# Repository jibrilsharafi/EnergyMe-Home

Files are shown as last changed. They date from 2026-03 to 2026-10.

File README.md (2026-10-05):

#  EnergyMe-Home

<div align="center">

Coverage

<h3>🛒 Want it ready to use? Pre-assembled and calibrated units. Just install and monitor!</h3>

Available on our <a href="https://www.energyme.net/shop">website</a> and on <a href="https://www.tindie.com/stores/energyme/">Tindie</a>

   <a href="https://certification.oshwa.org/it000025.html">OSHWA Certified Open Source Hardware IT000025</a>

</div>

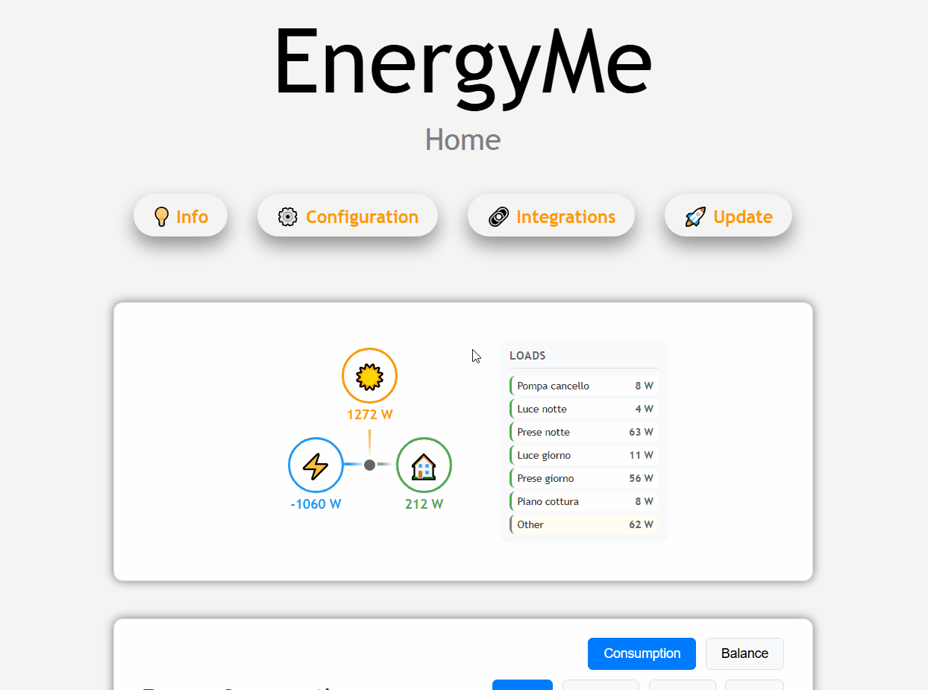
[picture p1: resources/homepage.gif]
Homepage


*EnergyMe-Home* is an open-source energy monitoring system for home use, capable of monitoring up to 16 circuits. It integrates with any platform through REST API, MQTT, Modbus TCP, and InfluxDB.

Built for makers and DIY enthusiasts who want to track their home's energy consumption. The hardware uses ESP32-S3 and ADE7953 energy measurement IC, while the firmware is written in C++ with PlatformIO and Arduino framework. You can build and customize it yourself - all hardware designs and software are open-source. Prefer it ready to go? Grab a [pre-assembled unit](https://www.energyme.net/shop).

> A demo speaks more than 1000 words: try the [demo dashboard](https://demo-energyme-home.energyme.net)!

> **Join the community!** Head over to [GitHub Discussions](https://github.com/jibrilsharafi/EnergyMe-Home/discussions) - ask questions, share your builds and dashboards, suggest features, and exchange integration tips. It's the home for everyone building, installing, or tinkering with EnergyMe-Home

## Supported Electrical Systems

EnergyMe-Home is compatible with various electrical systems worldwide:

| System Type | Voltage | Configuration | Supported |
|---|---|---|---|
| **Single Phase** | 230V | L + N | ✅ Europe, Asia, Africa, Oceania |
| **Split Phase** | 120V/240V | L1 + L2 + N | ✅ North America residential |
| **Split Phase** | 120V/240V | L1 + L2 (no N) | ✅ Old electrical systems |
| **Three Phase** | 400V/230V | 3L + N | ❕ Europe commercial/industrial (derived voltages) |
| **Three Phase** | 208V/120V | 3L + N | ❕ North America commercial (derived voltages) |

**Current Transformers Supported:**

- 333 mV output CTs (+- 500 mV absolute)
- 3.5 mm jack connectors for easy plug-and-play

**Monitoring Capacity:**

- Up to **16 circuits** simultaneously
- 1× main circuit, sampled at high frequency for accurate total energy measurement
- 15× branch circuits, multiplexed for individual monitoring

⚠️ **Important**: Installation requires working with your main electrical panel. Always consult a qualified electrician if you're not experienced with electrical installations. The user is responsible for ensuring compliance with local electrical codes and regulations, and assumes all risks associated with the installation and use of this device.

## Hardware

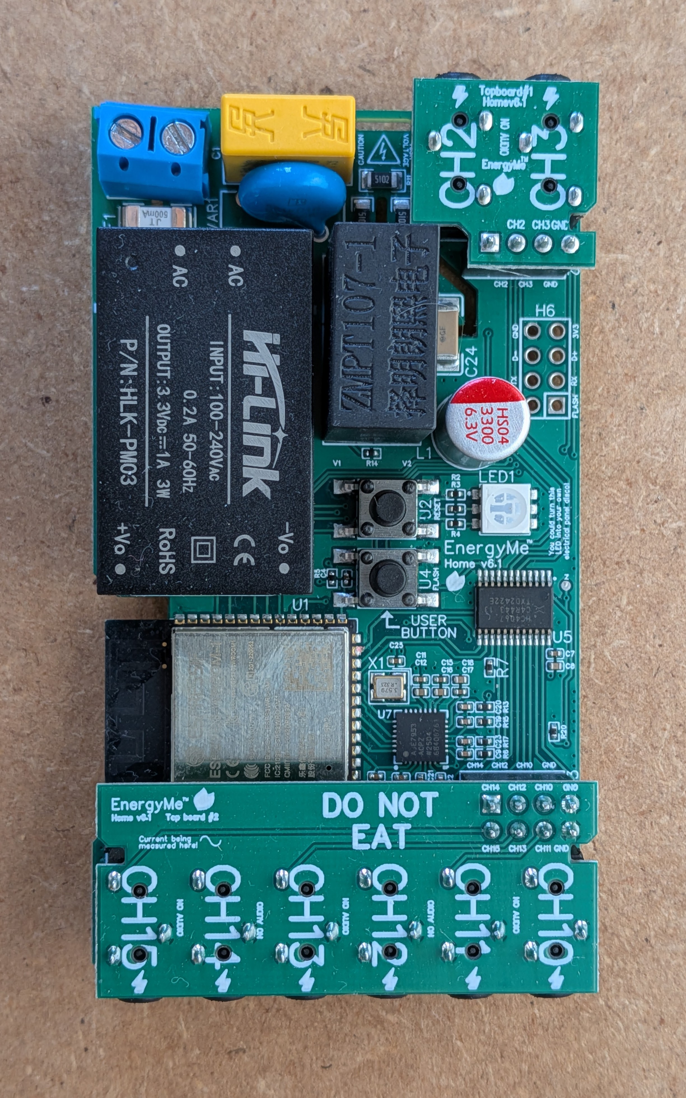
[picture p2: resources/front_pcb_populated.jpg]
PCB front

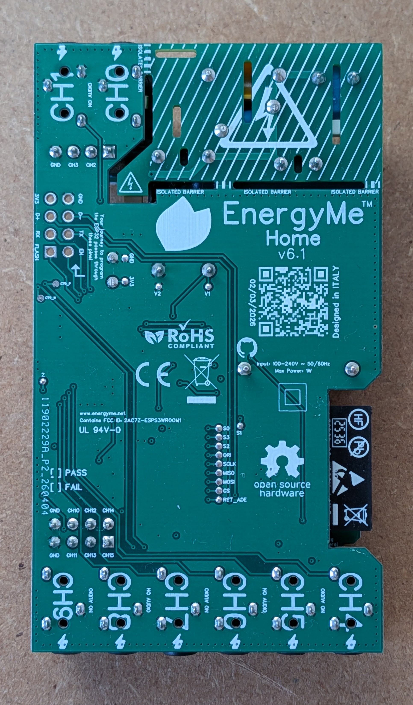
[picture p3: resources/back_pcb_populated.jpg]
PCB back


The hardware (currently at **v6.1**) consists of both the PCB design and the components used to build the energy monitoring system.

The key components include:

- **ESP32-S3**: the brain of the project
- **ADE7953**: single-phase energy measurement IC
- **ZMPT107-1**: voltage transformer providing **full galvanic isolation** between the AC mains and the low-voltage measurement circuitry, with no direct connection between mains and the board's ground
- **Multiplexers**: used to monitor multiple circuits at once
- **3.5 mm jack connectors**: used to easily connect current transformers

PCB schematics and BOMs are available in the `hardware/pcb` directory, while datasheets for key components are in the `hardware/components` directory. Additional hardware specifications and technical details can be found in the [`hardware/README.md`](hardware/README.md), with a condensed one-page summary in the [PCB & Firmware Datasheet](hardware/datasheet.md).

The project is published on *EasyEDA* for easy access to the PCB design files. You can find the project on [EasyEDA OSHWLab](https://oshwlab.com/jabrillo/multiple-channel-energy-meter).

## Software

The firmware is built with C++ using the *PlatformIO* ecosystem and *Arduino 3.x framework*, with a **task-based architecture using FreeRTOS**.

**Key Features:**

- **Energy Monitoring**: ADE7953 driver with energy accumulation and CSV logging
- **Channel Roles**: Load, grid, PV, battery, hybrid inverter and bidirectional channels, with automatic CT reversal detection
- **Web Interface**: Dashboard for monitoring and system configuration
- **Authentication**: HTTP Digest with forced default-password change and brute-force lockout
- **Integration Options**: REST API, MQTT, InfluxDB, and Modbus TCP
- **Crash Recovery**: Automatic recovery, firmware rollback and core dump archive
- **WiFi Setup**: Captive portal for configuration and mDNS support (`energyme.local`)
- **OTA Updates**: Firmware updates with MD5 verification and rollback (cloud updates are signature-verified)
- **Device Health**: Issue registry (CT polarity, over-temperature, ...) and grid blackout detection
- **Waveform Analyzer**: Capture high-resolution voltage & current waveforms per channel from the web UI

For detailed architecture, implementation details, and API documentation, see [`source/README.md`](source/README.md).

## Integration

EnergyMe-Home offers multiple integration options:

- **REST API**: Complete Swagger-documented API for all data and configuration ([swagger.yaml](source/resources/swagger.yaml))
- **MQTT**: Publish energy data to any MQTT broker with optional authentication
- **Modbus TCP**: Industrial protocol for SCADA systems integration
- **InfluxDB**: Support for both v1.x and v2.x with SSL/TLS and buffering
- **Home Assistant**: Dedicated custom integration ([homeassistant-energyme](https://github.com/jibrilsharafi/homeassistant-energyme))

For detailed integration guides and implementation details, see the [source README](source/README.md).

## Home Assistant Integration

EnergyMe-Home integrates with Home Assistant through a dedicated custom integration.

Home Assistant Integration

- **Setup**: Requires device IP address (automatic discovery via mDNS coming soon)
- **Data**: All energy measurements and system information as Home Assistant entities
- **Access**: Monitor all circuits and aggregate data within Home Assistant

Get started at [homeassistant-energyme](https://github.com/jibrilsharafi/homeassistant-energyme).

## Getting Started

1. **Order the PCB**: Download the design files from the [Schematics folder](hardware/pcb/) and order from your preferred PCB manufacturer
2. **Populate the board**: Solder all components using the BOMs in `hardware/pcb/main_board/`, `hardware/pcb/top_board_1/`, and `hardware/pcb/top_board_2/`
3. **Flash the firmware**: Connect a USB-to-UART adapter to the UART pins and flash using PlatformIO
4. **Configure WiFi**: Power on the device and connect to the captive portal to set up WiFi credentials
5. **Start monitoring**: Access the web interface at `http://energyme.local` (default credentials: *admin*/*energyme*, you will be asked to change the password at first login)

For detailed build instructions and troubleshooting, see the [manual](manual/README.md).

## Privacy & Telemetry

Optional anonymous usage statistics sent once per boot: hashed device ID, firmware version, country/city (from public IP). Helps count active installations. No personal data or usage patterns collected. Disable in `platformio.ini`: set `ENABLE_OPEN_SOURCE_TELEMETRY=0`.

## Releases

Firmware binaries and per-version release notes are published on [GitHub Releases](https://github.com/jibrilsharafi/EnergyMe-Home/releases). See [CHANGELOG.md](CHANGELOG.md) for an index of versions and links to the corresponding pull requests.

## Contributing

Contributions are welcome! Please read the [contributing guidelines](CONTRIBUTING.md) for more information.

## License

This project contains both software and hardware components:

- **Software**: Licensed under the [GNU General Public License v3.0](LICENSE) (GPL-3.0)
- **Hardware**: Licensed under the [CERN Open Hardware Licence Version 2 - Strongly Reciprocal](LICENSE-HARDWARE) (CERN-OHL-S-2.0)

See the respective license files for full details.

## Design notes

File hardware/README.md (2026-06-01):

# EnergyMe-Home Hardware Documentation

This document provides detailed hardware specifications and technical information for the EnergyMe-Home PCB design. For general project information, software features, and integrations, see the [main README](../README.md). For a condensed one-page specification of the PCB and firmware, see the [PCB & Firmware Datasheet](datasheet.md).

Now, take a look at these beautiful renderings of the PCB design before diving into the technical details:

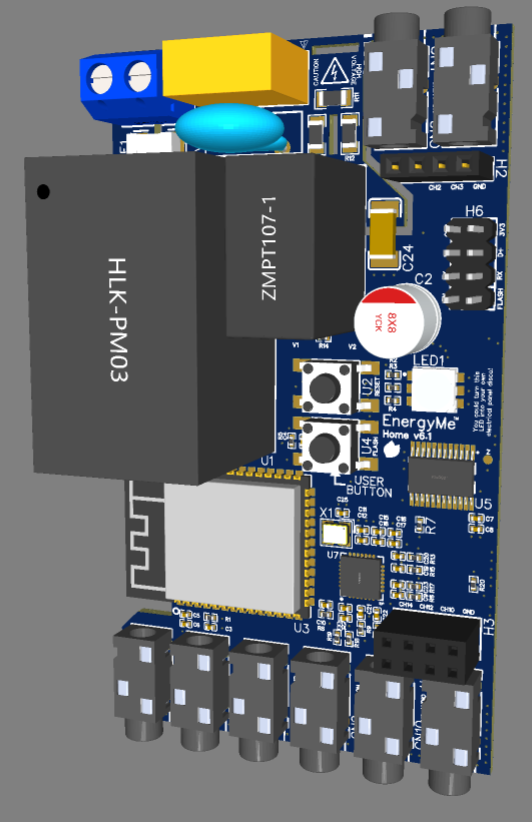
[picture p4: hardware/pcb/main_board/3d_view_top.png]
3D View Top

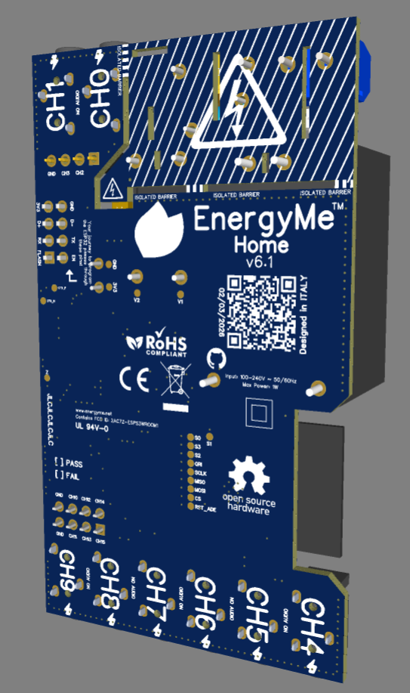
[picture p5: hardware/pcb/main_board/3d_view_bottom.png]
3D View Bottom


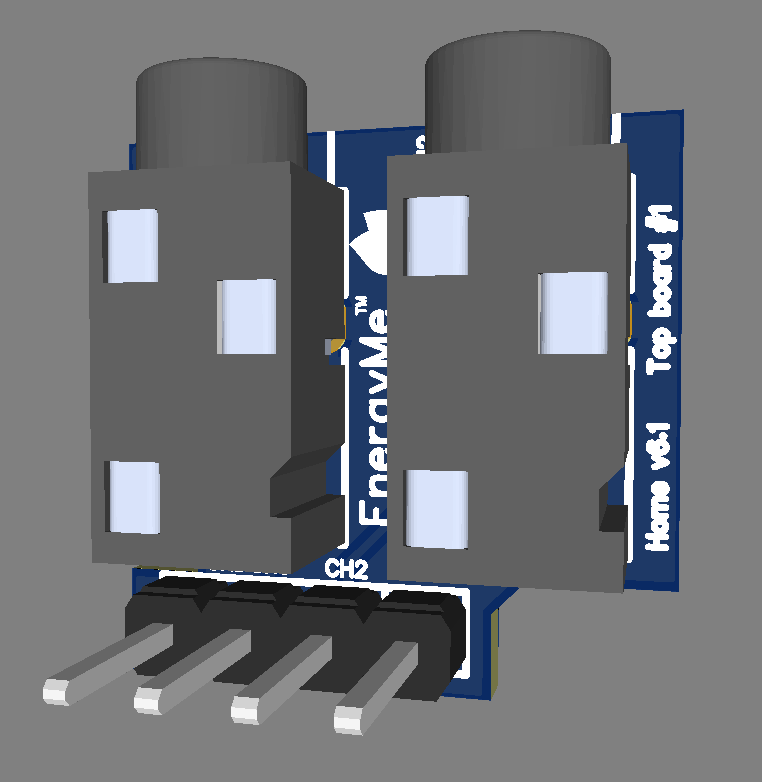
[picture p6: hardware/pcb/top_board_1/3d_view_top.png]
3D View Top - Top Board 1

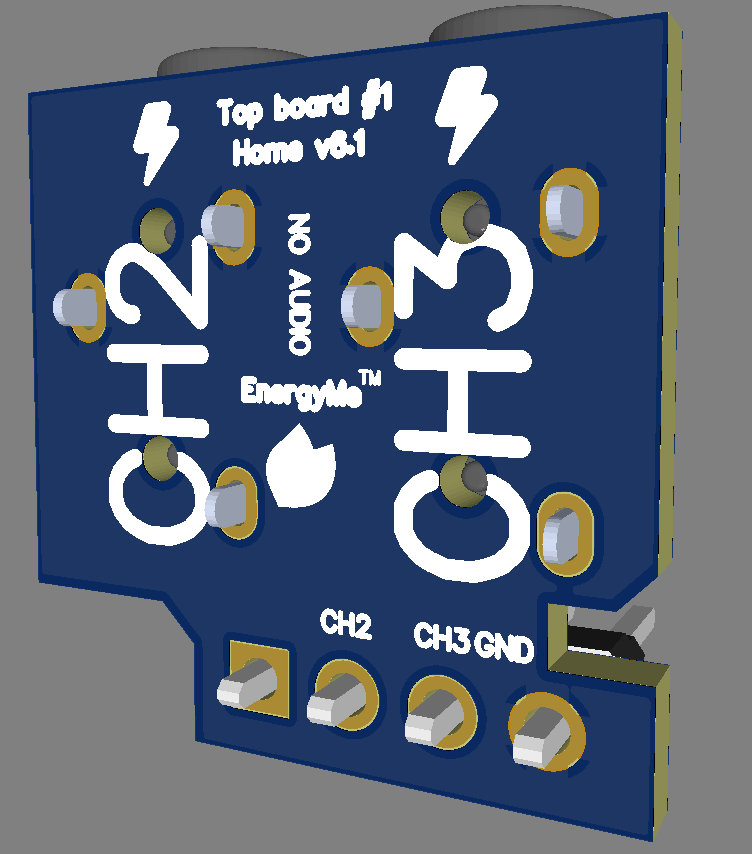
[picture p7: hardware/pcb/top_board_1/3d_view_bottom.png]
3D View Bottom - Top Board 1


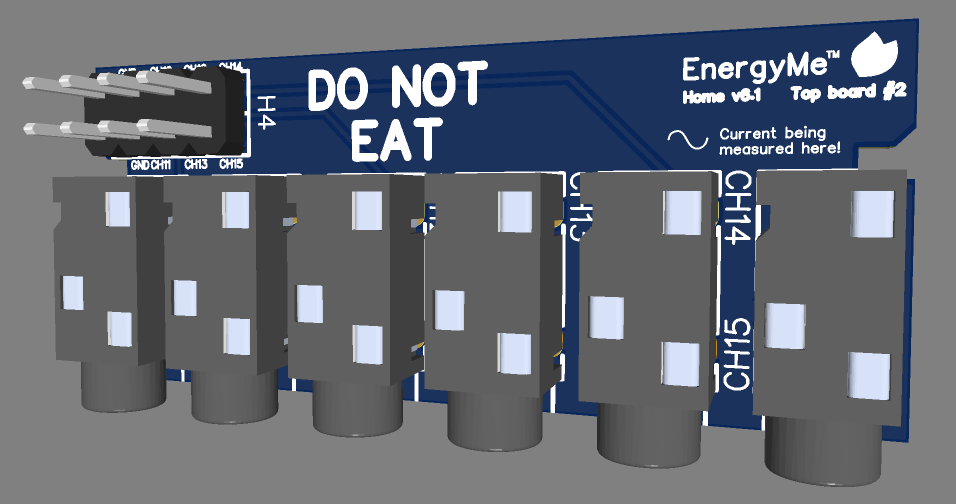
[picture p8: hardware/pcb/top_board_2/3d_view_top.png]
3D View Top - Top Board 2

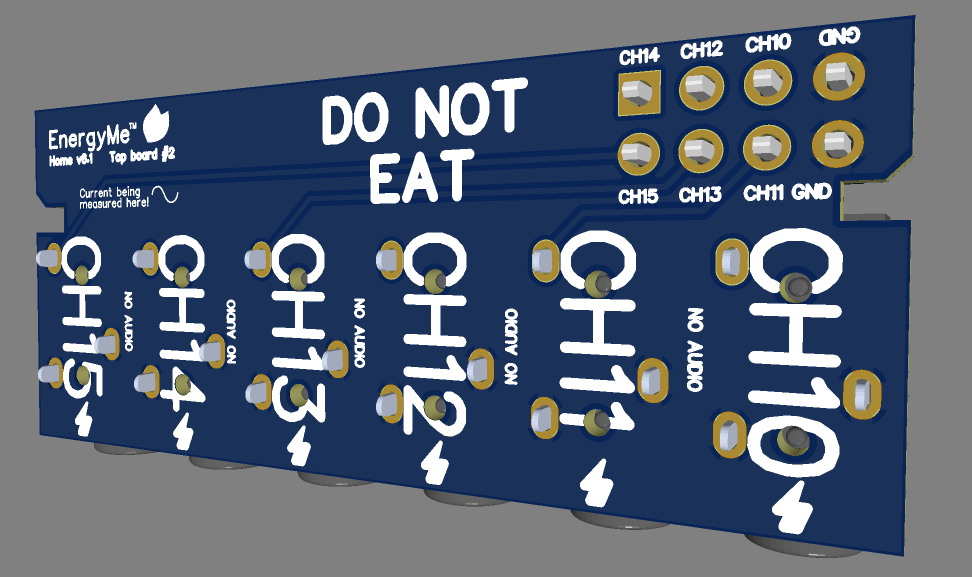
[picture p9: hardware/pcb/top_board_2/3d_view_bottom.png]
3D View Bottom - Top Board 2


## Hardware Specifications

**Board Information:**

- **Hardware Revision:** v6.1
- **PCB Layers:** 4 layers
- **Board Dimensions:** 87 mm x 50 mm. Height with components around 15 mm
- **Power Consumption:** ~200 mA @ 3.3V typical (~ 1W AC consumption)

**Key Components:**

- **Main Microcontroller:** ESP32-S3-WROOM-1-N16R2 (dual-core, WiFi 2.4 GHz, 16MB Flash, 2MB PSRAM)
- **Energy Measurement IC:** Analog Devices ADE7953ACPZ-RL (single-phase, dual-channel)
- **ADE7953 Oscillator:** 3.58 MHz active SMD oscillator (RO03579043), more compact than a crystal+load-cap pair and requiring no additional passive components
- **Analog Multiplexer:** 74HC4067PW,118 (16-channel, TSSOP-24)
- **CT Inputs:** 16× PJ-3200 3.5mm stereo jacks (1 direct + 15 multiplexed). The plastic housing prevents shorts when stacking the expansion boards on top of the main board.
- **Voltage Transformer:** ZMPT107-1 for AC mains reference with full galvanic isolation
- **Power Supply:** HLK-PM03 AC/DC module (100-240 VAC to 3.3 VDC, 1A max)

**ESP32-S3 Module Compatibility Notes:**

The design uses ESP32-S3-WROOM-1-N16R2 with quad PSRAM (2MB). Other ESP32-S3 variants may work with `platformio.ini` and partition adjustments, but note:

- **N16R8 (8MB Octal PSRAM)**: Octal PSRAM uses GPIOs 35, 36, 37 and such pins are not used for this exact reason, thus making it compatible with the current design. However, the firmware is not tested on this variant yet.
- **N16R0, N8R0, N4R0 (No PSRAM)**: May work with firmware adjustments but not tested - PSRAM used for queues and JSON documents throughout the code
- **N16R2, N8R2, N4R2 (2MB Quad PSRAM)**: Should work with partition table adjustments. Compiled firmware ~2MB (see [issue #21](https://github.com/jibrilsharafi/EnergyMe-Home/issues/21))

## Circuit Design Overview

### 1. Power Supply Unit

The *HLK-PM03* AC/DC module provides isolated 3.3V DC from universal AC input (100-240 VAC, 50-60 Hz). It is suitable for any region and more than enough for the low power requirements of the board.

The power supply section includes:

- **Protection components**
  - Fuse (500 mA slow-blow) on the AC line for overcurrent protection
  - Varistor (MOV) for surge protection
  - PCB slots for physical isolation and safety compliance
- **EMI suppression components**
  - Class X2 100nF film capacitor across the AC line for mains EMI suppression
  - Large 3300µF bulk capacitor on the DC rail for hold-up time after grid loss, allowing the ADE7953 to detect missing voltage reference and for the firmware to dispatch a last-gasp MQTT message before power fails.
  - SMD 1 nF capacitor on the secondary side of the voltage transformer to stitch the floating output to analog ground, suppressing common-mode noise introduced by the isolation barrier

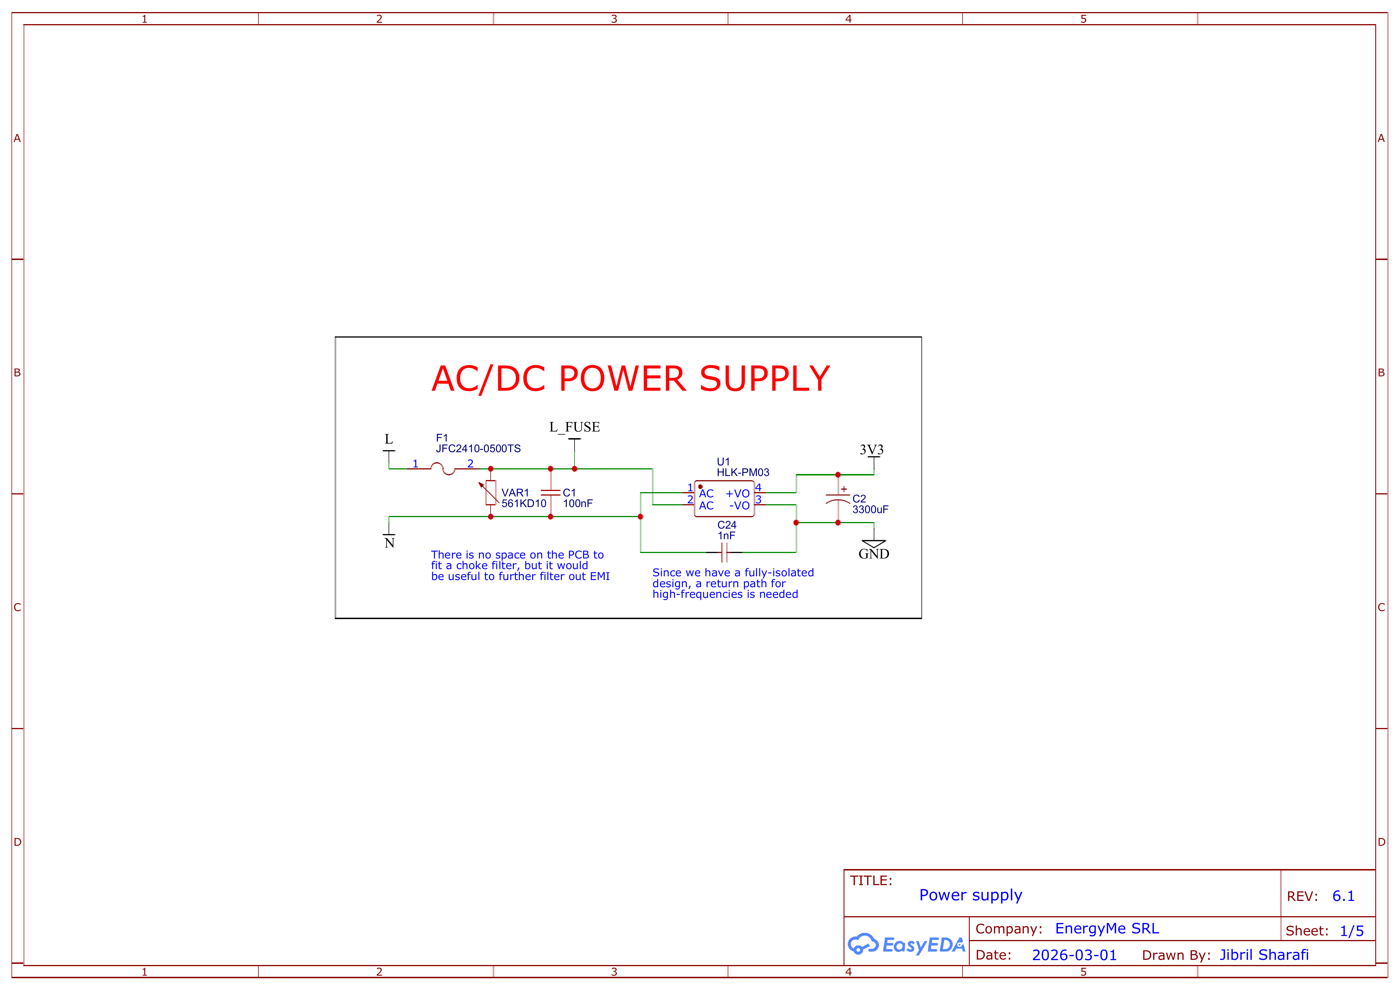
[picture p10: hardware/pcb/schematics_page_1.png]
Power Supply


### 2. Microcontroller (ESP32-S3)

*ESP32-S3-WROOM-1-N16R2*: the central processing unit managing all digital logic, SPI communication with ADE7953, multiplexer control, LED control, and wireless connectivity. *The beast*.

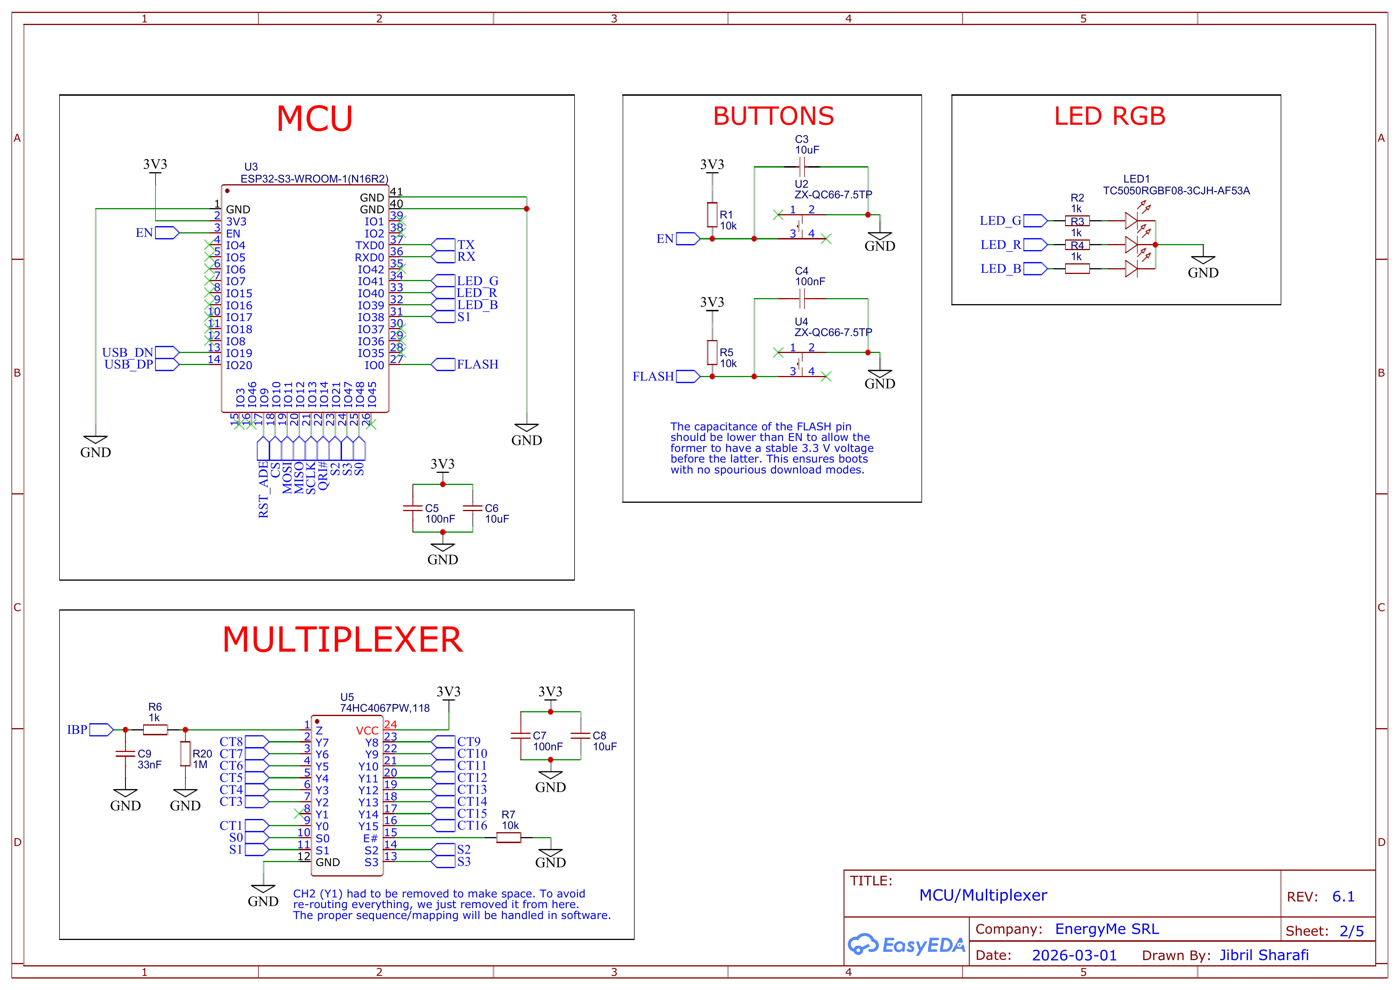
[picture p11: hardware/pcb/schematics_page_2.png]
ESP32-S3


### 3. Energy Measurement (ADE7953)

High-precision 24-bit energy metering IC (*ADE7953ACPZ-RL*) with dual current channels (A and B), clocked by a 3.58 MHz active SMD oscillator, and low-pass filters on all analog inputs (1 kΩ / 33 nF). Key features:

- **Voltage Input:** AC mains reference via ZMPT107-1 voltage transformer (full galvanic isolation)
- **Channel A:** Direct CT input for main circuit monitoring (usually the grid in single phase systems)
- **Channel B:** Multiplexed input from 15 branch circuits
- **Communication:** SPI interface to ESP32-S3 at 2 MHz, with an interrupt line for data-ready notifications (IRQ)

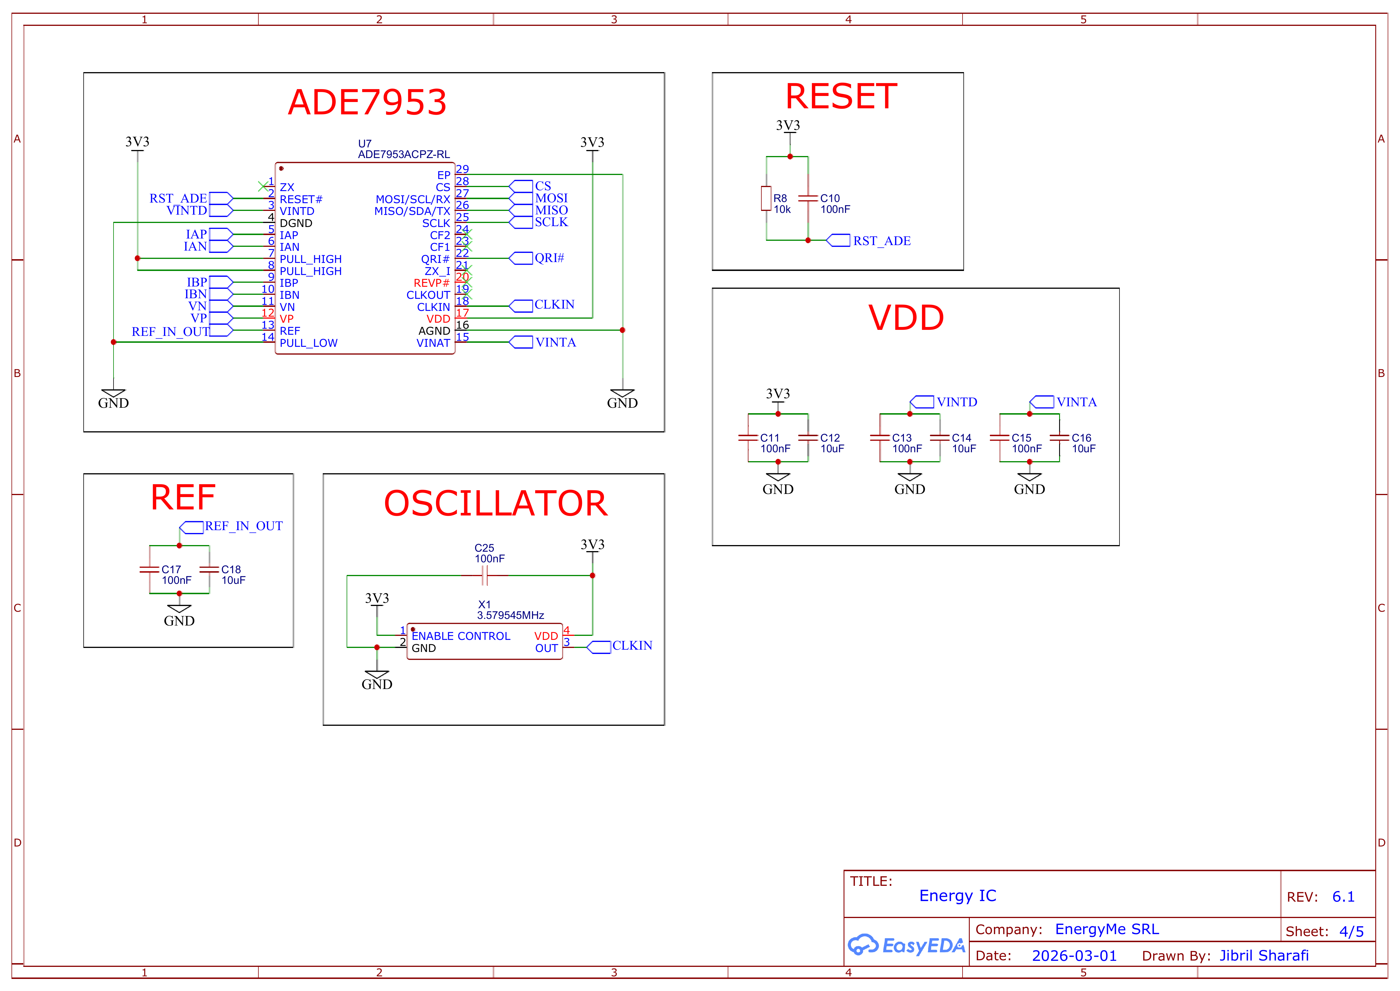
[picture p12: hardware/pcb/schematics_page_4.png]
ADE7953


### 4. Analog Multiplexing

*74HC4067PW,118* multiplexer routes one of 15 CT signals to ADE7953 Channel B. ESP32-S3 controls select lines (S0-S3) for sequential measurement. Supports +- 0.5 V relative to ground, which is sufficient for voltage-output CTs (max 333 mV).

Multiplexer

### 5. CT Interface & Other Inputs

All 16 CT inputs use PJ-3200 3.5mm stereo jacks with direct connection through low-pass filters (1 kΩ / 33 nF). **Maximum CT output: 333 mV**. No burden resistors are present on the board. 1 MΩ resistors are placed on the CT inputs to guarantee 0 V readings on the ADE7953 when no CT is connected, preventing floating inputs from causing spurious measurements. The PJ-3200 plastic housing is important when stacking the top expansion boards on top of the main board, as it prevents accidental shorts between the jack body and the board above.

The line voltage is fed to the ZMPT107-1 voltage transformer via a 2.54mm 2-pin screw terminal block, rated for 300V/3A.

The programming header is a standard 2x4 2.54mm pin header, comprising of 3V3, GND, EN, IO0, TX, RX, D+, D- pins.

Two more headers are available for expanding the CT inputs up to 16 total channels (the bare board has 8 channels).

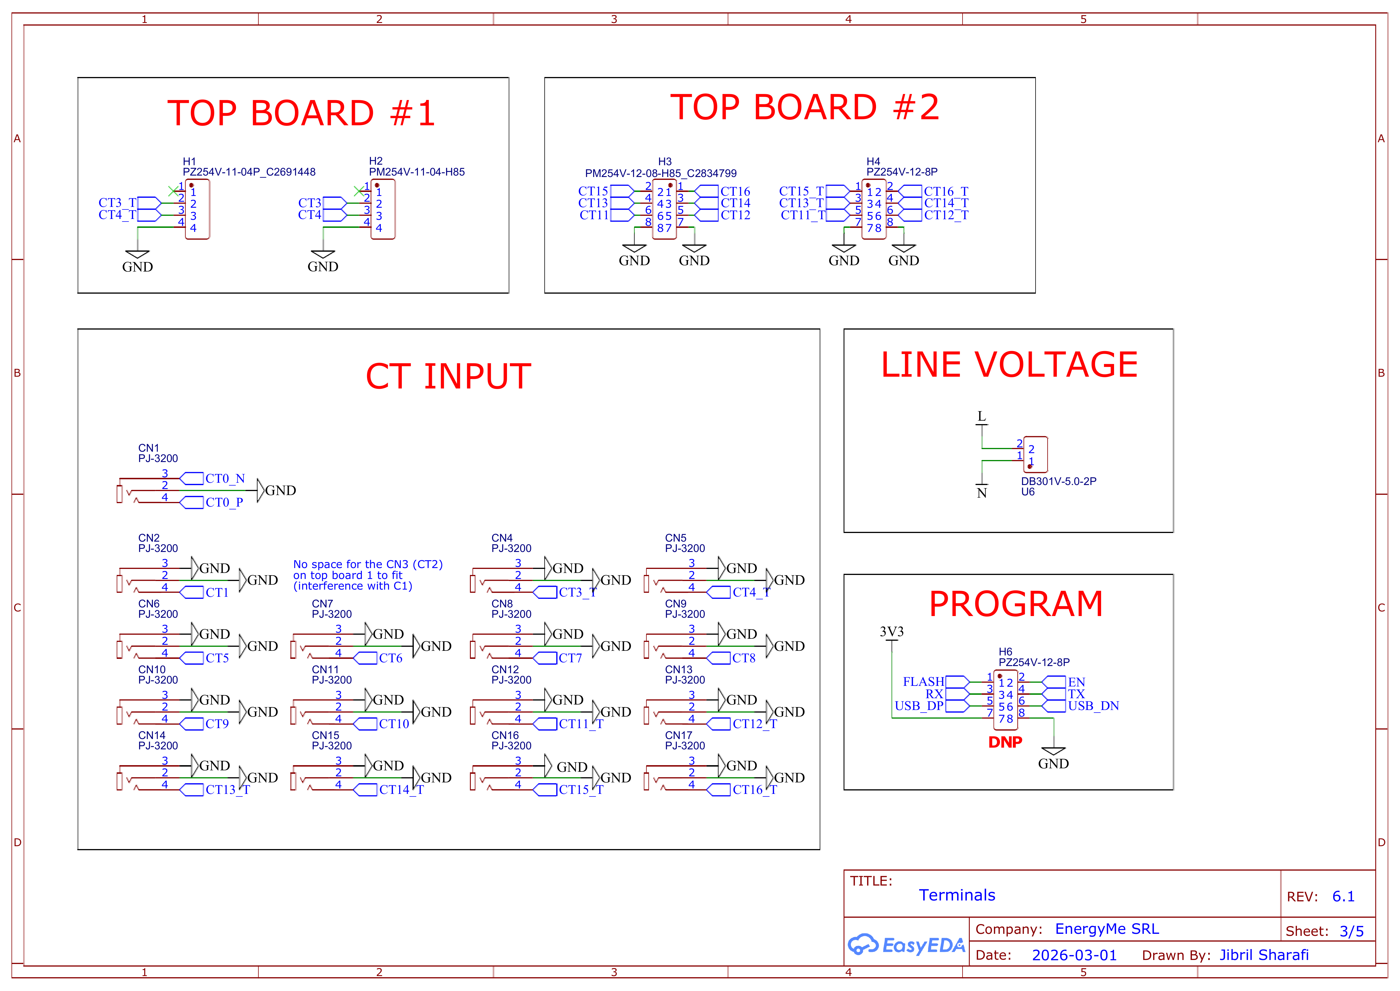
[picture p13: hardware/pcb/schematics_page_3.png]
ADE7953 signal inputs


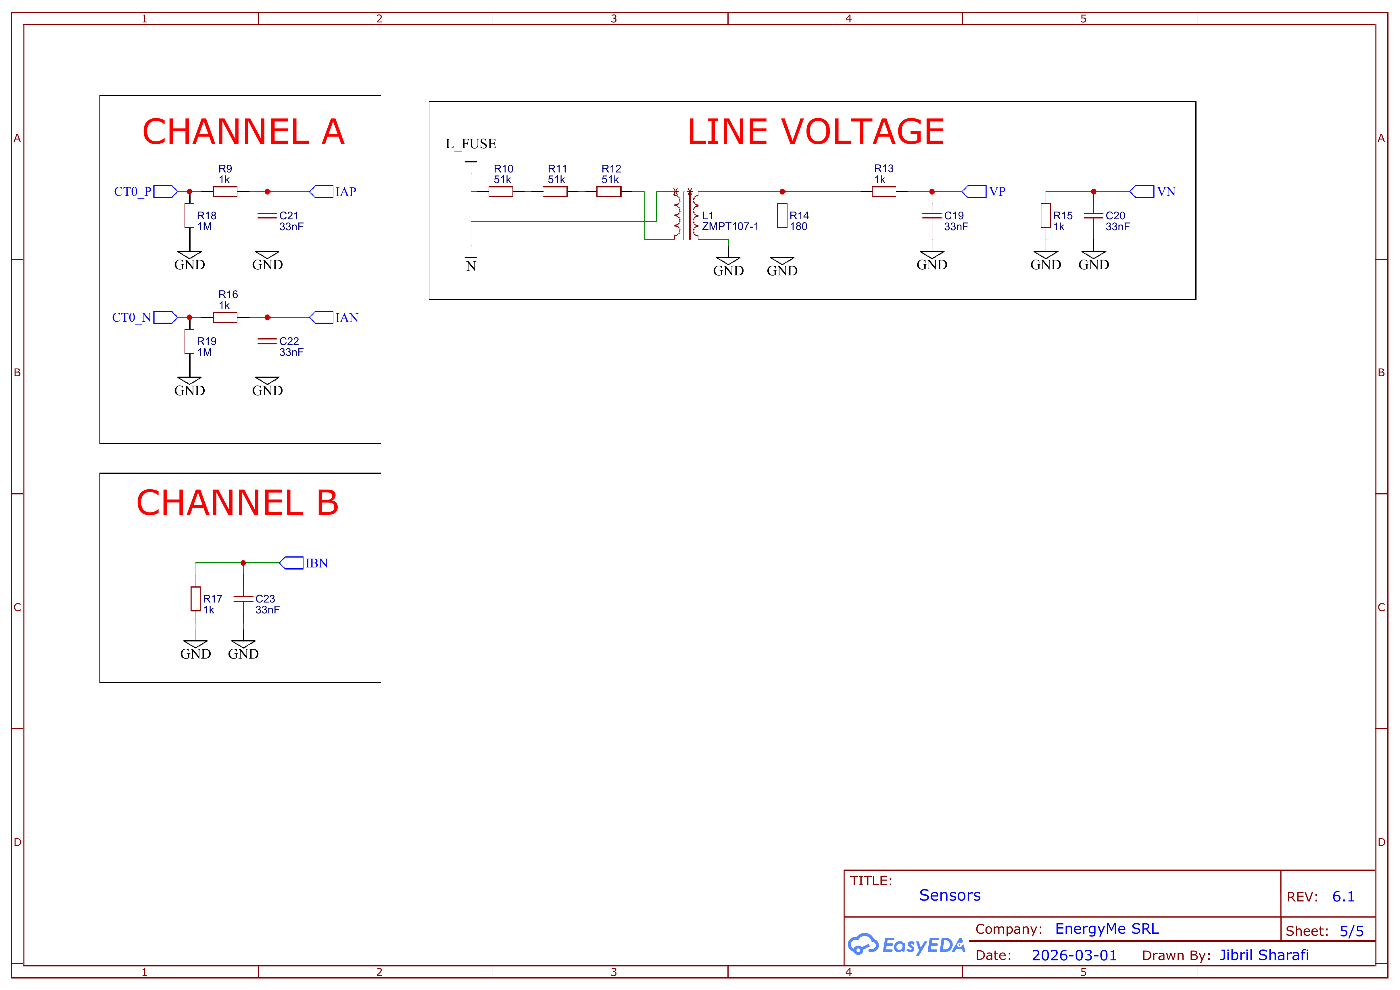
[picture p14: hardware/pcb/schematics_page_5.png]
CT Interface


## PCB Layout & Design

The main board features a **4-layer PCB** design. The components, present only on the top side, are both SMD and through-hole, with the majority being SMD for compactness.

**Layer Stack-up:**

- **Layer 1 (Top):** Signal routing, components
- **Layer 2:** Ground plane (continuous pour for low impedance)
- **Layer 3:** Power plane (3.3V distribution)
- **Layer 4 (Bottom):** Signal routing

**Component Placement:**

- **Power section** isolated on top-left side with HLK-PM03 AC/DC module and ZMPT107-1 voltage transformer
- **ESP32-S3** positioned on the left side, leaving a slot under the PCB antenna on the module to improve WiFi performance
- **ADE7953** placed close to the ESP32-S3 to minimize SPI trace lengths
- **Multiplexer** positioned close to the ADE7953 to reduce analog signal path lengths
- **CT jacks** arranged in rows along board edges for easy access
- **RGB LED** near the center for status indication
- **Tactile buttons** for user input located at the center for easy access
- **Programming header** located at the center for easier access
- **Expansion headers** near the CT jacks for additional channels

**Main Board Layout:**

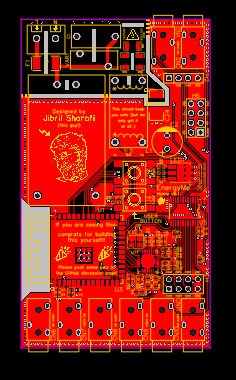
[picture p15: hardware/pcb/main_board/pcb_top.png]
PCB Top


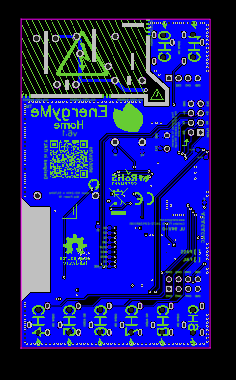
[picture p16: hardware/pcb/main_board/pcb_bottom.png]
PCB Bottom


## Design Files & Resources

All design files (PCB layouts, BOMs, Gerber files, Pick-and-Place files) are grouped by board (main_board, top_board_1, top_board_2), while the schematics are provided in a single PDF.

- **EasyEDA Project:** [OSHWLAB | EnergyMe - Home](https://oshwlab.com/jabrillo/multiple-channel-energy-meter)
- **Schematics:** `pcb/schematics.pdf` (PNG pages: `pcb/schematics_page_1.png` to `pcb/schematics_page_5.png`)
- **BOM:** `pcb/main_board/bom_main_board.csv`, `pcb/top_board_1/bom_top_board_1.csv`, `pcb/top_board_2/bom_top_board_2.csv`
- **Gerber Files:** `pcb/main_board/gerber_main_board.zip`, `pcb/top_board_1/gerber_top_board_1.zip`, `pcb/top_board_2/gerber_top_board_2.zip`
- **PCB Layout PDFs:** `pcb/main_board/pcb_main_board_top.pdf`, `pcb/main_board/pcb_main_board_bottom.pdf`, `pcb/top_board_1/pcb_top_board_1_top.pdf`, `pcb/top_board_1/pcb_top_board_1_bottom.pdf`, `pcb/top_board_2/pcb_top_board_2_top.pdf`, `pcb/top_board_2/pcb_top_board_2_bottom.pdf`
- **Pick-and-Place Files:** `pcb/main_board/pick_and_place_main_board.csv`, `pcb/top_board_1/pick_and_place_top_board_1.csv`, `pcb/top_board_2/pick_and_place_top_board_2.csv`
- **EasyEDA Backup:** `pcb/backup_easy_eda/` (schematic and PCB JSON files)
- **Component Datasheets:** Available in `components/` directory

## Hardware Versions and Compatibility

Firmware 2.0.0 selects its hardware profile at runtime from the NVS key `factory_ns::pcb_revision`, matched against the entries in `source/src/hardware_profile.cpp::PCB_PROFILES[]`.

- **v6.1** (current production): 16 channels (1 direct + 15 multiplexed via 74HC4067), ZMPT107-1 voltage transformer.
- **v5 and earlier**: not supported by 2.0.x firmware. Existing v5 devices stay on the 1.x line; critical fixes are cherry-picked to the `legacy/v5` branch.
- **Community / self-built boards** (no factory NVS provisioning): the firmware falls back to the profile selected by the `-DPCB_VERSION_FALLBACK` build flag in `platformio.ini` (or to `PCB_PROFILES[0]` if unset) and starts in **community mode**: cloud services are disabled, all local integrations (REST API, Modbus TCP, custom MQTT, InfluxDB) remain fully functional.

## Safety Notes

⚠️ **ELECTRICAL SAFETY WARNING**

This device interfaces with AC mains voltage. Construction and installation must only be performed by qualified individuals with proper knowledge of electrical safety. Improper handling can result in serious injury or death.

## Hardware Images

**Top view (bare PCB):**

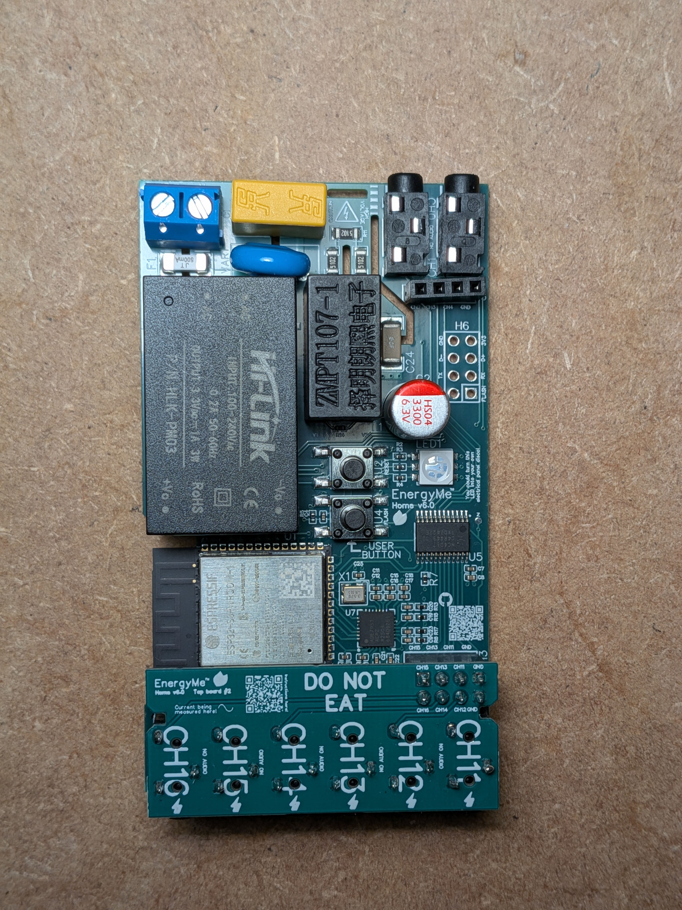
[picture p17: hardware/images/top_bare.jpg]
Top bare


**Bottom view (bare PCB):**

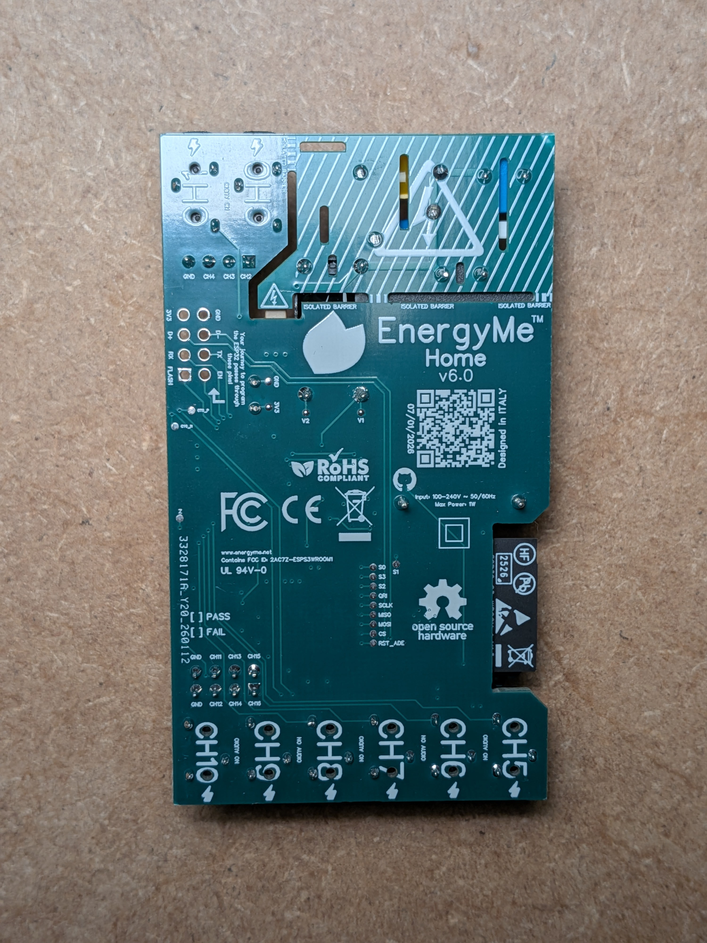
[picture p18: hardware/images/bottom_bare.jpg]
Bottom bare


**Top view (assembled):**

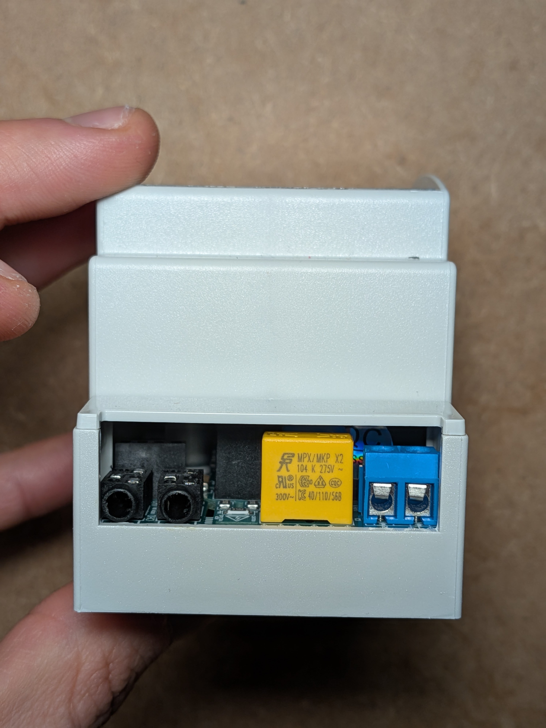
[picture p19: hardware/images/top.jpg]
Top assembled


**Bottom view (assembled):**

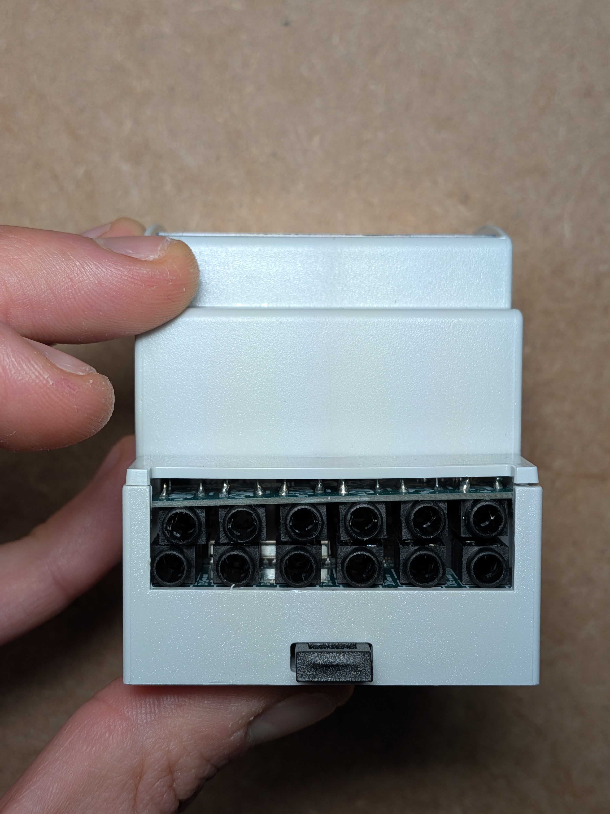
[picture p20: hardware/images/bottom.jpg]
Bottom assembled


**Front:**

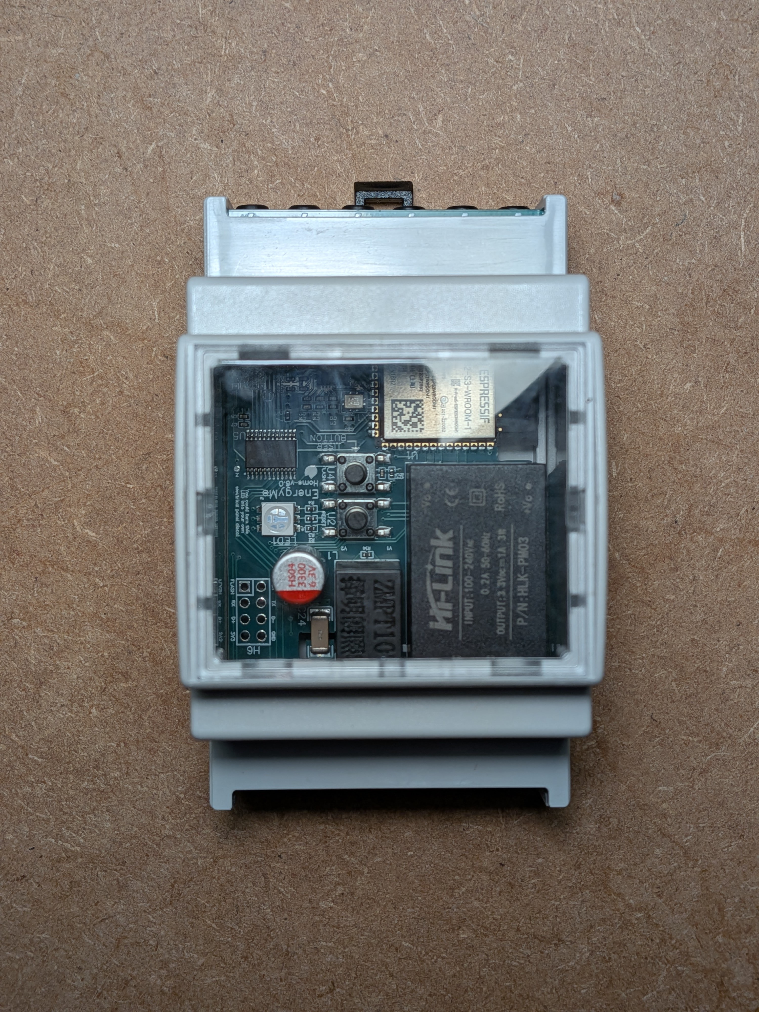
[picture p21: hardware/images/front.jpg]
Front


**Back:**

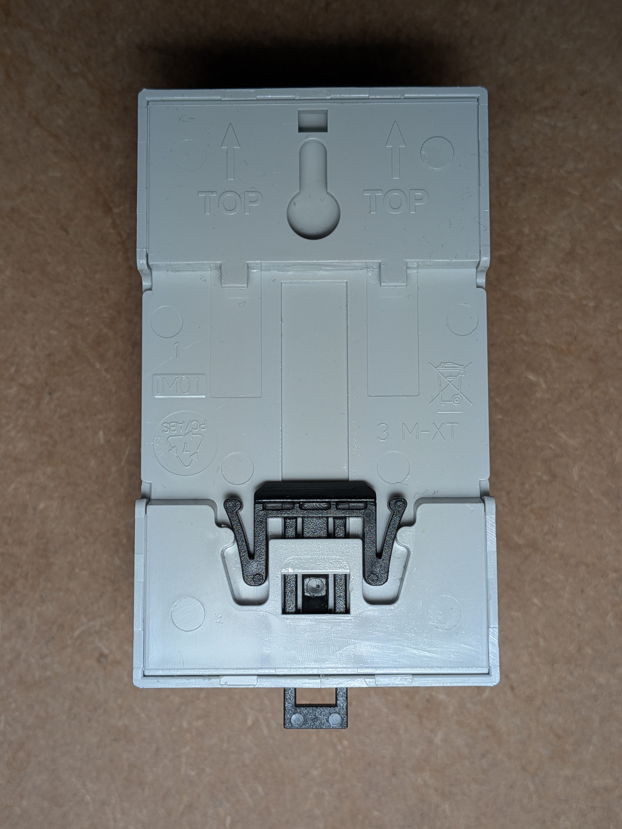
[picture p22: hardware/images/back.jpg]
Back


**Left:**

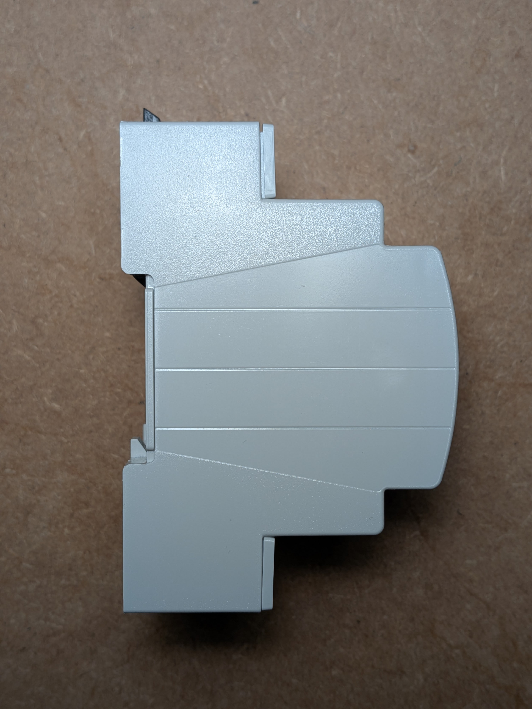
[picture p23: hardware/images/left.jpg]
Left


**Right:**

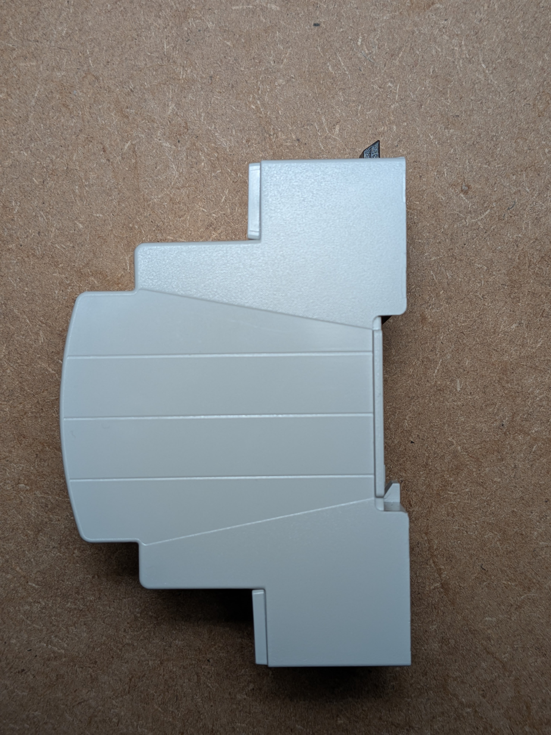
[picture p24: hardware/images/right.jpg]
Right


**With CTs connected:**

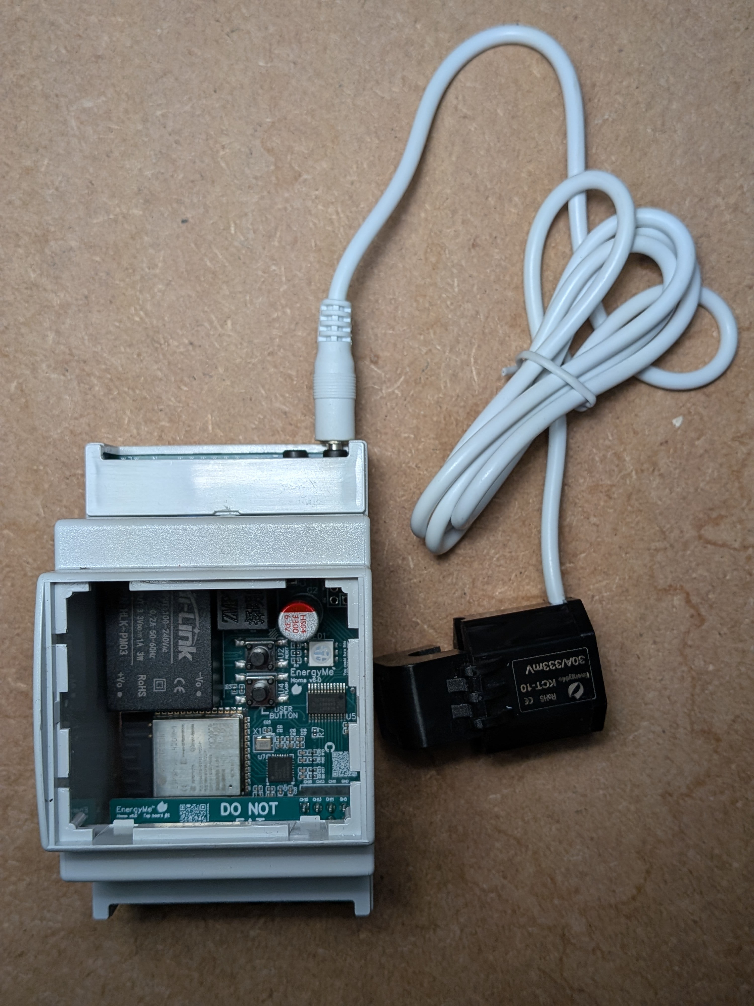
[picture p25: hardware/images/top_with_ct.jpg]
With CTs


**CT jack detail:**

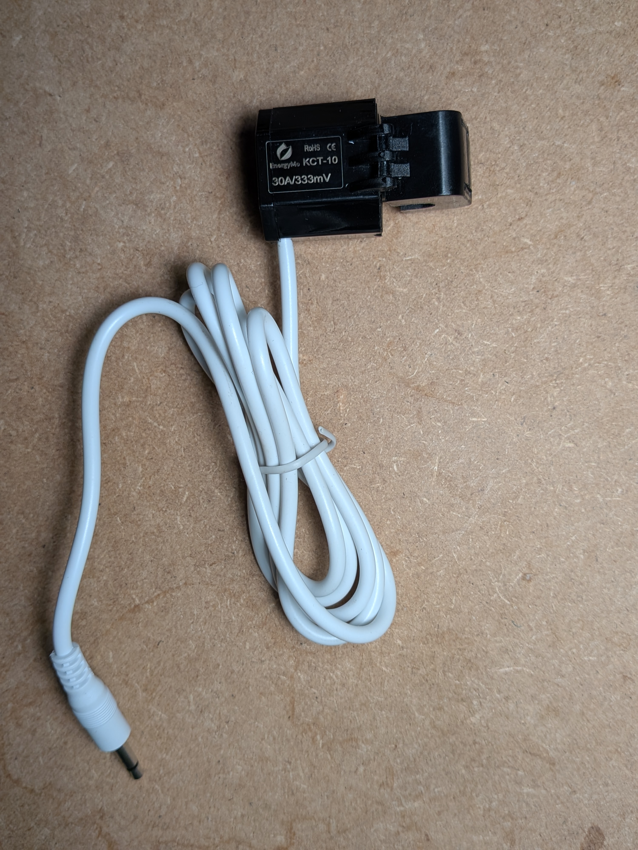
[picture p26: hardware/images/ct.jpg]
CT jack


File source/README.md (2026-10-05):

# EnergyMe - Home | Source Code

**Platform:** ESP32-S3 with Arduino 3.x Framework  
**Hardware Revision:** Selected at runtime via `globalHwProfile` (see `src/hardware_profile.cpp` and `include/hardware_profile.h`).

## System Overview

Task-based energy monitoring system built on FreeRTOS. ESP32-S3 interfaces with ADE7953 energy measurement IC via SPI.

**Monitoring Capabilities:**

- **Channels per product line**: Home 16 (1 direct + 15 multiplexed), Home Pro 12 (W5500 Ethernet)
- **Measurements**: Voltage, current, active/reactive/apparent power, power factor, energy accumulation
- Single voltage reference (channel 0): channels on other lines of a three-phase supply rotate the measured energies by ±120°, assuming a balanced voltage (see `ade7953.cpp`)
- Channel roles (load, grid, PV, battery, inverter, bidirectional) with automatic CT reversal detection
- Calibration with no-load threshold detection

## Architecture

### FreeRTOS Task-Based Design

```cpp
void setup() {
    // Initialize components
    // Start maintenance task
    startMaintenanceTask();
    
    // Delete main task after setup
    vTaskDelete(NULL);
}

void loop() {
    // All work done in dedicated tasks
    vTaskDelay(portMAX_DELAY);
}
```

**Active Tasks:**

- **Maintenance**: System health, memory management
- **ADE7953**: Meter reading, energy saving, CSV logging
- **Network**: WiFi, MQTT clients, web server
- **System**: Crash monitoring, LED control, button handling
- **Storage**: InfluxDB client, UDP logging

### Stability Features

**Crash Monitor - Two-Tier Restart Protection:**

The system implements a hierarchical protection against restart loops to ensure device remains accessible:

#### Tier 1: Safe Mode (Rapid Loop Protection)

- **Trigger**: 5+ restarts within 60 seconds each (20+ in dev mode)
- **Action**:
  - Blocks all restart attempts for 5-minute minimum uptime
  - **All systems remain operational**: WiFi, OTA, web interface, ADE7953, APIs
  - Visual indicator: Purple LED
- **Recovery**: Auto-clears after 30 minutes of stable operation or next restart > 60s uptime
- **Use Case**: Any rapid restart loop condition (software bugs, config issues, etc.)

#### Tier 2: Rollback/Factory Reset (Persistent Failure Recovery)

- **Trigger**: 3+ consecutive crashes OR 10+ consecutive resets (10/30 in dev mode)
- **Action**:
  1. Attempts firmware rollback (if available, once per boot cycle)
  2. Performs factory reset if rollback unavailable or failed
- **Recovery**: Counters reset after 180 seconds of stable operation
- **Use Case**: Bad firmware updates or persistent hardware failures

#### How They Work Together

- Safe mode activates first for rapid loops (prevents OTA lockout, keeps device accessible)
- Crash/reset tracking continues in background
- If failures persist in safe mode → triggers rollback/factory reset
- Independent counter management (timing-based vs stability-based)

#### Additional Features

- RTC memory persistence (survives reboots)
- ESP32 core dump support with backtrace decoding, archived to LittleFS
- Automatic MQTT crash reporting (if configured)

**Device Issues:**

Runtime issue registry (CT polarity mismatch, over-temperature, ...) exposed via API and cloud. Grid blackouts are detected via the ADE7953 zero-crossing timeout and reported before power is lost.

**Memory Management:**

- PSRAM for queues and buffers
- Automatic restart on low heap
- Per-task stack monitoring via TaskInfo

## Core Components

**ADE7953 Driver:**

- Analog Devices ADE7953 single-phase energy measurement IC
- Dual channels: A (direct) and B (multiplexed)
- Line cycle accumulation, no-load detection
- Task-based non-blocking measurement loops
 - Waveform Analyzer: on-demand high-resolution voltage & current captures per channel, accessible from the web UI (`/waveform`) with JSON export for offline analysis. Waveform

**Multiplexer:**

- 74HC4067PW 16-channel analog multiplexer
- Sequential scanning for continuous monitoring
- GPIO control via ESP32-S3 (S0-S3 select lines)

**Web Interface:**

- Responsive UI with real-time updates
- RESTful API with Swagger documentation
- HTTP Digest authentication
- Pages: Dashboard, System Info, Configuration, Channel Setup, Calibration, ADE7953 Tester, Firmware Updates, Logs, API Docs

**Communication:**

- **MQTT**: Dual clients (AWS IoT Core + local broker support)
- **InfluxDB**: Native client for v1.x and v2.x with SSL/TLS and batching
- **Modbus TCP**: Industrial protocol for SCADA integration and other systems

## Code Structure

```text
source/
├── src/                   # Implementation files
│   ├── main.cpp           # Application entry point
│   ├── ade7953.cpp        # Energy IC driver
│   ├── crashmonitor.cpp   # Crash detection and recovery
│   ├── customserver.cpp   # Web server and API
│   ├── custommqtt.cpp     # MQTT clients
│   ├── influxdbclient.cpp # Time-series database client
│   └── ...
├── include/               # Headers
│   ├── constants.h        # System constants
│   ├── structs.h          # Data structures
│   ├── globals.h          # Global declarations
│   └── ...
├── html/                  # Web pages
├── css/                   # Stylesheets
├── js/                    # Client scripts
└── resources/             # Static assets
```

**Key Modules:**

- **System**: `CrashMonitor`, `IssueRegistry`, `Led`, `ButtonHandler`, `CustomTime`
- **Energy**: `Ade7953`, `Multiplexer`
- **Network**: `CustomWifi`, `CustomEth`, `CustomServer`, `Mqtt`, `Shadow`, `CustomMqtt`, `InfluxDbClient`, `ModbusTcp`
- **Storage**: `Preferences API`, `LittleFS`

**Design Principles:**

- Task-based operations with FreeRTOS
- Crash resilience with automatic recovery
- PSRAM utilization and stack monitoring
- Non-blocking operations

## Configuration & Storage

**Preferences (ESP32 NVS):**

- `general_ns`: System settings, device configuration
- `ade7953_ns`: Energy IC parameters
- `energy_ns`: Accumulated energy counters
- `calibration_ns`: Measurement calibration values
- `channels_ns`: Per-channel configuration
- `mqtt_ns` / `custom_mqtt_ns`: MQTT broker settings
- `influxdb_ns`: InfluxDB configuration
- `auth_ns`: Authentication credentials
- `wifi_ns` / `eth_ns`: Network configuration
- `crashmonitor_ns`: Crash recovery settings
- `time_ns`, `led_ns`, `button_ns`, `udp_log_ns`: Module settings
- `factory_ns`: Manufacturing data (certificates, serial, PCB revision), read-only

**LittleFS Files:**

- `/log.txt`: System logs with rotation (max 1000 lines)
- Energy data: Accumulation files for active/reactive/apparent energy
- CSV exports: Hourly data zipped daily (up to 10 years storage)

**Task Monitoring:**

All tasks provide `TaskInfo` structures with stack usage metrics:

- Allocated stack size
- Minimum free stack observed
- Free/used percentage

Monitored tasks: MQTT clients, web server, ADE7953 operations, crash monitor, LED control, maintenance, WiFi, UDP logging, InfluxDB.

## System Specifications

**Monitoring:**

- Up to 16 circuits (Home) or 12 (Home Pro): 1 direct + the rest multiplexed
- Parameters: RMS voltage/current, active/reactive/apparent power, power factor, energy accumulation
- Sampling: Channel 0 every 200ms, others every 400ms minimum (depends on active channels)
- Accuracy: Typically ±1% with proper CT calibration
- Voltage range: 90-265V RMS (universal AC input)
- Current range: Configurable via CT (max CT output: 333mV)

**Hardware:**

- ESP32-S3: Dual-core, 16MB Flash, 2MB PSRAM
- Communication: SPI to ADE7953, I2C available
- Power: <1W via onboard AC/DC converter

**Performance:**

- Update rates: Web (1s), MQTT (5-60s configurable), Modbus TCP (on demand), InfluxDB (batched, configurable)
- **Modbus TCP**: ~200 polls/sec, ~5ms avg response, 100% reliability (1000 consecutive reads). All ~200 registers are readable in ~1s.
- **REST API**: ~150ms avg response across 30+ endpoints, 100% success rate (300 requests)

## API & Integration

**REST API:**  
Swagger documentation at `/swagger.html` covers authentication, system management, energy data access, and configuration.

**MQTT:**  

- AWS IoT Core (certificates loaded from the `factory_ns` NVS partition; no build-time secrets), with named shadows, IoT Commands and signature-verified OTA jobs
- Local broker support with configurable authentication
- TLS/SSL with certificates

**InfluxDB:**  
Both v1.x and v2.x support, line protocol, batch writes, SSL/TLS, retry logic.

**Modbus TCP:**  
FC03/FC04 function codes, register mapping for system info and measurements.

## Security

**Authentication:**
HTTP Digest Authentication (RFC 7616) via ESPAsyncWebServer. Password stored in NVS, with length validation. Failed logins are rate-limited per IP. Local network only.

**Default Credentials:**  
Username: `admin` | Password: `energyme`

⚠️ The password must be changed at first login before the device can be used.

## AWS IoT Integration (Optional)

Device certificates and calibration data are provisioned at manufacturing time into the `factory_ns` NVS namespace. The firmware reads them transparently at boot. No build-time secrets are required.

Devices without factory provisioning (community builds) run in local-only mode. All local integrations (Modbus TCP, CustomMqtt, InfluxDB) remain fully functional.

## Development

**Build:**  
PlatformIO with Arduino 3.x framework on ESP32-S3.

**Dependencies:**  
AdvancedLogger, ArduinoJson, StreamUtils, AsyncTCP, ESPAsyncWebServer, PubSubClient, eModbus

**Tools:**  
Static analysis (cppcheck, clang-tidy), ESP32 core debugging, PSRAM optimization

## Diagnostics

**Crash Analysis:**  
Core dumps, RTC memory persistence, automatic recovery/rollback

**Monitoring:**  
Task stack usage, heap/PSRAM tracking, network status

**Debug Access:**  
Serial (115200 baud), UDP logging, web interface, REST API

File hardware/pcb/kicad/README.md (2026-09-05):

# KiCad projects (derived from the EasyEDA backups)

One KiCad 10 project per board, generated from `../backup_easy_eda/*.json` by
the `kicad3d-easyeda-import` tool of the `energyme-3d` repo and used by it to
build the 3D models (GLB for the web, STEP for mechanical CAD, the assembled
device model).

| Board | Source | Contents |
|---|---|---|
| `main_board/` | `pcb_main_board.json` | 87 footprints, 50 x 87 mm, 8 slots + the DIN clip notch |
| `top_board_1/` | `pcb_top_board_1.json` | CH2/CH3 on header H1, stacks on the main board's H2 |
| `top_board_2/` | `pcb_top_board_2.json` | CH10..CH15 on header H4, stacks on the main board's H3 |

`EASYEDA_MODELS/` next to each board holds the LCSC 3D models (`.wrl` for
KiCad's renderer, `.step` twin for the STEP export) fetched with
easyeda2kicad. They are committed because the EasyEDA API rate-limits and
drops parts over time; U2/U4 (ZX-QC66 buttons) have no model at all.

Regenerate after an EasyEDA change (from the `energyme-3d` checkout):

```bash
uv run kicad3d-easyeda-import --json <this repo>/hardware/pcb/backup_easy_eda/pcb_main_board.json --out <this repo>/hardware/pcb/kicad/main_board/main_board.kicad_pcb
uv run kicad3d-attach-models --board <this repo>/hardware/pcb/kicad/main_board/main_board.kicad_pcb --bom <this repo>/hardware/pcb/main_board/BOM_*.csv
```

The import rewrites Edge.Cuts as outer contour minus the union of the EasyEDA
cutouts; without that KiCad's exporters drop every slot.

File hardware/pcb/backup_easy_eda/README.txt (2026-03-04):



# Project introduction
EnergyMe-Home is an open-source hardware project for a multi-channel energy monitoring system, designed using EasyEDA. This board forms the core of a system capable of detailed electricity consumption analysis for up to 17 circuits. The design prioritizes flexibility, robust measurement capabilities using the ADE7953 IC, and extensive connectivity options managed by an ESP32-S3 microcontroller. All corresponding open-source firmware, detailed documentation, and further project information can be found on GitHub: [https://github.com/jibrilsharafi/EnergyMe-Home](https://github.com/jibrilsharafi/EnergyMe-Home).

# Project function
This hardware design enables the following core functionalities:

*   **Simultaneous Multi-Circuit Energy Measurement:** The PCB is designed to interface with one direct CT (Current Transformer) input and up to 16 additional CT inputs via an onboard analog multiplexing system, all feeding into the ADE7953 energy measurement IC.
*   **Accurate Electrical Parameter Acquisition:** Through the ADE7953 and supporting circuitry, the board is capable of capturing data for:
    *   Voltage RMS (from a single reference input)
    *   Current RMS for each of the 17 channels
    *   Active, Reactive, and Apparent Power
    *   Power Factor
    *   Accumulated Energy
*   **Flexible Connectivity:** The ESP32-S3 provides WiFi for network communication, enabling the firmware to implement:
    *   A web server for configuration and real-time data display.
    *   REST API for external system integration.
    *   MQTT client for data publishing (e.g., to local brokers or cloud platforms).
    *   InfluxDB client for direct time-series database logging.
    *   Modbus TCP server capabilities.
*   **User Interface &amp; Diagnostics:** Onboard RGB LED for status indication, and UART pins for programming and serial debugging.
*   **External CT Interfacing:** Standard 3.5mm jack connectors are provided for easy and secure connection of common current transformers.

# Project Parameters
*   **Main Microcontroller:** ESP32-S3
*   **Energy Measurement IC:** Analog Devices ADE7953
*   **Multiplexer ICs:** 74HC4067PW (16 channels analog multiplexer)
*   **Number of CT Channels:** 1 Direct (for ADE7953 Channel A Current Input), 16 Multiplexed (for ADE7953 Channel B Current Input)
*   **CT Input Type:** Designed for voltage-output CTs (e.g., 333mV at rated current) via 3.5mm audio jacks.
*   **Voltage Reference Input:** Direct connection via 1 MΩ / 1kΩ voltage divider.
*   **PCB Layers:** 4 layers
*   **Board Dimensions:** 87 mm x 50 mm. Height with components around 15 mm
*   **Power Supply:** Onboard AC/DC converter using the same supply as the voltage reference
*   **Communication Interfaces (Hardware):** SPI (for ADE7953), GPIOs (for multiplexer, LEDs), UART (Programming/Serial).
*   **Connectivity (Wireless):** WiFi 2.4 GHz via ESP32-S3.

# Principle analysis (Hardware description)
The EnergyMe-Home hardware is designed to accurately measure and process energy data from multiple circuits. The design can be broken down into the following key sections:

1.  **Power Supply Unit (PSU):**
    *   Discrete component that converts universal voltage (100-240 Vac | 50-60 Hz) to 3.3 Vdc (with up to 1 A output) required by the ESP32-S3, ADE7953, and other logic components. Standard consumption hovers around 100 mA, so AC consumption is            
How to use：

At editor, open the document via: Top menu - File - Open - EasyEDA... , and select the json file, then open it at the editor, you can save it into a project.

如何使用：

打开编辑器，通过：顶部菜单 - 文件 - 打开 - 立创EDA... ，选择 json 文件打开在编辑器，你可以保存文档进工程里面。

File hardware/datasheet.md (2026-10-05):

# EnergyMe-Home: PCB & Firmware Datasheet

Technical specifications for the open-source *EnergyMe-Home* board (hardware **v6.1**) and its firmware. This datasheet covers the PCB and firmware only - the open-source deliverable. Enclosure, supplied current transformers, packaging, and regulatory conformity belong to the assembled commercial product and are out of scope here.

For the circuit design and PCB layout, see the [Hardware reference](README.md). For installation and use, see the [Setup & Usage Guide](../manual/README.md).

---

## 1. Identification

| | |
| --- | --- |
| **Project** | EnergyMe-Home (open-source energy monitor) |
| **Hardware revision** | v6.1 |
| **Open-source certification** | OSHWA `IT000025` |
| **License (firmware)** | GPL-3.0 |
| **License (hardware)** | CERN-OHL-S-2.0 |
| **Repository** | <https://github.com/jibrilsharafi/EnergyMe-Home> |

---

## 2. PCB

| Parameter | Value |
| --- | --- |
| Layers | 4 |
| Dimensions | 87 x 50 mm |
| Height with components | ~15 mm |
| Mounting | Designed for a 3-module DIN-rail enclosure |
| CT inputs | 16 x 3.5 mm stereo jack (PJ-3200) |
| Line input | 2-pin screw terminal, 300 V / 3 A |
| Programming header | 2x4 2.54 mm (3V3, GND, EN, IO0, TX, RX, D+, D-) |
| Expansion headers | 2x, for branch CT channels beyond the base 8 |

Layer stack-up: L1 signal/components, L2 ground plane, L3 3.3 V power plane, L4 signal. Full PCB design files (schematics, gerbers, BOM, pick-and-place) are available under [`hardware/pcb/`](pcb/).

---

## 3. Electrical

| Parameter | Value |
| --- | --- |
| Supply voltage | 100-240 V AC |
| Supply frequency | 50 / 60 Hz |
| Board power consumption | ~1 W typical (~200 mA at 3.3 V) |
| Safety class | Class II (double insulation) |
| Internal fuse | Slow-blow (time-lag), 500 mA |
| Galvanic isolation (voltage measurement) | Yes, via ZMPT107-1 voltage transformer |
| Measurement channels | 16 (1 direct + 15 multiplexed) |
| Channel numbering | 0 (main) ... 15 (branches) |
| Voltage measurement range | Single-phase, nominal 100-240 V AC |
| Current measurement | Via external voltage-output CT, up to CT-rated current |
| CT input safe range | <= 0.5 V at the CT secondary (333 mV nominal) |
| Measurement accuracy | < 1 % typical with calibrated voltage-output CTs |
| Energy accumulation | kWh per channel, with CSV logging |

### 3.1 Supported electrical systems

The metering chain monitors single-phase and (as derived single-phase per leg) three-phase systems:

| System | Voltage | Notes |
| --- | --- | --- |
| Single phase | 230 V (L + N) | Europe, Asia, Africa, Oceania |
| Split phase | 120 / 240 V (L1 + L2 + N) | North America residential |
| Split phase | 120 / 240 V (L1 + L2, no N) | Older electrical systems |
| Three phase | 400 / 230 V (3L + N) | Commercial, derived voltages |
| Three phase | 208 / 120 V (3L + N) | North America commercial, derived voltages |

Three-phase systems are monitored per leg, each on its own channel, against the single measured voltage: off-phase channels are rotated by ±120° assuming a balanced supply. The board is a single-phase metering platform, not a true polyphase meter.

---

## 4. Radio

| Parameter | Value |
| --- | --- |
| Wireless standard | Wi-Fi IEEE 802.11 b/g/n |
| Frequency band | 2.412-2.472 GHz |
| Maximum transmit power | <= 20 dBm (100 mW) ERP |
| Antenna | Internal PCB antenna (ESP32-S3 module) |

---

## 5. Key components

| Block | Component |
| --- | --- |
| Microcontroller | Espressif ESP32-S3-WROOM-1-N16R2 (dual-core, Wi-Fi 2.4 GHz, 16 MB Flash, 2 MB PSRAM) |
| Metering IC | Analog Devices ADE7953 (single-phase, dual-channel, 24-bit), SPI at 2 MHz with data-ready IRQ |
| Metering IC clock | 3.58 MHz active SMD oscillator (RO03579043) |
| Analog multiplexer | NXP 74HC4067PW (16-channel, TSSOP-24) |
| Voltage divider | 1000:1 (1 MOhm / 1 kOhm) for AC line reference |
| Voltage transformer | ZMPT107-1 (full galvanic isolation between mains and measurement circuit) |
| Power supply | HLK-PM03 AC/DC (100-240 V AC -> 3.3 V DC, 1 A max) |

---

## 6. CT interface

The board accepts **voltage-output** current transformers (no on-board burden resistors):

| Parameter | Value |
| --- | --- |
| CT type | Voltage-output (333 mV) split-core, clamp-on |
| Maximum CT output | 333 mV nominal (<= 0.5 V absolute at the secondary) |
| Connector | 16 x PJ-3200 3.5 mm stereo jack (1 direct + 15 multiplexed) |
| Input conditioning | Low-pass filter 1 kOhm / 33 nF; 1 MOhm pulldown to guarantee 0 V with no CT connected |
| Orientation | Auto-detected in firmware (clip direction does not matter) |

CTs are not part of the board; any voltage-output CT within the input range works. Non-standard CTs require a one-time calibration step in the web interface (see [Setup §4.6](../manual/02-setup.md#46-ct-calibration-only-if-using-non-standard-cts)).

---

## 7. Firmware

| Aspect | Value |
| --- | --- |
| Language | C++ |
| Framework | Arduino 3.x (PlatformIO) |
| RTOS | FreeRTOS (task-based architecture) |
| License | GPL-3.0 |

### 7.1 Features

- Energy monitoring per channel (real-time power, RMS voltage and current, power factor, frequency, kWh accumulation)
- Web interface for configuration, monitoring, and integration setup
- Channel roles (load, grid, PV, battery, inverter, bidirectional) with automatic CT reversal detection
- HTTP Digest authentication with forced default-password change and brute-force lockout
- Captive portal for first-time Wi-Fi setup; mDNS service discovery (`energyme.local`)
- Over-the-air firmware updates with MD5 verification and rollback (cloud updates are signature-verified)
- Crash recovery with safe-mode operation
- Device issue registry and grid blackout detection
- 10+ years of hourly local data logging with CSV export
- Per-channel waveform capture (voltage and current) from the web UI

---

## 8. Communication and integration

| Protocol | Notes |
| --- | --- |
| **REST API** | Full Swagger-documented API for data and configuration ([swagger.yaml](../source/resources/swagger.yaml)) |
| **MQTT** | Dual-client: AWS IoT Core + user-defined broker with TLS and authentication |
| **Modbus TCP** | Industrial protocol for SCADA / PLC integration |
| **InfluxDB** | Native client, v1.x and v2.x, with TLS and buffering |
| **mDNS** | Service discovery (`energyme.local`) |
| **Home Assistant** | Dedicated custom integration: [homeassistant-energyme](https://github.com/jibrilsharafi/homeassistant-energyme) |

---

## 9. References

- [Hardware reference and circuit design](README.md)
- [PCB design files](pcb/)
- [Firmware source](../source/README.md)
- [Setup & Usage Guide](../manual/README.md)

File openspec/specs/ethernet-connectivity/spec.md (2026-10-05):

# ethernet-connectivity Specification

## Purpose
Wired networking for Home Pro: W5500 SPI Ethernet bring-up, zero-touch DHCP commissioning, static IP configuration with safety backstops, and arbitration between Ethernet and WiFi so the device is reachable through the best available interface.
## Requirements
### Requirement: A cabled Pro device commissions itself with zero touch

On a product whose profile declares Ethernet, the system SHALL bring up the Ethernet interface at boot and acquire a DHCP lease when a link is present. A device with a link and an address SHALL be network-commissioned without any provisioning step and without raising the SoftAP: every service starts on the Ethernet interface, subject only to the existing first-run web password change (web-authentication spec). Waiting for a lease SHALL NOT extend the existing bounded boot network wait: boot proceeds and the lease is picked up whenever it arrives.

#### Scenario: First boot with cable and DHCP

- **WHEN** a factory-fresh Home Pro boots with an Ethernet cable on a DHCP network
- **THEN** it obtains a lease, services start on the Ethernet interface, the first web visit performs the mandatory password change, and no SoftAP is raised

#### Scenario: First boot with no cable and no WiFi credentials

- **WHEN** a factory-fresh Home Pro boots with no Ethernet link and no stored STA credentials
- **THEN** the SoftAP recovery channel is raised, per the wifi-provisioning raise conditions

#### Scenario: Link up but no DHCP server

- **WHEN** the cable is connected but no lease (or applied static address) is obtained
- **THEN** the interface counts as not serviceable: the SoftAP raise conditions treat the device as unreachable, on the same lifecycle cadence as a failing STA

### Requirement: Ethernet IP configuration is persistent, safe, and recoverable without a UI

The system SHALL support static IP configuration for Ethernet (address, gateway, subnet, DNS) set via the web interface, persisted independently of the WiFi configuration, and applied at boot. Validation SHALL reject a static address inside the SoftAP subnet, a non-contiguous subnet mask, a gateway outside the address's network, an address equal to the gateway, and (for masks shorter than /31) the network or broadcast address of its subnet - each of these would still count as serviceable once the link is up, so no AP would rise and the device would sit unreachable. A static configuration that prevents the device from coming up SHALL be abandoned for DHCP after a bounded number of failed boots - counting only boots where the link was up; a cable-out boot proves nothing about the config and SHALL NOT count. A long press of the device button SHALL reset network configuration to DHCP.

#### Scenario: Static IP applied after restart

- **WHEN** the user saves a static Ethernet configuration
- **THEN** it is persisted and takes effect on the next restart, and the WiFi configuration is unchanged

#### Scenario: Unbootable static configuration

- **WHEN** a stored static Ethernet configuration fails a bounded number of consecutive boots with the link up
- **THEN** the device ignores it and boots on DHCP, so a bad static IP can never permanently strand a headless device

#### Scenario: Cable-out boots do not burn the backstop

- **WHEN** the device boots several times with no Ethernet link and a static configuration stored
- **THEN** the backstop counter does not advance, and the static configuration is still honoured on the next cabled boot

#### Scenario: Static address colliding with the recovery AP

- **WHEN** the user submits a static Ethernet address inside the SoftAP subnet
- **THEN** the configuration is rejected with an explanatory error

#### Scenario: Static address that can never carry traffic

- **WHEN** the user submits a static Ethernet address equal to the gateway, or equal to the network or broadcast address of the configured subnet
- **THEN** the configuration is rejected and not persisted

#### Scenario: Button network reset

- **WHEN** the user long-presses the button (the existing WiFi-reset tier)
- **THEN** all network configuration is cleared - WiFi credentials, WiFi static config, and Ethernet static config - so the device comes up on DHCP on whatever interface is available, or the SoftAP if none
- **AND** measurement data, calibration, web password, and cloud credentials are untouched
- **AND** the behavior is identical on every product: on a device without Ethernet the Ethernet-config clear is a no-op, so Home semantics are unchanged from today's WiFi reset

### Requirement: Ethernet is primary; WiFi STA is the automatic fallback

When both interfaces are available, Ethernet SHALL carry the default route. On Ethernet loss, an associated WiFi STA SHALL take over automatically. On Ethernet recovery, the default route SHALL return to Ethernet after a hold-down period that filters link flapping. Interface transitions SHALL NOT require a restart.

#### Scenario: Cable pulled with WiFi configured

- **WHEN** the Ethernet link drops on a device with associated STA
- **THEN** the established cloud MQTT and custom MQTT connections are actively dropped and reconnect over WiFi, rather than waiting out TCP keepalive on a dead path
- **AND** InfluxDB, which opens a new HTTP connection for every write, uses the new default route from its next write without needing a drop

#### Scenario: Cable restored

- **WHEN** the Ethernet link returns and holds beyond the hold-down period
- **THEN** the default route moves back to Ethernet

#### Scenario: Flapping link

- **WHEN** the Ethernet link bounces repeatedly within the hold-down period
- **THEN** the default route does not thrash: it stays on the stable interface until the link holds

#### Scenario: DNS and NTP follow the active interface

- **WHEN** the default route moves between interfaces
- **THEN** DNS resolution uses the new interface's DNS servers and NTP resynchronizes against a server reachable through it - neither keeps stale per-interface addresses (the resolver list and the gateway-derived NTP server are global state, not per-interface)

### Requirement: All network consumers are interface-agnostic

Every service gated on network readiness (MQTT cloud and local, NTP, InfluxDB, telemetry, health check, log streaming) SHALL treat "any serviceable interface" as connected. No service SHALL require WiFi specifically.

#### Scenario: Ethernet-only operation

- **WHEN** a Pro device runs with Ethernet up and no WiFi credentials stored
- **THEN** cloud MQTT over TLS, NTP sync, and all local integrations work, and the health check reports healthy indefinitely

#### Scenario: Health check during interface failover

- **WHEN** the default route moves between interfaces
- **THEN** the device does not restart due to a transient readiness gap during the transition

### Requirement: Ethernet is a trusted interface for local integrations

Services blocked on the SoftAP because it admits anyone in radio range (e.g. Modbus TCP) SHALL accept connections arriving on the Ethernet interface, which carries the same trust as the STA interface.

#### Scenario: Modbus TCP over Ethernet

- **WHEN** a client on the wired LAN connects to the Modbus TCP port
- **THEN** the connection is accepted, subject to the same rules as an STA-side client

### Requirement: Products without Ethernet are untouched

On a product whose profile declares no Ethernet, the system SHALL NOT initialize any Ethernet hardware or expose Ethernet configuration or status surfaces. Behavior SHALL be identical to firmware before this change.

#### Scenario: Home device on shared firmware

- **WHEN** a Home device runs a firmware build containing Ethernet support
- **THEN** no Ethernet SPI bus, driver object, task, NVS namespace, web page, or API surface is created, and the post-boot free-heap differs from the previous release only within noise

### Requirement: mDNS advertises the device on its active interface

The mDNS responder SHALL answer with the address of the interface currently carrying the default route, and SHALL re-announce when that address changes on failover. Advertised service metadata that depends on the hardware (such as the channel count) SHALL reflect the selected profile.

#### Scenario: Discovery after failover

- **WHEN** the default route moves from Ethernet to WiFi (or back)
- **THEN** resolving the device's mDNS name yields the active interface's address after the re-announcement

#### Scenario: Advertised channel count on Pro

- **WHEN** a Home Pro device advertises its services over mDNS
- **THEN** the advertised channel count is 12, from the profile, not a hard-coded value

### Requirement: Ethernet status is observable

The system SHALL expose the Ethernet state (link, DHCP/static, IP, gateway, DNS, MAC) through the web interface and REST API on products with Ethernet, alongside the existing WiFi status.

#### Scenario: Reading the wired address

- **WHEN** the user opens the device info or configuration page on a Pro device
- **THEN** the active interface is identified, and the Ethernet link state, addressing mode, IP and MAC are shown

### Requirement: Ethernet endpoints mirror the WiFi surface and refuse non-Ethernet products

The REST API SHALL expose Ethernet configuration and status endpoints following the existing WiFi network endpoint pattern (get/set/reset configuration, status). On a product whose profile declares no Ethernet, these endpoints SHALL return a 4xx client error - they do not exist as usable surface there, and the web UI SHALL NOT link to them.

#### Scenario: Configuring Ethernet on a Pro device

- **WHEN** a client sets an Ethernet configuration through the API on a Pro device
- **THEN** it is validated, persisted to the Ethernet namespace, and applied per the restart rules, mirroring the WiFi configuration endpoints' contract

#### Scenario: Ethernet endpoint called on a Home device

- **WHEN** any Ethernet configuration or status endpoint is requested on a device without Ethernet
- **THEN** the API answers with a 4xx error identifying the feature as unavailable on this product, and no NVS namespace is created or written

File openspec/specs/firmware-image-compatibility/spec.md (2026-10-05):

# firmware-image-compatibility Specification

## Purpose
Every firmware image declares, inside the binary itself, what hardware it was built for; the running firmware refuses to activate a staged OTA image whose declaration does not match the device. This is the device-side defense against flashing an image that cannot boot (wrong PSRAM silicon), which no post-boot recovery mechanism can catch.
## Requirements
### Requirement: Every image embeds a self-describing descriptor at a fixed offset

The build SHALL embed a 128-byte descriptor in the `.rodata_custom_desc` section, landing at image offset 0x120, containing: magic word, layout version, product, required PSRAM class, firmware version, build environment, git revision, supported PCB version range, and partition layout id. All field values SHALL be derived at compile time; the PSRAM class SHALL derive from the toolchain's own SPIRAM mode configuration so it cannot disagree with how the binary was built.

#### Scenario: Home and Pro binaries differ only where hardware differs

- **WHEN** the `esp32s3-prod` and `esp32s3-prod-pro` binaries of the same release are inspected at offset 0x120
- **THEN** both carry a valid descriptor with the same firmware version, and differ in product ("home" vs "homepro") and PSRAM class (2 vs 8)

### Requirement: A staged image is validated against the device before activation

Before any staged OTA image is activated (boot partition switched), the running firmware SHALL read the staged image's descriptor from the passive partition and reject activation when: the product does not match the device's product, the PSRAM class does not match the running image's PSRAM class, the device's PCB version falls outside the image's declared range (0 = unbounded), or the partition layout id differs. A staged image whose partition layout id is 0 SHALL be treated as "unspecified" and SHALL NOT be rejected on layout grounds, so a future partition-table change can be staged in two steps (first ship firmware that knows the new id, then flip it). Validation SHALL use only device-local data: the staged image's own bytes and the running device's identity.

#### Scenario: Unspecified partition layout id is tolerated

- **WHEN** a staged image otherwise matching the device carries partition layout id 0
- **THEN** it is accepted; any other id that differs from the running image's id is rejected

#### Scenario: Wrong-PSRAM image is rejected before it can brick the device

- **WHEN** a correctly signed Home Pro (octal) image is staged on a Home (quad) device through any path
- **THEN** the image is rejected before the boot partition is switched, the device keeps running its current firmware, and the rejection reason names the PSRAM mismatch

#### Scenario: Cloud rejection is terminal and scrubbed

- **WHEN** the cloud OTA path stages an image whose descriptor fails validation
- **THEN** the job is failed with reason `image_incompatible:<verdict>`, the retry schedule is abandoned (the failure is deterministic), and the staged image's header is scrubbed exactly as for a signature failure

#### Scenario: Manual upload fails fast on the first chunk

- **WHEN** a manual firmware upload's first chunk already contains the descriptor region and validation fails
- **THEN** the upload is rejected with an explanatory error before any further data is written, and the final pre-activation check still runs for uploads whose first chunk was too small

### Requirement: Legacy images without a descriptor are accepted only on quad-PSRAM Home

An image with no valid descriptor (bad magic or zero layout) SHALL be accepted only on a device whose product is Home AND whose running image was built for quad PSRAM (running descriptor PSRAM class 2) - every pre-descriptor official release and community self-build is a Home/quad image, and rejecting them would break legitimate downgrades. The product alone is not sufficient: it comes from factory NVS, and octal hardware provisioned as "home" would otherwise accept an unbootable image; only a running quad image proves a quad image can boot. A descriptor-less image SHALL be rejected in every other case, and a failed flash read of the staged image SHALL be a hard reject, never the legacy allowance.

#### Scenario: Downgrade to a pre-descriptor release on Home

- **WHEN** a Home device stages an official 2.x image released before this change
- **THEN** activation proceeds, with a log line identifying the image as legacy

#### Scenario: Descriptor-less image on Home Pro

- **WHEN** a Home Pro device stages an image with no valid descriptor
- **THEN** activation is rejected

#### Scenario: Descriptor-less image on octal hardware provisioned as Home

- **WHEN** a device whose factory product is Home but whose running image is an octal-PSRAM build stages an image with no valid descriptor
- **THEN** activation is rejected

### Requirement: Rollback never activates an incompatible image

Every path that switches the boot partition to the passive OTA slot without staging a new image - the API and MQTT `firmware_rollback` command and the crash-ladder automatic rollback - SHALL validate the passive slot's descriptor with the same policy (manual-path env rule: dev-on-prod allowed) before switching. A rejected verdict SHALL refuse the rollback: the command reports an invalid image, and the crash ladder skips rollback and proceeds to its next recovery step.

#### Scenario: Rollback onto a wrong-product image is refused

- **WHEN** the passive slot holds a complete, structurally valid image of the other product and a `firmware_rollback` command arrives
- **THEN** the boot partition is not switched and the command fails as an invalid image

#### Scenario: Crash ladder skips an incompatible rollback target

- **WHEN** the crash ladder reaches its rollback step and the passive slot's descriptor fails validation
- **THEN** no rollback is attempted and the ladder falls through to factory reset

### Requirement: Descriptors are reported for inventory

The running image's descriptor and the passive slot's descriptor (when valid) SHALL be reported in the system info API (`imageDescriptor.running` / `imageDescriptor.other`) and in the reported device shadow, so the fleet can see which PSRAM class and build each device runs and what a rollback would activate without per-device polling.

#### Scenario: Passive slot without a descriptor

- **WHEN** the passive slot is empty, erased, or holds a legacy pre-descriptor image
- **THEN** system info reports `imageDescriptor.other.present = false` and the shadow reports the `other_image_*` fields as null

### Requirement: Development builds do not reach production devices via cloud OTA

A staged image whose build environment is `dev` SHALL be rejected by a device running a `prod` build when delivered via cloud OTA, and SHALL be accepted with a logged warning when delivered via manual upload. A `prod` image SHALL always be accepted by a device running a `dev` build.

#### Scenario: Dev image in a cloud job

- **WHEN** a cloud OTA job delivers a `dev`-built image to a device running `prod` firmware
- **THEN** the job is rejected with reason `image_incompatible:dev_image_on_prod`

#### Scenario: Bench flashing a dev build

- **WHEN** a `dev`-built image is uploaded manually to a device running `prod` firmware
- **THEN** the upload proceeds and a warning is logged

### Requirement: Descriptor layout is append-only and versioned

Future descriptor layouts SHALL only append fields into the reserved region and bump the layout version; existing field offsets SHALL never move. A validator SHALL validate the fields it knows on any image whose layout version is greater than or equal to its own.

#### Scenario: Older firmware validates a newer image

- **WHEN** firmware knowing layout 1 stages an image carrying layout 2
- **THEN** the layout-1 fields are validated normally and the image is accepted if they pass

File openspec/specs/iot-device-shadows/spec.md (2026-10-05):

# iot-device-shadows Specification

## Purpose
Cloud<->device configuration sync over AWS IoT Named Device Shadows: publish-reported-first (no GET), reported-only shadows (info/issues/wifi) and writable shadows (system/meter/channels), local-edit drift-detect, optimistic concurrency, and the cloud-owns-clearing-desired contract. Secrets and high-rate telemetry stay out of shadows.
## Requirements
### Requirement: Publish-reported-first shadow sync without GET
The device SHALL synchronise configuration state with AWS IoT Named Device Shadows by publishing reported state and never issuing a `/get`. On every MQTT (re)connect the device SHALL, per shadow, subscribe to `update/delta` and `update/rejected` (NOT `update/accepted`) and publish `{state:{reported:<full current NVS config>}}` to `update`.

#### Scenario: Reconnect republishes reported state
- **WHEN** the MQTT client (re)connects to AWS IoT
- **THEN** each registered shadow publishes its full current reported state and subscribes to its `update/delta` and `update/rejected` topics, without publishing any `/get`

#### Scenario: Pending cloud intent surfaces as a delta
- **WHEN** a `desired` exists in the cloud document that differs from the just-published `reported`
- **THEN** AWS auto-pushes an `update/delta` (no GET needed) and the device applies it

### Requirement: Six named shadows with fixed read/write roles
The device SHALL expose exactly these named shadows: `info`, `issues`, `wifi` as reported-only, and `system`, `meter`, `channels` as writable. A delta delivered for a reported-only shadow SHALL be ignored.

#### Scenario: Writable shadow accepts a delta
- **WHEN** a delta arrives for `system`, `meter`, or `channels`
- **THEN** the device applies each field, persists it to NVS, and acks

#### Scenario: Reported-only shadow ignores a delta
- **WHEN** a delta arrives for `info`, `issues`, or `wifi`
- **THEN** the device logs a warning and does not apply or persist anything

### Requirement: Delta apply is atomic-acked with desired-null
On a writable-shadow delta the device SHALL apply each field, persist it, then publish a single combined `{state:{reported:{<applied>}, desired:{<field>:null}}}`. The `desired:<field>=null` removes the pending intent and that publish is the ack. Delta apply (blocking SPI/NVS work) SHALL run in the MQTT task body, never in the PubSubClient RX callback.

#### Scenario: Field applied and intent cleared in one publish
- **WHEN** a valid `system` delta sets a field
- **THEN** the device persists the value and publishes reported=<new> and desired:<field>=null in the same message

#### Scenario: Unknown desired field is nulled, not applied
- **WHEN** a delta carries a field the device does not recognise
- **THEN** the device publishes `desired:{<unknownField>:null}` and logs a WARN, applying nothing

### Requirement: Local edits drift-detect to reported-only
Local configuration changes (REST, UI, or internal) SHALL be detected source-agnostically within 3 s and republished as reported-only. A local edit SHALL NOT write `desired`, so the cloud is never overridden by silence.

#### Scenario: Local UI edit republishes reported
- **WHEN** a channel label is changed via the local web UI
- **THEN** within ~3 s the `channels` shadow republishes the new reported state with no `desired` written

### Requirement: mqtt_log_level transient auto-revert
Persistent log levels (INFO/WARNING/ERROR/FATAL) set via `system.mqtt_log_level` SHALL be persisted to NVS as the new baseline and cancel any active revert timer. Transient levels (VERBOSE/DEBUG) SHALL be applied at runtime without persisting, start a 5-minute one-shot timer, and on timer fire revert to the persisted baseline and publish the reverted reported state. A reboot while transient SHALL come back at the persisted baseline.

#### Scenario: DEBUG reverts after 5 minutes
- **WHEN** the cloud sets `mqtt_log_level` to DEBUG
- **THEN** the level applies at runtime, is not persisted, and reverts to the persisted baseline after 5 minutes with a reported republish

#### Scenario: Reboot during DEBUG restores baseline
- **WHEN** the device reboots while running a transient DEBUG level
- **THEN** it boots at the persisted baseline level

### Requirement: Optimistic concurrency via version
The device SHALL source the shadow `version` from the delta payload (not from `/update/accepted`) and use it for optimistic concurrency. On a 409 version conflict the device SHALL re-publish reported without a version and apply the fresh delta that follows, bounded and without an infinite loop.

#### Scenario: Version conflict recovers
- **WHEN** an `update` is rejected with a 409 version conflict
- **THEN** the device re-publishes reported state and applies the resulting fresh delta

### Requirement: Cloud owns clearing desired
Because the device uses asymmetric desired-null (the delta-ack nulls `desired`; local edits publish reported-only), a `desired` written equal to `reported` yields no delta and the no-GET device cannot clear it. The cloud SHALL clear `desired` reactively after convergence. Avoiding `desired == reported` writes is an optional optimisation only; no device-side change is required.

#### Scenario: No-op desired must be cloud-cleared
- **WHEN** the cloud writes a `desired` equal to the current `reported`
- **THEN** no delta is generated, the device does not clear `desired`, and the cloud must clear it after observing convergence

### Requirement: Secrets and high-rate telemetry stay out of shadows
Shadows SHALL NOT carry secrets (WiFi credentials, CustomMQTT credentials, InfluxDB token, web UI password) or high-rate telemetry (energy counters, instantaneous power). The `wifi` shadow SHALL report only non-secret network state (connected/ssid/ip/gateway/subnet/dns/mac, static_ip, fallback_to_dhcp). On hardware with Ethernet it SHALL additionally report `active_interface` and an `ethernet` object (enabled, and when enabled link_up/static_ip/ip/gateway/subnet/dns1/dns2/mac) instead of a separate named shadow.

#### Scenario: wifi shadow exposes no credentials
- **WHEN** the `wifi` shadow publishes reported state
- **THEN** it contains non-secret network fields only and no WiFi password

#### Scenario: Ethernet state reported on a Home Pro
- **WHEN** the `wifi` shadow publishes on hardware with Ethernet
- **THEN** it includes `active_interface` and the `ethernet` object, and a Home device publishes neither

### Requirement: System shadow exposes meter publish cadence fields
The `system` shadow SHALL expose `meter_publish_threshold_bytes` and `meter_publish_max_interval_ms` as writable fields, following the same delta-apply-persist-ack pattern as `send_power_data`/`send_grid_data`: a delta sets the field, the device persists it to NVS, and the same publish carries both the new `reported` value and `desired:{<field>:null}`.

#### Scenario: Field applied and intent cleared in one publish
- **WHEN** a valid `system` delta sets `meter_publish_threshold_bytes` or `meter_publish_max_interval_ms`
- **THEN** the device persists the (possibly clamped) value and publishes `reported=<applied>` and `desired:{<field>:null}` in the same message

#### Scenario: Reconnect reports current cadence values
- **WHEN** the MQTT client (re)connects
- **THEN** the `system` shadow's full reported state includes the current `meter_publish_threshold_bytes` and `meter_publish_max_interval_ms`, alongside the existing fields

### Requirement: Info shadow reports the rollback target fingerprint
The `info` shadow SHALL report `other_partition_sha256`: the 64-hex-character application sha256 of the firmware image currently in the passive OTA partition, or `null` when the passive slot holds no readable application descriptor. This makes every device's rollback target observable fleet-wide before any incident, so a `firmware_rollback` command's `expected_sha256` can be chosen from the shadow without querying the device during an outage.

#### Scenario: Info shadow carries the passive slot fingerprint
- **WHEN** the `info` shadow is published on a device that has completed at least one OTA
- **THEN** the reported state includes `other_partition_sha256` with the passive partition's 64-hex sha256 (the previously running firmware)

#### Scenario: Unreadable passive slot reported as null
- **WHEN** the passive partition has no valid application descriptor (e.g. fresh factory device)
- **THEN** the `info` shadow reports `other_partition_sha256` as `null`

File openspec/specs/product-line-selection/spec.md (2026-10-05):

# product-line-selection Specification

## Purpose
Determines at boot which product the firmware is running on (Home or Home Pro) from factory NVS, and selects the matching hardware profile so one firmware codebase serves every product and PCB revision.
## Requirements
### Requirement: The product line is read from factory NVS and defaults to Home

The system SHALL read `factory_ns::product_line` at boot to determine the product. A missing key SHALL be treated as `home`, permanently: the deployed fleet predates the key and requires no backfill. A present but unknown value SHALL put the device in community mode on the build's fallback product profile, consistent with malformed `pcb_revision` handling.

#### Scenario: Provisioned Home Pro device

- **WHEN** the device boots with `product_line = "homepro"` and a matching `pcb_revision`
- **THEN** the Home Pro hardware profile for that revision is selected and the device operates as a provisioned (non-community) device

#### Scenario: Legacy fleet device without the key

- **WHEN** a factory-provisioned device boots with certificates and `pcb_revision` present but no `product_line` key
- **THEN** the product is `home`, the profile matching its `pcb_revision` is selected, and the device remains fully provisioned - not community mode

#### Scenario: Unknown product value

- **WHEN** the device boots with `product_line` set to a value this firmware does not know
- **THEN** the device enters community mode on the build's fallback product profile and logs a warning, rather than trusting an identity it cannot interpret

### Requirement: Hardware profiles are selected by product and PCB version together

Profile lookup SHALL be keyed by the pair (product, PCB version). Product lines number their PCBs independently; Home Pro starts at v1.0. A version number SHALL never resolve across product boundaries.

#### Scenario: Same version number on two products

- **WHEN** a Home Pro device with `pcb_revision = "v1.0"` boots
- **THEN** the Home Pro v1.0 profile is selected, never a Home profile that happens to share the version number

#### Scenario: Existing Home devices are unaffected

- **WHEN** a Home device with `pcb_revision = "v6.1"` boots on firmware with Home Pro support
- **THEN** the selected profile, pins, channel count and behavior are identical to the firmware before this change

### Requirement: Fallback profile follows the build's product

When no profile can be selected (no factory NVS, missing or malformed `pcb_revision`, unknown product), the system SHALL fall back to the latest profile of the build's fallback product in community mode. The fallback product defaults to Home; every Home Pro build - production included - SHALL pin its fallback product to Home Pro, so a Pro binary never falls back to a Home pinout. Community builds targeting other hardware SHALL pin their product and version explicitly, via build-time fallback defines or by writing the factory NVS keys.

#### Scenario: Community device with no factory NVS

- **WHEN** a self-built device boots a Home build with no factory namespace
- **THEN** the latest Home profile is used in community mode, as today

#### Scenario: Unprovisioned Home Pro bench board

- **WHEN** a Pro build boots on a board with no factory NVS
- **THEN** the Home Pro v1.0 profile is selected in community mode

#### Scenario: Pro production device with damaged factory NVS

- **WHEN** a Pro production build boots and `pcb_revision` is malformed or `product_line` is unreadable
- **THEN** the device enters community mode on the latest Home Pro profile - never a Home pinout - because the binary's product is known at compile time

### Requirement: Channel count follows the selected profile

All channel-dependent behavior (measurement iteration, REST/MQTT/Modbus payload sizes, web UI channel lists) SHALL derive from the selected profile's channel count. Home Pro v1.0 exposes 12 channels (11 multiplexed + 1 direct).

#### Scenario: Pro device reports 12 channels

- **WHEN** a Home Pro v1.0 device serves channel data over any integration
- **THEN** exactly 12 channels (indices 0-11) carry data; requests for higher channel indices are rejected (fixed-size register maps may reserve the space, matching how v6.1 handles its unused range today)

#### Scenario: Product visible in device info

- **WHEN** the user reads the device info page or API
- **THEN** the product line is reported, so support dumps identify the product

### Requirement: Firmware images are product-specific and protected against cross-product installation

Firmware binaries are built per product (the products use different PSRAM silicon, fixed at compile time). The system SHALL identify its own product's firmware artifacts unambiguously - the Home artifact token is a substring of the Pro token, so matching SHALL resolve the Pro token first - and SHALL reject, before any flash write, a firmware delivery whose product does not match the running product, on every delivery path: manual web upload, community release download, and cloud OTA job.

#### Scenario: Wrong-product image uploaded manually

- **WHEN** a Home firmware artifact is uploaded through the web OTA endpoint of a Home Pro device (or vice versa)
- **THEN** the upload is rejected before any flash write, with an error identifying the product mismatch

#### Scenario: Pro artifact name contains the Home token

- **WHEN** a Pro artifact (whose name embeds the Home artifact token as a substring) is checked on a Home device
- **THEN** it is identified as a Pro artifact and rejected - substring presence of the Home token alone is never sufficient

#### Scenario: Community release with two assets

- **WHEN** a device checks a published release carrying one artifact per product
- **THEN** it selects the artifact matching its own product, never simply the first match

#### Scenario: Mistargeted cloud OTA job

- **WHEN** a cloud OTA job whose declared product does not match the device is received
- **THEN** the device refuses the job before downloading; a job with no product declaration is treated as Home for fleet compatibility

#### Scenario: Matching image uploaded manually

- **WHEN** a firmware artifact built for the running product is uploaded
- **THEN** the update proceeds under the existing OTA rules (authentication, signature policy, rollback)

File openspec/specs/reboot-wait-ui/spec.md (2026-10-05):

# reboot-wait-ui Specification

## Purpose
Defines the shared "device is restarting" wait experience used by every web UI action that reboots the device: how it detects the device is actually back, what it shows while waiting, and which actions must use it instead of a hardcoded delay.
## Requirements
### Requirement: Device availability is detected by polling, not a fixed delay
After a reboot-triggering request succeeds, the web UI SHALL detect the device coming back by polling `GET /api/v1/health` rather than waiting a fixed, hardcoded duration before redirecting or reloading.

#### Scenario: Device takes longer than any previously hardcoded delay
- **WHEN** the device takes 25 seconds to come back online after a restart
- **THEN** the wait screen remains visible and polling until health succeeds, and does not redirect early based on an elapsed-time guess

#### Scenario: Device comes back faster than expected
- **WHEN** the device comes back online in 3 seconds
- **THEN** the wait screen detects this via a successful poll and proceeds to redirect within one poll interval, without waiting out any fixed minimum

### Requirement: A poll success only counts after at least one poll has failed
The web UI SHALL NOT treat a successful `/api/v1/health` response as "device back online" unless at least one poll attempt since the reboot was triggered has already failed (timed out or errored). This guards against a health check landing before the device has actually dropped off the network.

#### Scenario: First poll after triggering the action still succeeds
- **WHEN** the restart was just triggered and the device has not yet dropped off the network, so the first health poll still succeeds
- **THEN** the wait screen does not redirect yet, and keeps polling until a poll fails and a subsequent poll succeeds

#### Scenario: Device drops immediately
- **WHEN** the device drops off the network before the first poll completes
- **THEN** the first failed poll satisfies the "seen unreachable" condition, and the next successful poll is treated as back online

### Requirement: Waiting has a capped duration with a manual fallback
The web UI SHALL stop polling automatically after a fixed maximum wait and present a manual option (at minimum, a way to retry or navigate home) instead of polling indefinitely.

#### Scenario: Device never comes back within the cap
- **WHEN** the device does not respond to health polls within 90 seconds of the reboot being triggered
- **THEN** the wait screen stops auto-polling and shows a manual fallback instead of spinning forever

#### Scenario: Manual retry when the device is already back
- **WHEN** the fallback is shown and the user chooses to check again while the device is already back online
- **THEN** the retry polls without requiring an observed failure first, so the first successful poll redirects instead of the retry spinning until the cap again

### Requirement: The wait screen only claims states that are actually observable
The wait screen SHALL only display status text for states the polling can actually distinguish: the triggering request was accepted, the device is unreachable/waiting, and the device is back online. It SHALL NOT display an intermediate step (e.g. "applying configuration", "verifying firmware") that the web UI has no way to observe once the device has dropped off the network.

#### Scenario: Generic reboot action
- **WHEN** a plain restart is triggered
- **THEN** the wait screen shows only these state transitions: command accepted, waiting/unreachable, back online

### Requirement: The underlying page is visible but inert while waiting
The wait screen SHALL be presented as a dimmed overlay above the current page: the page content stays visible behind it, but is not interactive until the wait screen closes.

#### Scenario: User tries to interact with the page during the wait
- **WHEN** the wait screen is active and the user clicks an element on the underlying page
- **THEN** the click has no effect on the underlying page

### Requirement: A rotating trivia strip fills the waiting time
While waiting, the wait screen SHALL display one fact at a time from a shared fact list, advancing automatically on a fixed interval, with manual previous/next controls that immediately show a different fact and reset the automatic advance timer.

#### Scenario: Left idle
- **WHEN** the user does not interact with the trivia controls
- **THEN** the displayed fact changes automatically at a regular interval for as long as the wait continues

#### Scenario: Manual navigation
- **WHEN** the user clicks the next or previous control
- **THEN** the displayed fact changes immediately to reflect the chosen direction, and the automatic advance timer restarts from that point

### Requirement: The fact list is shared with the OTA upload progress screen
The trivia fact list used by the wait screen SHALL be the same list used by the firmware update page's upload-progress screen (`update.html`), maintained in one place rather than duplicated.

#### Scenario: A fact is added to the shared list
- **WHEN** a new fact is added to the shared list
- **THEN** both the reboot wait screen and the OTA upload progress screen can display it

### Requirement: Redirect target is configurable per action
The wait screen SHALL redirect to `/` by default once the device is back online, and SHALL accept a caller-specified target URL for actions where the device may become reachable at a different address (e.g. applying a static IP configuration).

#### Scenario: Plain restart redirects home
- **WHEN** a plain restart completes and the device is detected back online
- **THEN** the browser is redirected to `/`

#### Scenario: Static IP change redirects to the new address
- **WHEN** a network configuration change that alters the device's IP address completes
- **THEN** the wait screen polls and redirects to the newly configured address, not the address the page was loaded from

### Requirement: Every reboot-triggering web UI action uses the shared wait screen
The following actions SHALL use this wait screen instead of a page-specific hardcoded delay: plain device restart, network configuration apply, WiFi credential switch, OTA firmware update (after the upload completes), firmware rollback, and configuration restore.

#### Scenario: OTA update hands off after upload completes
- **WHEN** a firmware upload finishes and the device begins its restart
- **THEN** the upload's byte-progress ring is replaced by the shared wait screen for the remainder of the wait

### Requirement: Factory reset does not use the shared wait screen
Because factory reset erases the device's stored WiFi credentials, the device leaves the current network and becomes reachable only via its own SoftAP at an address the browser cannot know in advance. The web UI SHALL NOT poll or redirect after triggering a factory reset; it SHALL continue to show manual reconnection instructions instead.

#### Scenario: Factory reset triggered
- **WHEN** a factory reset is triggered and completes
- **THEN** the web UI shows reconnection instructions and does not attempt to poll `/api/v1/health` or redirect

### Requirement: Filesystem restore does not use the shared wait screen
Restoring a filesystem backup extracts directly into the live LittleFS and responds without restarting the device, unlike configuration restore which does trigger a restart. The web UI SHALL NOT poll or redirect after a filesystem restore, since the device never reboots.

#### Scenario: Filesystem restore triggered
- **WHEN** a filesystem restore completes
- **THEN** the web UI does not invoke the shared wait screen and does not poll `/api/v1/health`

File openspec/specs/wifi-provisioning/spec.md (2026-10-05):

# wifi-provisioning Specification

## Purpose

TBD - Update Purpose after archive.
## Requirements
### Requirement: Provisioning never blocks the WiFi task

The WiFi task SHALL remain able to service its notification loop at all times during provisioning. No provisioning operation SHALL block the task for longer than one notification-loop iteration.

#### Scenario: Credential submission with a wrong password

- **WHEN** the user submits credentials that fail to associate
- **THEN** the WiFi task continues processing AP client events, the DNS lifecycle and the grace timer throughout the failure and retry

#### Scenario: AP raised while STA is down

- **WHEN** the device is in `UNPROVISIONED` with the SoftAP up
- **THEN** the task does not issue forced STA reconnects, and the AP-raise trigger count does not increase as a side effect of STA retry logic

### Requirement: The device serves its web interface without an upstream network

The device SHALL start the web server and local integrations when the SoftAP is raised, even when no STA connection exists.

#### Scenario: Unprovisioned first boot

- **WHEN** the device boots with no stored credentials
- **THEN** the SoftAP is raised and the web server accepts requests on the AP netif without waiting for an STA connection

#### Scenario: Health check during AP-only operation

- **WHEN** the device serves on the AP netif with STA down for an extended period
- **THEN** the health check reports healthy, the device does not restart, and the consecutive-reset counter does not increase

### Requirement: The SoftAP is raised while the device is unreachable, and only then

The SoftAP SHALL be raised whenever the device cannot be reached over its own network, and SHALL be torn down once it can. Association, not elapsed time, is the teardown condition. On products with Ethernet, "reachable" includes the Ethernet interface: a device with an Ethernet link and an address SHALL NOT raise the SoftAP, and a serviceable Ethernet interface SHALL satisfy the teardown condition the same way an STA association does. On products without Ethernet, the conditions are unchanged.

#### Scenario: Successful provisioning

- **WHEN** STA association succeeds from a session initiated on the AP
- **THEN** the AP is torn down after the grace period, or immediately once no AP clients remain

#### Scenario: Nobody ever connects

- **WHEN** the AP is raised and no client associates
- **THEN** the AP stays raised, because a device nobody can reach is not made more useful by going quiet

#### Scenario: Device loses its network permanently

- **WHEN** the device enters AP-assist because its network is gone and the user never intervenes
- **THEN** the AP stays raised indefinitely, with full authentication still required on it, so the device remains fixable in place rather than needing a power cycle
- **AND** STA association attempts continue throughout, so the device rejoins by itself if the network returns

#### Scenario: Unprovisioned device left alone

- **WHEN** a device with no stored credentials is left running
- **THEN** the AP remains raised, because it has no other way to be reached

#### Scenario: The AP is lowered while the device is still unreachable

- **WHEN** the AP comes down for any reason while the device still cannot associate
- **THEN** it is raised again on the next lifecycle tick, with no cooldown to wait out

#### Scenario: Cabled Pro device never raises the AP

- **WHEN** a Home Pro device has an Ethernet link and an address, with or without WiFi credentials
- **THEN** no SoftAP is raised, because the device is reachable over the wire

#### Scenario: Pro device recovers over Ethernet

- **WHEN** the SoftAP is up on a Pro device and an Ethernet cable is plugged in and obtains an address
- **THEN** the AP is torn down under the same rules as a successful STA association

#### Scenario: Pro device with no interface at all

- **WHEN** a Home Pro device has no Ethernet link and cannot associate to WiFi (or has no credentials)
- **THEN** the SoftAP is raised, exactly as on a Home device that cannot associate

### Requirement: Local integrations are not exposed on the SoftAP

Unauthenticated local integration services SHALL NOT accept connections arriving on the SoftAP netif.

#### Scenario: Modbus TCP during provisioning

- **WHEN** a client on the SoftAP connects to the Modbus TCP port
- **THEN** the connection is refused, because Modbus TCP carries no authentication and the SoftAP admits anyone within radio range

### Requirement: Credential changes do not restart the device

Changing the WiFi SSID or password SHALL apply without a restart. Changing the static IP configuration SHALL continue to require a restart.

#### Scenario: SSID change from the UI

- **WHEN** the user submits new WiFi credentials
- **THEN** the device associates to the new network without restarting, and reports the outcome through a status endpoint

### Requirement: New credentials can always be stored, including on a device that cannot associate

Submitting credentials SHALL store them regardless of the current association state. A device that cannot reach its network is precisely the device whose credentials need correcting, so the retry activity of that state SHALL NOT block the write.

#### Scenario: Correcting credentials on a device in AP-assist

- **WHEN** the user submits new credentials to a device that is repeatedly failing to associate
- **THEN** any association in flight is stopped first so the driver accepts the write, and the new credentials are stored and attempted

#### Scenario: The driver rejects the write

- **WHEN** the credential write is refused by the WiFi driver
- **THEN** the failure is retried once, and if it still fails the device SHALL report it through the status endpoint rather than leaving the caller with the success response the request already received

#### Scenario: Static IP change

- **WHEN** the user changes the static IP configuration
- **THEN** the device persists it and restarts to apply it, because reconfiguring a live netif races lwIP

### Requirement: Provisioning routes are reachable from the AP without the web password when unprovisioned

While the device is `UNPROVISIONED`, requests arriving on the SoftAP netif SHALL reach the web interface without digest authentication. In every other state, and on every other netif, digest authentication SHALL apply.

#### Scenario: Captive portal on first boot

- **WHEN** a phone joins the SoftAP of an unprovisioned device and the OS issues a captive-detection probe
- **THEN** the probe is answered without an authentication challenge and the user is directed to the WiFi setup page

#### Scenario: In-service device that lost its network

- **WHEN** a client joins the SoftAP of a device in AP-assist and requests any route
- **THEN** digest authentication is required

#### Scenario: Request arriving on the STA netif

- **WHEN** a request arrives on the STA netif while the device is `UNPROVISIONED`
- **THEN** digest authentication is required

#### Scenario: Reading the log while provisioning fails

- **WHEN** a user on the SoftAP of an unprovisioned device opens the log view to find out why association keeps failing
- **THEN** it is reachable without the web password, matching what the removed diagnostic page offered

#### Scenario: Grace period after a successful connect

- **WHEN** a client on the SoftAP requests a route during the grace period
- **THEN** digest authentication is required, because the device is now reachable on the LAN and the justification for opening up is gone

#### Scenario: Device's own loopback health probe

- **WHEN** the health check connects to `127.0.0.1`
- **THEN** it is not treated as an AP-origin request for the purpose of the authentication carve-out

#### Scenario: LAN host routing to the AP address

- **WHEN** a host on the LAN sends a request to the SoftAP address via a static route through the device's STA address
- **THEN** the request does not receive the authentication carve-out

### Requirement: Firmware update always requires authentication

The OTA endpoint SHALL require digest authentication in every provisioning state and on every netif, including the SoftAP.

#### Scenario: OTA attempt from the AP while unprovisioned

- **WHEN** a client on the SoftAP of an unprovisioned device requests the OTA endpoint
- **THEN** digest authentication is required, even though other routes are carved out in that state

### Requirement: The DNS responder is confined to AP-only operation

The catch-all DNS responder SHALL run only while the SoftAP is raised and no station-side interface is serviceable - STA disconnected, and on products with Ethernet, no serviceable Ethernet interface either - and SHALL be stopped once any station-side interface comes up.

#### Scenario: STA connects while the AP is still up

- **WHEN** STA association succeeds during the grace period
- **THEN** the DNS responder stops, so the device does not answer DNS queries arriving on the LAN

#### Scenario: AP address changed by subnet-collision avoidance

- **WHEN** the SoftAP address is moved to avoid a collision with the STA subnet
- **THEN** the DNS responder answers with the current SoftAP address, not a previously cached one

#### Scenario: Ethernet becomes serviceable while the AP is up

- **WHEN** an Ethernet address is obtained during AP recovery on a Pro device
- **THEN** the DNS responder stops, because the device is now reachable on a real network and must not answer LAN DNS queries

### Requirement: The SoftAP subnet never overlaps the STA subnet

The SoftAP SHALL be assigned a subnet that does not overlap any station-side subnet - the STA subnet, and on products with Ethernet, the Ethernet subnet (live lease or configured static) - because lwIP resolves an ambiguous route to the first matching interface and a later-added interface is prepended.

#### Scenario: Router uses the default AP subnet

- **WHEN** the STA network occupies the SoftAP's default subnet
- **THEN** the SoftAP is assigned a different non-overlapping subnet before it is raised

#### Scenario: Restored backup carries a foreign static IP

- **WHEN** a configuration backup from a different LAN is restored and its static IP overlaps the SoftAP subnet
- **THEN** subnet selection accounts for the configured static IP, not only the live STA lease

#### Scenario: Radio brought up in AP+STA mode

- **WHEN** the WiFi mode is set to AP+STA at boot with persistent storage enabled
- **THEN** no SoftAP is broadcast until the device decides to raise one, because the driver restores the last SoftAP config from NVS and would otherwise beacon it on a subnet no collision check ever approved
- **AND** the address the authentication carve-out and the Modbus TCP block compare against is never left unset while an AP is reachable

#### Scenario: Collision appears after the AP is raised

- **WHEN** the AP is raised while unprovisioned and STA later obtains a lease that overlaps the AP subnet
- **THEN** the condition is logged and the AP is torn down rather than left routing ambiguously

#### Scenario: Ethernet lease overlaps the AP subnet

- **WHEN** the AP is up on a Pro device and Ethernet obtains an address that overlaps the AP subnet
- **THEN** the AP is torn down (the device is wire-reachable anyway), never left routing ambiguously
- **AND** subnet selection for a future AP raise accounts for the Ethernet subnet - lease and configured static - alongside the STA subnet

### Requirement: The setup page tells the user where the meter went

A client on the SoftAP loses the ability to read the device's state the moment it submits credentials, because that transition closes the auth carve-out. The page SHALL therefore tell the user where to find the meter at submit time, and SHALL NOT present a pending state it cannot resolve.

#### Scenario: Credentials accepted

- **WHEN** the setup page submits credentials successfully over the SoftAP
- **THEN** it immediately shows the address the meter will be reachable at, and what the device LED will do
- **AND** it does not wait on a status endpoint that will answer 401 from that moment on

#### Scenario: Landing on the setup page

- **WHEN** an unprovisioned device serves its setup page
- **THEN** the user is offered both connecting the meter to WiFi and inspecting the device, rather than only a credentials form

### Requirement: Connection diagnostics survive the removal of the configuration portal

Disconnect diagnostics that are currently available only through the WiFiManager diagnostic page SHALL remain available through the device's own API.

#### Scenario: Diagnosing a failed association

- **WHEN** STA association fails and the user opens the interface from the SoftAP
- **THEN** the last attempted SSID, disconnect reason, disconnect BSSID and RSSI are retrievable

#### Scenario: Wrong password during setup

- **WHEN** the user submits a password the network rejects
- **THEN** the setup page says the password was not accepted, rather than repeating the driver's disconnect code, because WPA2 reports a rejected password as a four-way handshake timeout rather than as an authentication failure
- **AND** the raw code stays visible alongside it for anyone diagnosing something else

### Requirement: Power-cut recovery does not raise the SoftAP

A power interruption that also restarts the user's router SHALL NOT cause the device to raise a SoftAP before the router has had time to boot.

#### Scenario: Household power cut

- **WHEN** the device restarts from a power-on or brownout reset and the router is still booting
- **THEN** the device applies the extended connection timeout before counting association failures toward raising the SoftAP

### Requirement: Provisioning carve-outs require a peer inside the SoftAP subnet

Every test that treats a request as arriving over the SoftAP (the unauthenticated provisioning carve-out, the provisioning-session read carve-out, and the AP-origin widening of the default-password allowlist) SHALL require both that the request was addressed to the SoftAP address AND that the peer address lies inside the SoftAP subnet (and is not the AP address itself). The destination address alone is not proof of arrival interface: with Ethernet up, lwIP accepts a wired packet addressed to the SoftAP address and routes the reply back out Ethernet.

#### Scenario: LAN host addresses the SoftAP address over Ethernet

- **WHEN** an unprovisioned Pro device has its SoftAP raised and a host on the wired LAN sends a request to the SoftAP address
- **THEN** the request is not treated as a provisioning-origin request and runs the full authentication chain

#### Scenario: Real SoftAP client

- **WHEN** a client associated to the SoftAP, holding an address the SoftAP leased, requests the provisioning page while unprovisioned
- **THEN** the carve-out applies exactly as before

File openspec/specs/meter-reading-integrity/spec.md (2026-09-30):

# meter-reading-integrity Specification

## Purpose
TBD - created by archiving change harden-meter-energy-window-glitches. Update Purpose after archive.
## Requirements
### Requirement: Non-destructive energy-register reads

The system SHALL read the ADE7953 active, reactive, and apparent energy registers **without read-with-reset** (`LCYCMODE` bit 6 `RSTREAD` cleared). In line cycle accumulation mode the hardware latches a full accumulation window into each energy register at every `CYCEND` and holds it until the next `CYCEND`, so a non-destructive read always returns the last complete window regardless of when or how often the register is read.

#### Scenario: Register read twice within one line-cycle window

- **WHEN** an energy register is read a second time before the next `CYCEND`
- **THEN** it returns the same full-window value as the first read, not zero

#### Scenario: Read timing jitter does not corrupt the value

- **WHEN** a channel read happens at a variable offset after `CYCEND` (early or late within the window)
- **THEN** the value returned is the last complete latched window, unaffected by the read offset

#### Scenario: Genuine no-load still reads zero

- **WHEN** the channel is below the hardware no-load threshold
- **THEN** the energy register reads zero (the no-load feature is independent of the read-with-reset setting)

### Requirement: Contaminated post-switch window discarded by skipping, not by reset

After a multiplexer channel switch, the system SHALL discard the contaminated accumulation window by skipping one line-cycle window rather than by issuing a reset read. The next `CYCEND` overwrites the register with a clean full window on the settled channel, which is the window that is read and published.

#### Scenario: Reading after a mux switch

- **WHEN** the multiplexer switches to a new channel
- **THEN** the window spanning the switch is skipped and the first fully-settled window on the new channel is the one read and published

### Requirement: Energy integration is not double-counted on repeated reads

Because published readings can repeat within a window once reads are non-destructive, the system SHALL integrate accumulated energy (Wh) using the actual elapsed time since the last accepted read, so a repeated read within a window does not double-count energy.

#### Scenario: Two reads within one window

- **WHEN** a channel is read twice within one window (elapsed times summing to about one window)
- **THEN** the integrated energy for that window is counted once (proportional to actual elapsed time), not doubled

### Requirement: RMS witness cross-check on every channel's reading

Every channel derives active, reactive, and apparent power from the energy registers (a channel on another line of a three-phase supply rotates its active/reactive pair into its own line; apparent energy is not rotated). On every channel's reading, the system SHALL read the independent `IRMS` register and compare apparent power derived from energy (`APENERGY / _sampleTime`) against apparent power derived from RMS (`voltage x IRMS`). The comparison SHALL be apparent-against-apparent only, never active-against-apparent, so legitimately low power-factor loads never cause a false rejection. When the two estimates diverge beyond the calibrated tolerance, the system SHALL discard the reading through the existing invalid-reading path. `IRMS` is never published; current remains derived from apparent energy (an off-phase channel also uses `IRMS` for its no-load gate).

#### Scenario: Partial-window or mux artifact while current still flows

- **WHEN** a channel's energy-derived apparent power is far below `voltage x IRMS` (divergence beyond tolerance)
- **THEN** the reading is discarded and not published, and a failure is recorded

#### Scenario: Steady load agrees within tolerance

- **WHEN** the energy-derived and RMS-derived apparent power agree within the calibrated tolerance
- **THEN** the reading is accepted and published unchanged

#### Scenario: Low power-factor load does not false-trip

- **WHEN** a load has real active power well below its apparent power (low power factor) but the energy-derived and RMS-derived *apparent* power agree
- **THEN** the reading is accepted

#### Scenario: Legitimate close-in-time read is preserved

- **WHEN** a valid reading arrives a short wall-clock interval after the previous one but is physically consistent (energy-derived apparent power agrees with `voltage x IRMS`)
- **THEN** the reading is accepted (the check is physical, not timing-based)

### Requirement: Discard isolated glitches rather than substitute

When the witness check fails, the system SHALL discard the single affected reading and SHALL NOT substitute a computed value, hold the previous value, or zero the reading. This applies to isolated single-sample glitches only and does not reintroduce discarding of sustained readings.

#### Scenario: Single-sample glitch discarded

- **WHEN** the witness check rejects one reading for a channel
- **THEN** no value is published for that channel this cycle and the next cycle proceeds normally

### Requirement: Witness tolerance calibrated from device data

The divergence tolerance for the RMS witness SHALL be calibrated from measured device data (energy-derived apparent power, RMS-derived apparent power, and their ratio, captured during real production) so the band rejects artifacts without dropping genuine fast transients.

#### Scenario: Tolerance derived from captured data

- **WHEN** the tolerance is set
- **THEN** its value is justified by captured device data showing steady-state agreement clustered near unity and artifact divergence clearly outside the band

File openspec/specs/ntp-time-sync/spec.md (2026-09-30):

# ntp-time-sync Specification

## Purpose
TBD - created by archiving change configurable-ntp-server. Update Purpose after archive.
## Requirements
### Requirement: Gateway is tried first for NTP sync
The device SHALL include its current default-gateway IP address as the first NTP server slot on every `configTime()` call (initial sync in `CustomTime::begin()` and the periodic re-sync in `_checkAndSyncTime()`), read fresh from the active network interface at the time of the call rather than cached. The one exception is the single immediate retry after an answer rejected by the time floor, which uses only the public fallback servers.

#### Scenario: Router answers NTP on its gateway address
- **WHEN** the device's default gateway responds to NTP requests
- **THEN** the device synchronises its clock against the gateway, without any manual configuration

#### Scenario: Gateway changes between sync attempts
- **WHEN** the device's gateway IP changes (DHCP lease renewal, static IP reconfiguration, or reconnecting to a different network) between one sync attempt and the next
- **THEN** the next `configTime()` call uses the new gateway IP, with no stale state left over from the previous network

### Requirement: Public defaults remain as fallback
The device SHALL include two public NTP servers - `pool.ntp.org` (hostname) and a Cloudflare NTP IP address (DNS-independent) - as the second and third server slots, so that time sync continues to work on networks with normal internet access even when the gateway does not run an NTP responder, and remains resilient to a broken DNS path.

#### Scenario: Gateway does not run NTP, internet is reachable
- **WHEN** the gateway does not respond to NTP requests but the device has normal internet access
- **THEN** the device synchronises its clock against one of the two public fallback servers

#### Scenario: Unconfigured/never-changed device keeps working
- **WHEN** a device is freshly provisioned or updated to this behavior with no other changes
- **THEN** it still successfully syncs on any network with internet access, exactly as before this change

### Requirement: No configuration surface
NTP server selection SHALL NOT be exposed as user-configurable state anywhere - no NVS persistence, no REST endpoint, no web UI field, and no AWS IoT device shadow field (writable or reported).

#### Scenario: No REST endpoint exists for NTP servers
- **WHEN** a client queries the device's REST API for NTP server configuration
- **THEN** no such endpoint exists; NTP server selection is not part of any configuration API

#### Scenario: No shadow delta can alter NTP behaviour
- **WHEN** an AWS IoT shadow delta is applied for any registered shadow
- **THEN** it SHALL NOT change NTP server selection, since no shadow field exists for it

### Requirement: Time floor
The device SHALL NOT let an NTP answer step the clock when it is more than 60 seconds earlier than the time floor, or when it carries an all-zero transmit timestamp (RFC 4330; lwIP decodes it as 2036-02-07T06:28:16Z) or a time outside the valid range (2001-09-09 to 2100-01-01; lwIP decodes answers up to 2104), whatever the floor. The floor at boot SHALL be the later of the firmware's source commit time (build floor) and the floor persisted in NVS; with neither, no floor applies. An accepted answer SHALL raise the floor to the time it carries, but never above a ceiling of the boot floor plus the uptime. A raised floor SHALL be persisted by the energy save task within its save interval; while the meter has failed to start (no energy save task) it is not persisted, and the next boot starts from the last persisted floor. A manual time set SHALL only lower the floor, never raise it, and SHALL keep the ceiling at or below the time set. A factory reset SHALL clear the persisted floor.

#### Scenario: Wrong-but-plausible past answer is rejected
- **WHEN** the floor is in 2026 and an NTP server answers with a 2023 time
- **THEN** the clock is not stepped, and the device retries once right away without the gateway

#### Scenario: Zero transmit timestamp is rejected
- **WHEN** an unsynchronized server answers with an all-zero transmit timestamp
- **THEN** the clock is not stepped, even when no floor applies

#### Scenario: Answer past 2100 is rejected
- **WHEN** an NTP server answers with a time lwIP decodes past 2100-01-01
- **THEN** the clock is not stepped, even when no floor applies

#### Scenario: A consistently fast source cannot poison the floor
- **WHEN** every NTP answer is ahead of real time by the same amount, across several syncs
- **THEN** the persisted floor stays at or below real time, and after a reboot a genuine answer is accepted

#### Scenario: A single future answer heals at the next sync
- **WHEN** one NTP answer is far in the future and the next one is genuine
- **THEN** the genuine answer is accepted and steps the clock back

#### Scenario: Manual set undoes a wrong floor
- **WHEN** the floor is later than real time and the time is set manually to real time
- **THEN** the floor drops to the time set and genuine NTP answers are accepted again; a build floor later than real time applies again after a reboot

#### Scenario: No build floor and nothing persisted
- **WHEN** the firmware has no commit time and NVS holds no floor
- **THEN** every answer in the valid range except the zero transmit one steps the clock, as before the floor existed

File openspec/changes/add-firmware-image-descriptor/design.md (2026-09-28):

# Design - Firmware Image Descriptor

## D1: Placement - `.rodata_custom_desc`, not an `esp_app_desc` override

The prebuilt-libs toolchain defines `esp_app_desc` as a WEAK symbol, so overriding it from project code is possible - but a strong override must replicate low-level fields the bootloader actually checks (`mmu_page_size`, `min/max_efuse_blk_rev_full`), coupling us to values frozen in the pinned platform. The linker script's `.rodata_custom_desc` slot sits immediately after `esp_app_desc_t` ("Should be the second. Custom app version info."), giving a fixed image offset of 0x120 (24 B image header + 8 B segment header + 256 B `esp_app_desc_t`) with zero risk to IDF's own structure. Verified empirically on both build variants.

The section is unreferenced by code paths the linker can see, so `--gc-sections` strips it unless kept alive: `-Wl,-u,ENERGYME_APP_DESC` in the common build flags, mirroring the `-u esp_app_desc` flag the IDF build itself uses.

## D2: Layout - 128 bytes, append-only, versioned

```
uint32_t magic;               // "EMHW" (0x57484D45 LE)
uint32_t layout;              // 1; future layouts append fields, never move them
char     product[16];         // "home" / "homepro"
uint32_t psramMb;             // PSRAM class the image was built for: 2 (quad) / 8 (octal)
char     fwVersion[16];       // FIRMWARE_BUILD_VERSION
char     buildEnv[8];         // "dev" / "prod"
char     gitRev[12];          // short commit hash, "unknown" outside a git checkout
uint16_t minPcbVersion;       // packed major*10+minor; 0 = no lower bound
uint16_t maxPcbVersion;       // 0 = no upper bound
uint32_t partitionLayoutId;   // 1 = current partition table; bump on any table change; 0 = unspecified (not checked)
uint8_t  reserved[56];        // zero; future fields land here under a layout bump
```
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

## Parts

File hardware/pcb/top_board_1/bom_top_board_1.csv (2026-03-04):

ID | Name | Designator | Footprint | Quantity | Manufacturer Part | Manufacturer | Supplier | Supplier Part | Price
1 | PJ-3200 | CH2,CH3 | AUDIO-TH_PJ-3200 | 2 | PJ-3200 | XKB Connection(中国星坤) | LCSC | C2689690 | 0.058
2 | PZ254V-11-04P_C2691448 | H1 | HDR-TH_4P-P2.54-V-M | 1 | PZ254V-11-04P | XFCN(兴飞) | LCSC | C2691448 | 0.023

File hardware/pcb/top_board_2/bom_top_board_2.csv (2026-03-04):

ID | Name | Designator | Footprint | Quantity | Manufacturer Part | Manufacturer | Supplier | Supplier Part | Price
1 | PJ-3200 | CH10,CH11,CH12,CH13,CH14,CH15 | AUDIO-TH_PJ-3200 | 6 | PJ-3200 | XKB Connection(中国星坤) | LCSC | C2689690 | 0.058
2 | PZ254V-12-8P | H4 | HDR-TH_8P-P2.54-V-M-R2-C4-S2.54 | 1 | PZ254V-12-8P | XFCN(兴飞) | LCSC | C492421 | 0.043

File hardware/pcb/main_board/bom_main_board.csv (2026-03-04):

ID | Name | Designator | Footprint | Quantity | Manufacturer Part | Manufacturer | Supplier | Supplier Part | Price
1 | PJ-3200 | CN1,CN2,CN6,CN7,CN8,CN9,CN10,CN11 | AUDIO-TH_PJ-3200 | 8 | PJ-3200 | XKB Connection(中国星坤) | LCSC | C2689690 | 0.058
2 | 1MΩ | R18,R19,R20 | R0402 | 3 | 0402WGF1004TCE | UNI-ROYAL(厚声) | LCSC | C26083 | 0.001
3 | 10uF | C3,C6,C8,C12,C14,C16,C18 | C0402 | 7 | CL05A106MQ5NUNC | SAMSUNG(三星) | LCSC | C15525 | 0.006
4 | 100nF | C25,C4,C5,C7,C10,C11,C13,C15,C17 | C0402 | 9 | CC0402KRX7R7BB104 | YAGEO(国巨) | LCSC | C60474 | 0.001
5 | 3300uF | C2 | CAP-TH_BD8.0-P3.50-D0.6-FD | 1 | HS0J338M0816PC | HONOR(荣誉) | LCSC | C5438512 | 0.312
6 | 1nF | C24 | C2211 | 1 | GA352QR7GF102KW01L | muRata(村田) | LCSC | C91599 | 0.262
7 | PM254V-12-08-H85_C2834799 | H3 | HDR-TH_8P-P2.54-V-F-R2-C4-S2.54 | 1 | PM254V-12-08-H85 | XFCN(兴飞) | LCSC | C2834799 | 0.119
8 | JFC2410-0500TS | F1 | F2410 | 1 | JFC2410-0500TS | JDTfuse(集电通) | LCSC | C136377 | 0.081
9 | ZMPT107-1 | L1 | XFMR-TH_ZMPT107-1 | 1 | ZMPT107-1 | 择明朗熙 | LCSC | C125191 | 0.561
10 | 33nF | C19,C20,C21,C9,C22,C23 | C0402 | 6 | FCC0402B333K500AT | FOJAN(富捷) | LCSC | C7419416 | 0.001
11 | 10kΩ | R8,R1,R5,R7 | R0402 | 4 | 0402WGF1002TCE | UNI-ROYAL(厚声) | LCSC | C25744 | 0.001
12 | 1kΩ | R9,R13,R2,R3,R4,R6,R15,R16,R17 | R0402 | 9 | 0402WGF1001TCE | UNI-ROYAL(厚声) | LCSC | C11702 | 0.001
13 | 51kΩ | R10,R11,R12 | R1206 | 3 | 1206W4F5102T5E | UNI-ROYAL(厚声) | LCSC | C17992 | 0.004
14 | 180Ω | R14 | R0402 | 1 | 0402WGF1800TCE | UNI-ROYAL(厚声) | LCSC | C38941 | 0.001
15 | PM254V-11-04-H85 | H2 | HDR-TH_4P-P2.54-V-F | 1 | PM254V-11-04-H85 | XFCN(兴飞) | LCSC | C541851 | 0.063
16 | 3.579545MHz | X1 | OSC-SMD_4P-L3.2-W2.5-BL_FT3HNBPK16.0-T1 | 1 | RO03579043 | TROQ(创捷) | LCSC | C7206319 | 0.264
17 | ESP32-S3-WROOM-1(N16R2) | U3 | WIRELM-SMD_ESP32-S3-WROOM-1 | 1 | ESP32-S3-WROOM-1-N16R2 | ESPRESSIF(乐鑫) | LCSC | C2913205 | 4.802
18 | 74HC4067PW,118 | U5 | TSSOP-24_L7.8-W4.4-P0.65-LS6.4-BL | 1 | 74HC4067PW,118 | Nexperia(安世) | LCSC | C179326 | 0.573
19 | ADE7953ACPZ-RL | U7 | LFCSP-28_L5.0-W5.0-P0.50-BL-EP | 1 | ADE7953ACPZ-RL | Analog Devices | LCSC | C515890 | 3.201
20 | 100nF | C1 | CAP-TH_L13.0-W6.0-P10.00-D1.0 | 1 | MP2104K27C3X6LC | SRD(圣融达) | LCSC | C105759 | 0.04
21 | ZX-QC66-7.5TP | U2,U4 | KEY-SMD_4P-L6.0-W6.0-P4.50-LS8.6 | 2 | ZX-QC66-7.5TP | Megastar(兆星) | LCSC | C7470157 | 0.03
22 | TC5050RGBF08-3CJH-AF53A | LED1 | LED-SMD_6P-L5.0-W5.0-TL_TC5050RGBF08 | 1 | TC5050RGBF08-3CJH-AF53A | TCWIN(天成) | LCSC | C784540 | 0.02
23 | HLK-PM03 | U1 | PWRM-TH_HLK-PM03 | 1 | HLK-PM03 | HI-LINK | LCSC | C209904 | 2.67
24 | DB301V-5.0-2P | U6 | CONN-TH_2P-P5.00_L7.6-W10.0 | 1 | DB301V-5.0-2P-BU-S | DIBO(地博电气) | LCSC | C395882 | 0.115
25 | 561KD10 | VAR1 | RES-TH_L12.5-W4.8-P7.50-D1.2-S3.40 | 1 | 561KD10 | Brightking(君耀电子) | LCSC | C78349 | 0.076

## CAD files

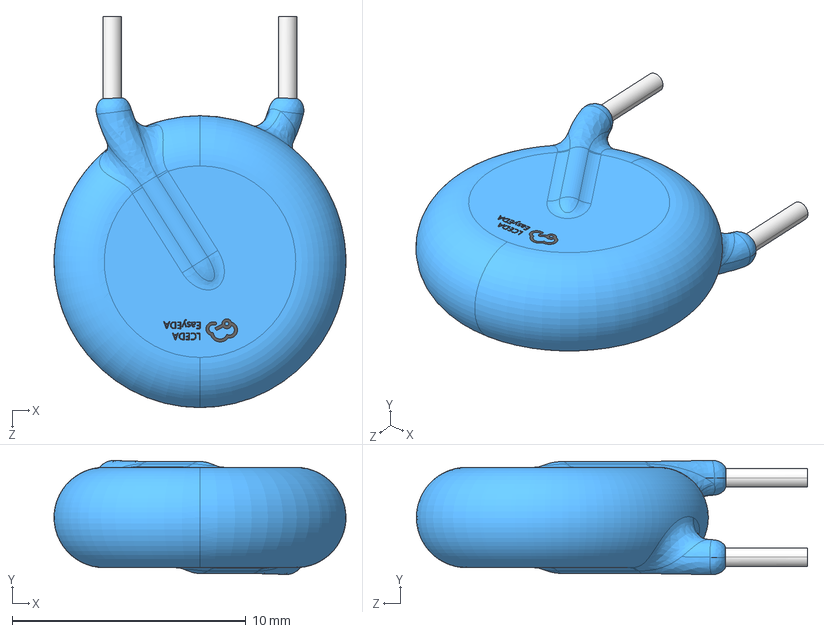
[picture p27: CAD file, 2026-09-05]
hardware/pcb/kicad/main_board/EASYEDA_MODELS/RES-TH_L12.5-W4.8-P7.50-S3.40.step
12.5 x 4.89 x 16.7 mm

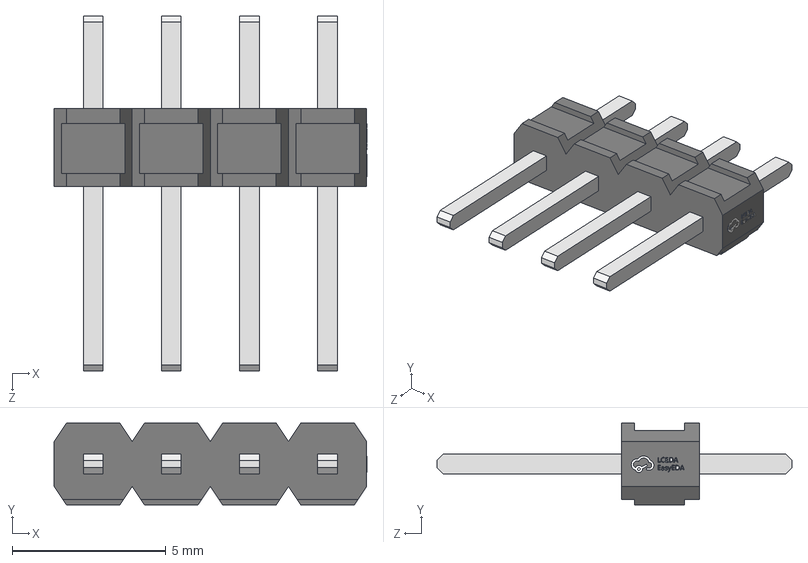
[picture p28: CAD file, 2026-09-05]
hardware/pcb/kicad/top_board_1/EASYEDA_MODELS/HDR-TH_4P-P2.54-M-LI-1X4P.step
10.2 x 2.66 x 11.5 mm

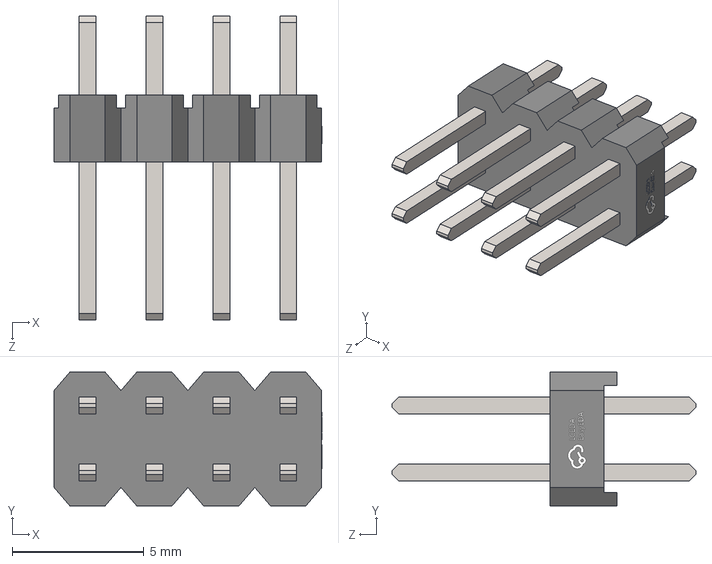
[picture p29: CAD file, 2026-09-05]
hardware/pcb/kicad/top_board_2/EASYEDA_MODELS/HDR-TH_8P-P2.54-M-LI-2X4P.step
10.2 x 5.08 x 11.5 mm

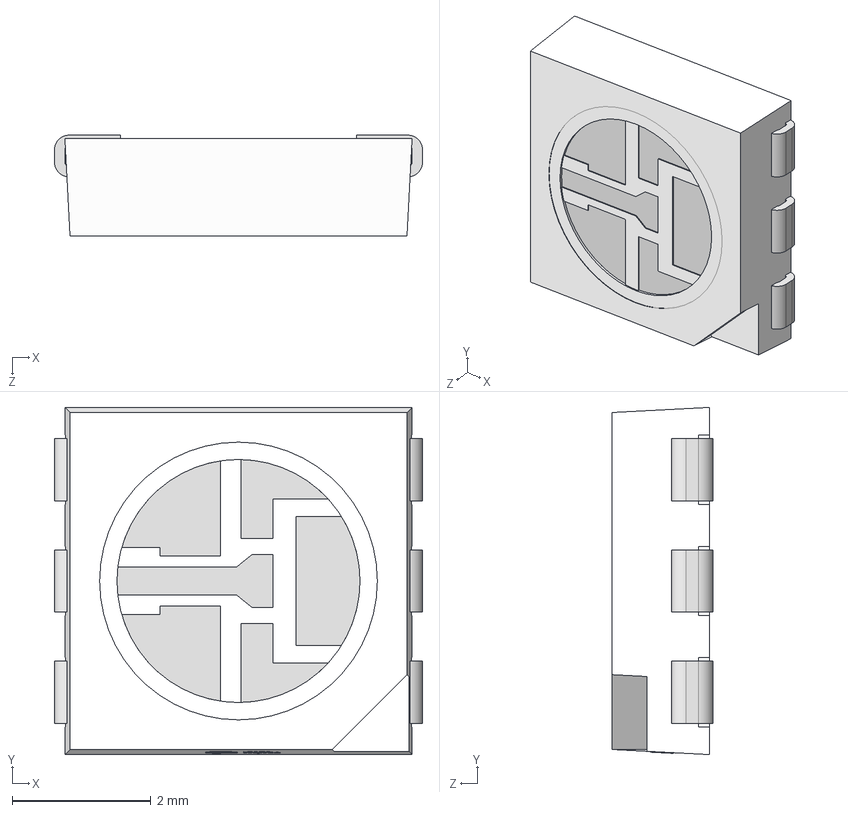
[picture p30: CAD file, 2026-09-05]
hardware/pcb/kicad/main_board/EASYEDA_MODELS/LED-SMD_6P-L5.0-W5.0-P1.6-LS5.4-TL.step
5.30 x 5.00 x 1.45 mm

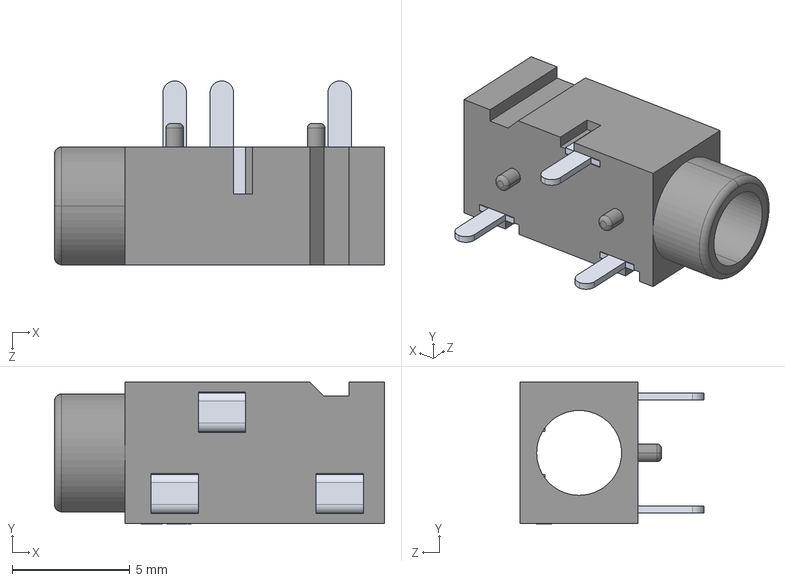
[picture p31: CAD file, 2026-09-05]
hardware/pcb/kicad/top_board_1/EASYEDA_MODELS/AUDIO-TH_PJ-3200.step
14.0 x 6.01 x 7.81 mm

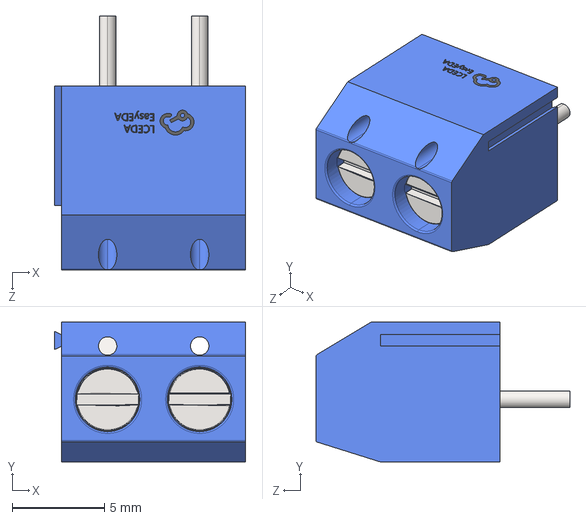
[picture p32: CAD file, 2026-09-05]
hardware/pcb/kicad/main_board/EASYEDA_MODELS/CONN-TH_DB5.00-LI-2P-301.step
10.4 x 7.60 x 13.8 mm

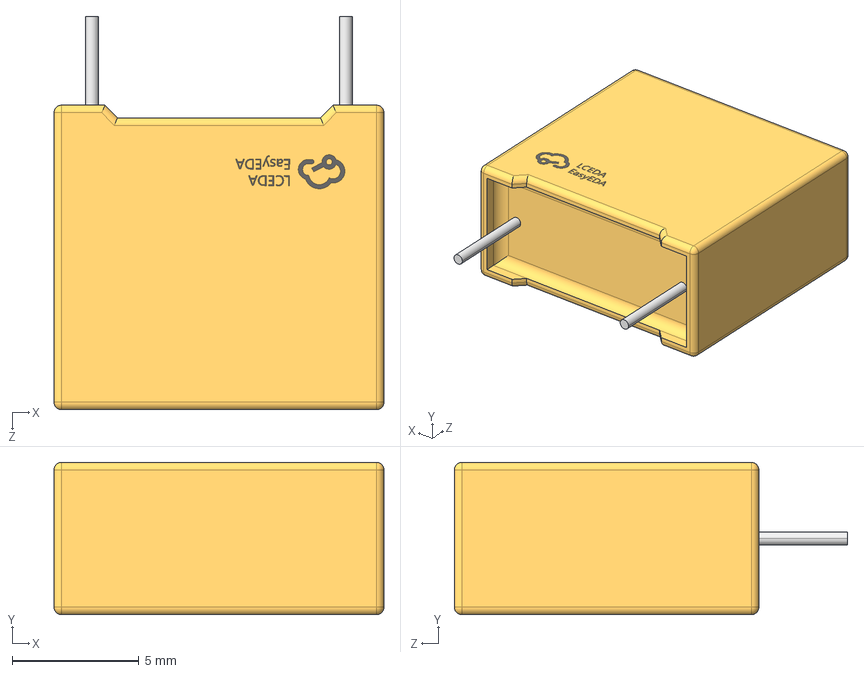
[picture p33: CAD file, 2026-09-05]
hardware/pcb/kicad/main_board/EASYEDA_MODELS/CAP-TH_L13.0-W6.0-H12.0-P10.0.step
13.0 x 6.00 x 15.5 mm

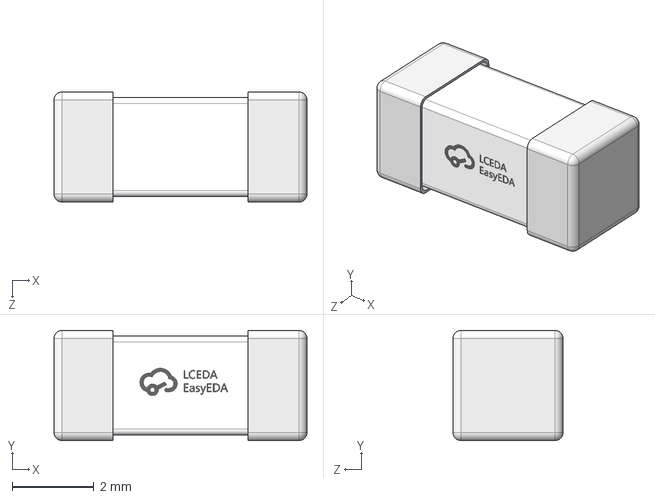
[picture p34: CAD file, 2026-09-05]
hardware/pcb/kicad/main_board/EASYEDA_MODELS/F2410_L6.2-W2.7-H2.7.step
6.20 x 2.70 x 2.70 mm

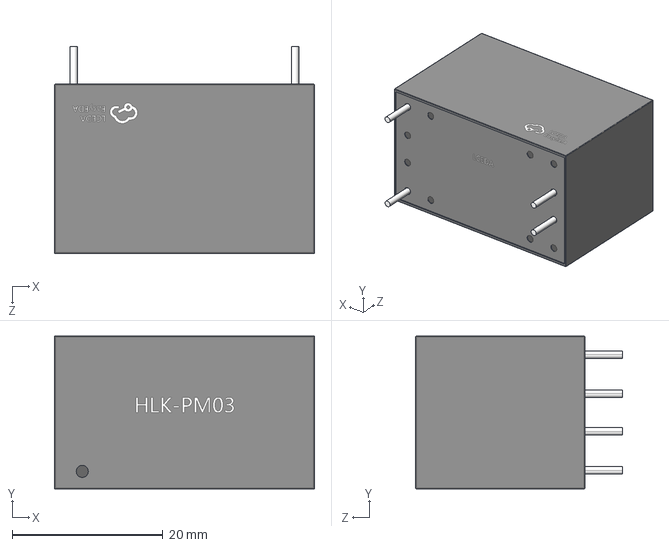
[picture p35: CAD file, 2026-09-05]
hardware/pcb/kicad/main_board/EASYEDA_MODELS/PWRM-TH_HLK-PM03.step
34.5 x 20.3 x 27.5 mm

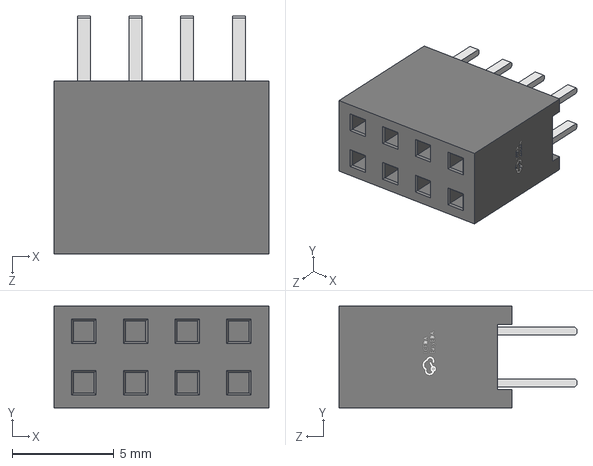
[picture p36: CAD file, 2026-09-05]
hardware/pcb/kicad/main_board/EASYEDA_MODELS/HDR-TH_8P-P2.54-F-LI-2X4P.step
10.6 x 5.00 x 11.7 mm

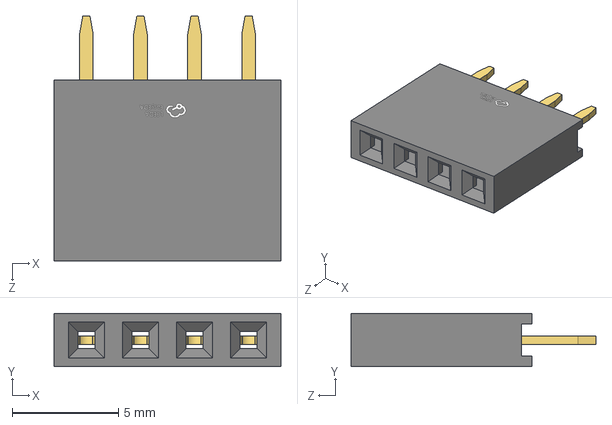
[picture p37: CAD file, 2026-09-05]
hardware/pcb/kicad/main_board/EASYEDA_MODELS/HDR-TH_4P-P2.54-V-F.step
10.7 x 2.50 x 11.5 mm

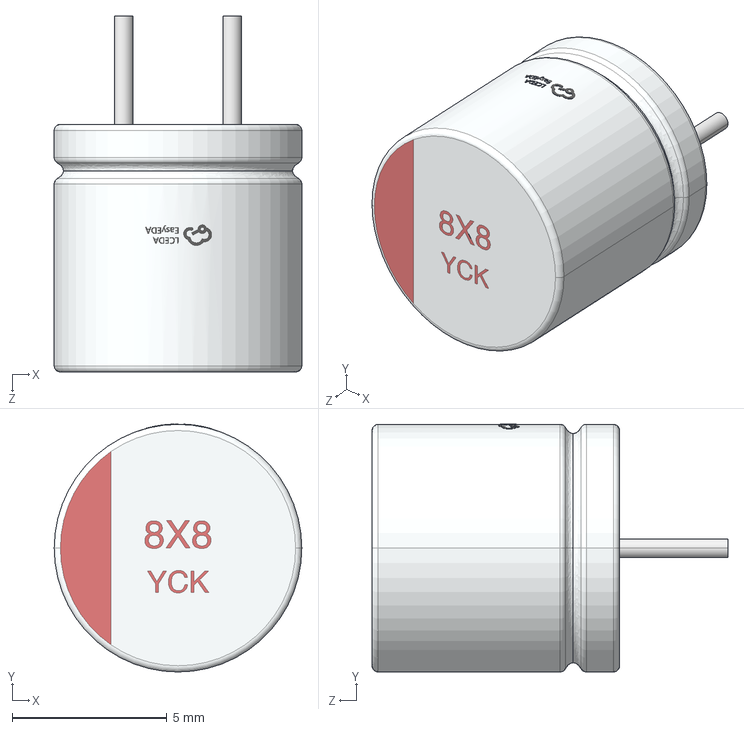
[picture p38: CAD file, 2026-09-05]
hardware/pcb/kicad/main_board/EASYEDA_MODELS/CAP-TH_D8.0-H8.0-P3.50.step
8.00 x 8.01 x 11.5 mm

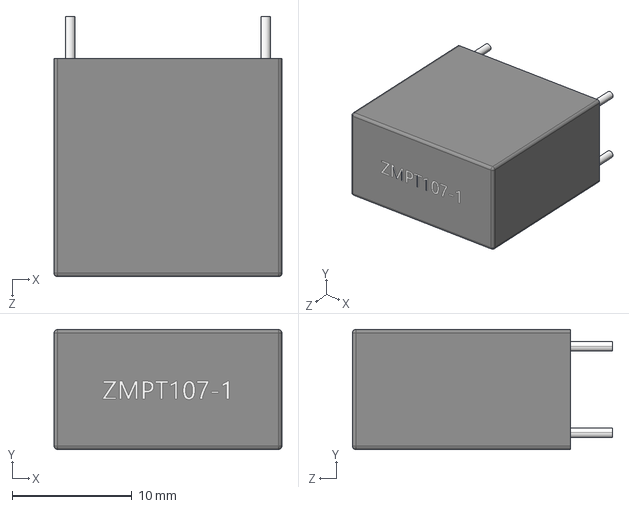
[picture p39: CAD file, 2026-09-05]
hardware/pcb/kicad/main_board/EASYEDA_MODELS/XFMR-TH_L19.0-W10.0-H18.2.step
19.0 x 10.0 x 21.7 mm

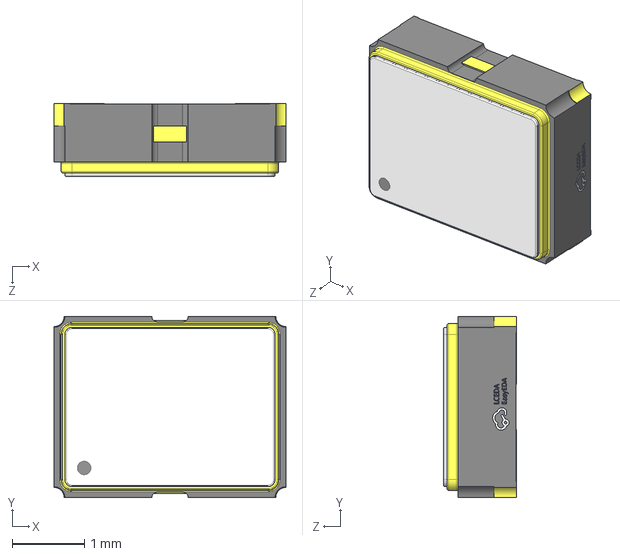
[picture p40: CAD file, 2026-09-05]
hardware/pcb/kicad/main_board/EASYEDA_MODELS/OSC-SMD_4P-L3.2-W2.5-BL_FT3HNBPK16.0-T1.step
3.20 x 2.50 x 1.01 mm

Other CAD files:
hardware/pcb/kicad/main_board/EASYEDA_MODELS/WIRELM-SMD_ESP32-S3-WROOM-1.step
hardware/pcb/kicad/main_board/EASYEDA_MODELS/LFCSP-28_L5.0-W5.0-H0.8-P0.50.step
hardware/pcb/kicad/main_board/EASYEDA_MODELS/C0402_L1.0-W0.5-H0.5.step
hardware/pcb/kicad/main_board/EASYEDA_MODELS/C2211_L5.7-W2.8-H1.5.step
hardware/pcb/kicad/main_board/EASYEDA_MODELS/KEY-SMD_4P-L6.0-W6.0-H5.0-LS10.0-P4.50.step
hardware/pcb/kicad/main_board/EASYEDA_MODELS/R0402_L1.0-W0.5-H0.4.step
hardware/pcb/kicad/main_board/EASYEDA_MODELS/R1206_L3.2-W1.6-H0.6.step
hardware/pcb/kicad/main_board/EASYEDA_MODELS/TSSOP-24_L7.8-W4.4-H1.0-LS6.4-P0.65.step

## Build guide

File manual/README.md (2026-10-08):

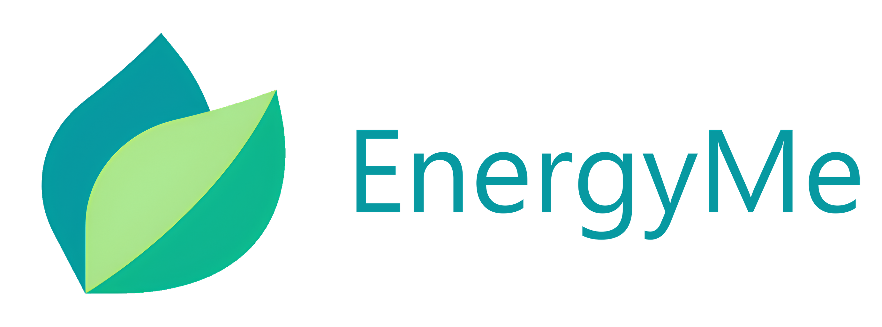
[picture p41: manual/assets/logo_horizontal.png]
EnergyMe


# EnergyMe-Home: Setup & Usage Guide

A practical guide to wiring, configuring, and using the open-source EnergyMe-Home board: electrical installation, Wi-Fi and web-interface setup, channel mapping, and troubleshooting.

> ⓘ **Maker / community guide.** This covers the open-source board you build or run yourself. If you bought a ready-made unit, the official product Installation Manual and safety & compliance documentation are on our [website](https://www.energyme.net/energyme-home-installation-guide) (Home Pro: [here](https://www.energyme.net/energyme-homepro-installation-guide)).

## Before you start: Read this page

> *"You're about to discover things you never knew were happening behind your walls."*

Welcome. In the next 15 minutes, your home is going to stop being a black box. You're going to see, for the first time, exactly where your energy goes: which circuits eat it during the night, which appliances are quietly draining your wallet, which lights you forgot on three years ago.

Some users discover their fridge consumes more than their TV. Some find a phantom load that's been running for years. A few discover their solar panels are producing less than they should. **Whatever your home is hiding, EnergyMe is about to reveal it.**

Hold tight. This is going to be interesting.

---

*EnergyMe - Home* connects directly to the AC mains inside your electrical panel. Working inside an electrical panel is **dangerous** if you don't know what you are doing.

| You can do yourself | You need a qualified electrician |
| --- | --- |
| Open the box and identify the parts ([§1](01-installation.md#1-whats-in-the-box)) | Anything inside the electrical panel ([§3](01-installation.md#3-electrical-installation)) |
| Configure Wi-Fi and the web interface ([§4](02-setup.md#4-software-configuration)) | Switching off the main breaker |
| Map circuits to channels in the UI ([§4.5](02-setup.md#45-configure-each-channel)) | Connecting L / N to the device |
| | Clamping the CTs around the wires |

> **⚠ WARNING: Electrical hazard**  
> Do not open your electrical panel with the main breaker ON. Mains voltage can kill. If you have any doubt, **stop and call a qualified electrician**. The installation must comply with **your local electrical codes and regulations**. You assume all responsibility for the installation.

---

## Contents

1. [Installation](01-installation.md) — box contents, what you need, electrical work (electrician)
2. [Setup](02-setup.md) — Wi-Fi, web interface, channel configuration (end user)
3. [Troubleshooting](03-troubleshooting.md) — symptom-driven guide for when something doesn't behave as expected
4. [Appendices](appendices.md) — channel map, three-phase configuration, LED reference, button reference, Home Pro (Ethernet)

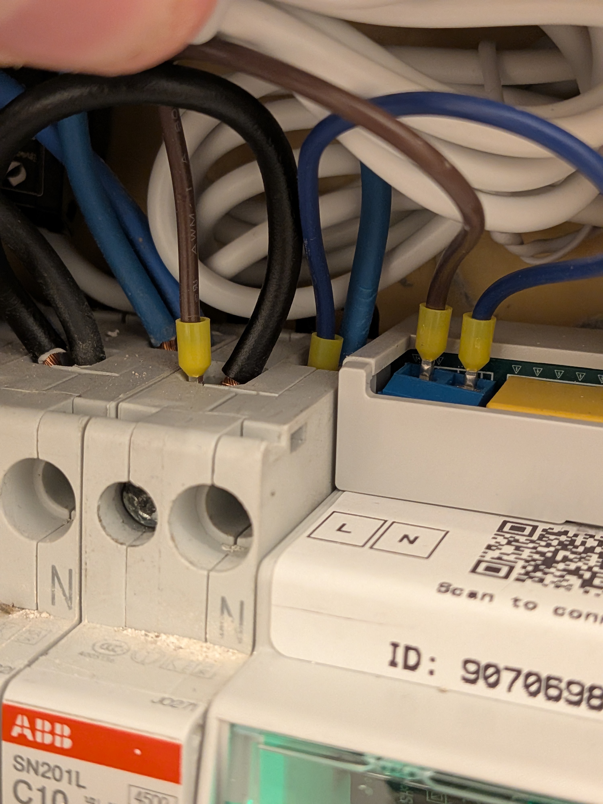
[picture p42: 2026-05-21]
manual/assets/connection_l_n.jpg

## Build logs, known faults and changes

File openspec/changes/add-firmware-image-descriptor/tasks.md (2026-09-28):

# Tasks - add-firmware-image-descriptor

## 1. Descriptor library (pure, host-tested)

- [x] 1.1 `lib/image_descriptor`: struct (128 B, static-asserted), parse from image-start buffer with defensive string termination, `validate()` with typed verdicts, verdict-to-string
- [x] 1.2 Unity tests: every verdict, legacy policy per product, PCB bounds (0 = unbounded), partition layout, env policy per path, layout >= ours accepted, short buffer

## 2. Descriptor emission

- [x] 2.1 Emit `ENERGYME_APP_DESC` in `.rodata_custom_desc` from a dedicated TU; values from `PRODUCT_FALLBACK`, `CONFIG_SPIRAM_MODE_OCT`, `FIRMWARE_BUILD_VERSION`, `ENV_DEV`/`ENV_PROD`, `GIT_REV`
- [x] 2.2 `-Wl,-u,ENERGYME_APP_DESC` in common build flags (gc-sections keep-alive)
- [x] 2.3 Git revision injection via extra_script (falls back to "unknown")
- [x] 2.4 Remove the PoC struct from `hardware_profile.cpp`

## 3. Device-side validation glue

- [x] 3.1 Partition reader + `DeviceIdentity` builder (product/PCB from runtime profile; PSRAM class, partition layout id, env from the running image's own descriptor)

## 4. Gates

- [x] 4.1 Cloud OTA: validate after signature verification, before `esp_https_ota_finish()`; deterministic failure `image_incompatible:<verdict>`, scrub like signature failure
- [x] 4.2 Manual upload: first-chunk early reject when the chunk covers the descriptor region
- [x] 4.3 Manual upload: authoritative check in `_finalizeOtaUpload()` before `Update.end(true)`
- [x] 4.4 Rollback: `attemptFirmwareRollback()` (API/MQTT `firmware_rollback`) validates the passive slot before `esp_ota_set_boot_partition()` and returns `INVALID_IMAGE` on a reject verdict
- [x] 4.5 Crash ladder: `CrashMonitor::_handleCounters()` validates the passive slot before `Update.rollBack()` and falls through to factory reset on a reject verdict
- [x] 4.6 Report running + passive-slot descriptors in `/api/v1/system/info` (`static.imageDescriptor`) and the reported shadow (`image_*`, `other_image_*`)

## 5. Verification

- [x] 5.1 Native tests green (WSL)
- [x] 5.2 Both env binaries carry correct descriptors at 0x120 (hexdump check) - note: only the dev envs (`esp32s3-dev`, `esp32s3-dev-pro`) were hexdumped; the prod envs share the same emitting TU and differ only in `buildEnv`
- [x] 5.3 `esp32s3-dev` and `esp32s3-dev-pro` build clean

## 6. Hardware-blocked (bench, when a device is available)

- [x] 6.1 Manual upload of a renamed wrong-product .bin is rejected on-device - done 2026-09-19: the Home image named `firmware.bin` on the Pro and the Pro image named `firmware.bin` on the Home both answer 400 "not compatible with this device" on the first chunk (nothing written, other partition still rollback-able, device keeps running); a Pro image carrying a Home artifact name is refused by the name gate
- [x] 6.2 Cloud OTA job with a wrong-product image fails with `image_incompatible:*` and the device keeps running - done 2026-09-21: signed a real Home (esp32s3-dev) binary with the Home Pro dev KMS key via `ota_release.py sign --from-file`, published a real AWS IoT job (`energyme-homepro-dev-ota-device-9-9-9-...`) declaring `product: homepro` at `thing:14c19f4e1b44` (the Pro bench unit). Job doc and signature both passed (job-product and signature-format gates are correct, key matched); full 2,783,840-byte download completed (HTTP 200); `ImageDescriptor::validate()` then rejected it post-download with `image_incompatible:psram_mismatch` (the Home binary has quad PSRAM baked in, the running device is octal). Job execution status FAILED with that reason in `statusDetails`; device uptime and the crash archive (still exactly 2 entries) were unchanged across the attempt - it never rebooted or crashed.
- [x] 6.3 Downgrade to a pre-descriptor release still works on Home - done 2026-09-19 on the Home dev unit: the 2026-08-17 dev build (no descriptor at 0x120) is accepted, boots and serves; uploading the current build from it works too

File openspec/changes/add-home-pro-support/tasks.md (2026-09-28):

# Tasks: Home Pro Support

## 1. Product line foundation

- [x] 1.1 Add `FACTORY_KEY_PRODUCT_LINE` to `factory_keys.h` and a `ProductLine` enum (`home`, `homepro`)
- [x] 1.2 Read `product_line` in `initHardwareProfile()`: absent → home; unknown value → community mode on the build's fallback product profile, warning logged
- [x] 1.3 Add `product` field to `HardwareProfile`; key lookup by (product, version); fallback search filters to the build's fallback product (default home)
- [x] 1.4 Add `PRODUCT_FALLBACK` build define alongside `PCB_VERSION_FALLBACK`; every Pro env pins `PRODUCT_FALLBACK=homepro` (prod included - a Pro binary must never fall back to a Home pinout)
- [x] 1.5 Add `esp32s3-dev-pro` and `esp32s3-prod-pro` envs to `platformio.ini` (naming matches `esp32s3-dev-v5` convention): `board_build.arduino.memory_type = qio_opi`, `board_build.psram_type = opi` for N16R8; same partition table; Home envs and `[common]` untouched
- [x] 1.6 Expose product line in device info (REST + info page), per the product-line-selection spec scenario

## 2. Home Pro hardware profile

- [x] 2.1 Extend `HardwareProfile` with Ethernet fields (hasEthernet, CS/INT/RST pins, dedicated SPI bus pins) - Home entries all zero/false
- [x] 2.2 Add Home Pro v1.0 profile entry with netlist-derived pinout (design.md "Home Pro v1.0 pinout"): ADE7953 SPI identical to v6.x, mux S0=21/S1=47/S2=48/S3=38, LED 40/41/39, button 0, W5500 CS=16/SCLK=15/MISO=7/MOSI=6/IRQ=5/RST=4, mux map [15,14,13,12,11,2,8,1,9,0,10], dividers 153000/180
- [x] 2.3 Verify all channel-count consumers iterate the profile value with a Pro profile active (grep audit + build); drive the mDNS modbus TXT `channels` value from the profile (currently hard-coded "16" in customwifi.cpp)

## 3. Interface arbitration logic (host-testable)

- [x] 3.1 Create `lib/interface_arbitration`: pure state machine - inputs (eth link up + valid address [DHCP lease or applied static], sta associated, hold-down timer), outputs (`Decision{preferred, switchRequired}`); includes flap debounce. AP raise/teardown is not an arbitration output: it lives in `lib/wifi_provisioning` (`shouldRaiseAp()` / `shouldTearDownAp()` take the wired inputs), see 7.1
- [x] 3.2 Unity tests: cable pull → STA, cable return after hold-down → ETH, flap sequences don't thrash, static-address ETH preferred, link-up-without-address is not serviceable, Home inputs → outputs identical to current behavior, no interface → preferred NONE (the AP-raise side is covered by the provisioning tests, 7.3)
- [x] 3.3 Run `pio test -e native` from WSL - green before any firmware wiring

## 4. Ethernet driver verification

- [x] 4.1 Confirm `ETH.begin()` W5500 SPI overload against pinned core 3.3.2: `begin(type, phy_addr, cs, irq, rst, SPIClass&, spi_freq_mhz)` exists; `CONFIG_ETH_SPI_ETHERNET_W5500=1` and `CONFIG_SPIRAM_TRY_ALLOCATE_WIFI_LWIP=1` in the qio_opi variant (verified 2026-09-01)
- [x] 4.2 Spike sketch on devkit + W5500 breakout: link events, DHCP lease, INT-driven confirmed (IRQ wired to GPIO5) - superseded 2026-09-21: never run as a separate spike, but the real Pro PCB gives strictly stronger evidence (9.1, 9.4) - ~5s DHCP lease and ~2s cable-pull failover, only possible with a genuinely interrupt-driven link path, not polling
- [x] 4.3 Verify `WiFiClientSecure` TLS MQTT connect works over ETH with WiFi radio off; note heap figures - superseded 2026-09-21: real Pro board ran TLS MQTT (AWS IoT) and a TLS HTTPS cloud OTA download over Ethernet with WiFi fully unconfigured (12:53 onward)

## 5. Ethernet module

- [x] 5.1 Create `custometh.{h,cpp}`: init from profile (only when hasEthernet), `ARDUINO_EVENT_ETH_*` handlers (run in the Network event task - copy state under mutex, act outside) feeding the arbitration lib, `Network.setDefaultInterface()` on arbitration output; arbitration state and config guarded by `_configMutex` per FreeRTOS rules
- [x] 5.2 `EthConfiguration` struct + `eth_ns` persistence: DHCP/static, ip/gw/subnet/dns, config module pattern (get/set/toJson/fromJson/validate) with mutex; validation rejects a static IP inside the SoftAP subnet; `eth_ns` is created lazily on first write (never on Home), cleared by factory reset, included in config backup/restore on Pro
- [x] 5.3 Boot-fail backstop for static ETH config: counter increments only when the link is up and the static config fails to become serviceable; no-link boots are neutral; independent of (and non-interacting with) the WiFi backstop
- [x] 5.4 Wire into `main.cpp`: ETH init after profile selection, product-gated; boot network wait accepts ETH and stays bounded by the existing `SETUP_NETWORK_WAIT_TIMEOUT_MS`
- [x] 5.5 On default-route change, actively drop MQTT/custom-MQTT connections so they reconnect on the new interface (no waiting on TCP keepalive timeouts); reapply DNS servers and restart NTP sync for the active interface - note: InfluxDB has no drop-on-failover callback and needs none, it builds a fresh `HTTPClient` per send, so every write opens a new socket on the current route

## 6. Predicate generalization (one module per task/commit)

- [x] 6.1 Generalize network-readiness predicates ("any serviceable interface"): thin network-level predicate (`CustomNet`) both customwifi and custometh feed. No dedicated restart deadline re-arms when both interfaces are lost: the health check's consecutive-failure counter covers it (fails while `CustomNet::isNetworkServiceable()` is false, 5 x 30 s before a restart, reset on the first success), which also tolerates the hold-down + reconnect window of a failover
- [x] 6.2 Convert mqtt.cpp gates to the generalized predicate
- [x] 6.3 Convert custommqtt.cpp gates
- [x] 6.4 Convert influxdbclient.cpp gates
- [x] 6.5 Convert customtime.cpp gates; gateway-derived NTP server must follow the active interface
- [x] 6.6 Convert customlog.cpp + telemetry gates
- [x] 6.7 Convert maintenance/health-check gates
- [x] 6.8 Modbus TCP: ETH counts as trusted interface (accept), SoftAP still blocked
- [x] 6.9 mDNS: advertise the active interface's IP, re-announce on failover - no firmware rebuild on failover: the ESP-IDF responder serves every predefined netif (`CONFIG_MDNS_PREDEF_NETIF_ETH` / `_STA` / `_AP`). Bench-verified 2026-09-23 on the Pro (.80 eth / .70 wifi): with both up, both A records are answered; after a cable pull only the WiFi address is answered within ~6 s and the UI stays reachable on it; on replug the ETH record returns within ~5 s and arbitration switches back after the 10 s hold-down. The `wifi` shadow followed (active_interface ethernet -> wifi -> ethernet)
- [x] 6.10 Build both dev envs + run full native test suite

## 7. SoftAP raise conditions (product-gated)

- [x] 7.1 Feed ETH state into the AP raise/teardown predicates in `lib/wifi_provisioning` (`shouldRaiseAp()` / `shouldTearDownAp()` gain `wiredReachable` / `wiredLinkUp` / `wiredPresent` inputs, sourced from custometh's arbitration state); Home path evaluates identically to today; link-up-without-address counts as unreachable (AP may rise after the DHCP wait)
- [x] 7.2 DNS responder confinement and AP-subnet collision checks account for ETH (responder stops when ETH is serviceable; AP subnet never overlaps the ETH subnet)
- [x] 7.3 Unity tests on the provisioning logic: cabled Pro never raises AP, ETH recovery tears AP down, no-interface Pro raises AP, link-but-no-lease raises AP, all existing Home scenarios unchanged

## 8. Configuration surface + OTA product safety

- [x] 8.1 REST endpoints for ETH config (get/set/reset) + status (link, mode, IP, gateway, DNS, MAC) mirroring the wifi endpoint pattern; 4xx on products without Ethernet, no NVS side effects
- [x] 8.2 Web UI: ETH status on info page, ETH settings on configuration page, active-interface indicator; hidden on Home
- [x] 8.3 Button SINGLE_LONG becomes network reset: clear WiFi credentials + WiFi static + eth_ns static (unconditional; no-op clears on Home), leaving calibration/web password/cloud credentials intact
- [x] 8.4 swagger.yaml for new endpoints (mind CRLF staging)
- [x] 8.5 Product-aware manual OTA upload gate in `_initializeOtaUpload`: filename must match the running product's artifact token, checked unambiguously (Pro token checked before the Home token, since `energyme_home` is a substring of `energyme_homepro`); reject before any flash write
- [x] 8.6 GitHub release asset picker (`_fetchGitHubReleaseInfo`) becomes product-aware with the same unambiguous matching
- [x] 8.7 Cloud OTA job document gains a `product` field verified on-device before download starts (absent field = home for fleet compatibility); coordinate the job-creation side in the infra repo

## 8b. Post-review hardening (2026-09-22)

- [x] 8b.1 Open-source telemetry ping moved to a bounded one-shot task (`CustomWifi::sendOpenSourceTelemetry()` spawns `_telemetryTask` per attempt): explicit 10 s connect/handshake timeouts, at most `TELEMETRY_MAX_ATTEMPTS` (5) per boot, 10 min apart, so neither the WiFi task nor the eth task tick is stalled on a firewalled or LAN-only network
- [x] 8b.2 Eth task reported in system info: `customEth` entry in the dynamic task list, only on products with Ethernet (`globalHwProfile->hasEthernet`)
- [x] 8b.3 Provisioning carve-outs (UNPROVISIONED bypass, GRACE read session, AP-origin allowlist widening) require the peer to be inside the SoftAP subnet (`CustomWifi::isApConnection(local, remote)`), not only the destination to be the AP address: with Ethernet up, lwIP accepts a wired packet addressed to the AP address
- [x] 8b.4 DNS list written under the lwIP core lock (`LOCK_TCPIP_CORE()`), every slot up to `DNS_MAX_SERVERS` rewritten; Ethernet status reports Ethernet's own captured DNS servers, not lwIP's global list
- [x] 8b.5 Static Ethernet validation rejects an IP equal to the gateway and (masks shorter than /31) the subnet's network or broadcast address
- [x] 8b.6 A failed `Network.setDefaultInterface()` rolls the arbitration decision back so the next tick retries; the Ethernet SPI bus is freed when the W5500 fails to start
- [x] 8b.7 Ethernet state in the cloud: the `wifi` named shadow carries `active_interface` and an `ethernet` object on hardware with Ethernet (no seventh shadow: the cloud allowlists the six names and stores reported state opaquely)

## 9. Hardware bring-up (BLOCKED on Pro board) - covers all hardware-only spec scenarios

- [x] 9.1 Serial-first bring-up of the Pro board (never OTA-test new pre-network boot code) - done 2026-09-19: boots, OPI PSRAM 8 MB, v1.0 profile / 12 channels, W5500 up (100 Mbps full duplex), DHCP lease ~5 s after ETH.begin, web/API/Modbus TCP served over the wire. Data path: 0.07% loss over 3000 pings, 390 HTTP downloads (59 MB) with zero errors/corruption, ~6 Mbit/s.
- [x] 9.2 Verify the netlist-derived pinout/mux map/divider values on hardware; correct any discrepancy in the v1.0 profile; verify all 12 channels measure - done 2026-09-19: ADE7953 SPI, LED, button, W5500 pins confirmed; with mains + a CT moved across all 12 inputs the mux map is exact (no profile change), idle inputs read 0.000 A with no crosstalk, voltage ~225 V on every channel (not cross-checked against a reference meter)
- [x] 9.3 Zero-touch commissioning test: factory-fresh + cable + DHCP → reachable, first-run password setup, then fully operational; no AP raised - done 2026-09-19 after fixes found by this test: boot AP was raised unconditionally, commissioned credential-less device never re-raised the AP after a wire-driven teardown, windows were power-on-relative, network LED layer never released on a wire-only device
- [x] 9.4 Failover tests on hardware: cable pull → STA, cable return → ETH, flap, static-IP backstop, button reset, DNS/NTP follow the active interface (verified 2026-09-19: static IP apply + reset-to-DHCP over the API, cable pull → STA in ~2 s, cable return → ETH after the 10 s hold-down, wire-only device raises the authenticated AP on link loss and drops it when the wire returns, button network reset clears WiFi + static config and keeps the password. 2026-09-20: DNS follows the active interface - with a static Ethernet config carrying DNS 1.1.1.1 and the WiFi lease bringing another server, the resolver goes to 1.1.1.1 when the wire takes the route and stays there; the static boot-fail counter clears 20 s after link-up, before a clean restart is possible. 2026-09-20: three-cycle cable-pull flap on the bench - each pull dropped straight to WiFi with no thrash (`Ethernet no longer serviceable (link down)` -> `ethernet -> wifi` same tick), ETH relinked and re-leased DHCP in 6-8 s, and the interface switched back exactly 9 s after link-up each time, matching the hold-down; no double-switch or oscillation across the 3 cycles. NTP-follow: `_configureNtpServers()` re-reads `CustomEth::activeInterface()` and picks `ETH.gatewayIP()` vs `WiFi.gatewayIP()` fresh on every call, and the eth task's interface-change callback calls `requestResync()`, so a resync is forced on every failover; not independently observable on this bench because both interfaces share the same LAN gateway, so a successful resync after an already-synced state logs only at DEBUG (`Time sync successful`), not INFO - confirmed correct by code inspection rather than a distinguishable on-wire result)
- [x] 9.5 Home regression on shared code: v6.1 device boots with no ETH objects created and free-heap delta within noise (< 8 KB) vs previous release - done 2026-09-19 on the Home dev unit (v6.1, factory-provisioned, cloud MQTT over TLS up): ethEnabled false and the Ethernet endpoints answer 404, 4 channels measuring, 67 GET routes OK, WiFi scan works while served over WiFi, 105-request burst with 0 failures, cloud MQTT connected and publishing. Internal heap vs the 2026-08-17 build: free 69.5 KB -> 90 KB, low-water 36.6 KB -> 54.7 KB (TLS handshake included), largest block 31.7 KB -> 43 KB
- [x] 9.6 RELEASE GATE - dual-netif heap soak: free/minFree/maxAlloc during MQTT TLS publishes and a full cloud OTA with both interfaces up (2026-09-19 progress, both interfaces up, no TLS yet: idle internal free 49.5 KB -> 89.6 KB and the floor under a 3-client web burst 22.9 KB -> 64.1 KB, from registering the web routes in PSRAM (27 KB), not running the disabled custom MQTT / InfluxDB tasks (12 KB) and sizing JSON responses once in PSRAM; the TLS MQTT + cloud OTA soak itself still needs the cloud side; 2026-09-21: a real cloud OTA job + TLS MQTT did run on this bench unit, but Ethernet-only, so it didn't count - closed properly same day: WiFi reconfigured on the Pro bench unit alongside its existing Ethernet link (confirmed both `connected:true` and `linkUp:true` simultaneously, activeInterface stayed ethernet), cloud MQTT TLS publishing meter/telemetry data continuously throughout (mqtt task ticking, staleMs~100), then a real signed cloud OTA job run against it with 1 Hz heap sampling via `/api/v1/system/info`. Idle dual-interface baseline: free 92.9 KB, minFree 70.3 KB, maxAlloc 33.8 KB. During the live TLS HTTPS download: free bottomed at 67.9 KB, the low-water minFree metric settled at 65.2 KB, maxAlloc held at 31.7 KB - comfortably clear of exhaustion. Device rebooted into the new image, both interfaces reconnected automatically, health check OK, crash archive unchanged (still 2 entries, no new one).)
- [x] 9.7 WiFi RF check with and without the external antenna - done 2026-09-19: without it the board finds no network at all (the WROOM-1U has no on-module antenna), with it RSSI -60.6 dBm mean (stdev 0.8) and 0/120 ping loss over 2 minutes. The antenna is mandatory in assembly and in the EOL RF check

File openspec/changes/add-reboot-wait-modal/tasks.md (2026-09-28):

## 1. Shared reboot-wait module

- [x] 1.1 Add `source/js/reboot-wait.js`: exposes a function that shows the dimmed modal, polls `/api/v1/health` at a fixed interval, requires one observed failure before treating a success as "back online", caps the wait with a manual fallback, and redirects to a caller-supplied target (default `/`) on success.
- [x] 1.2 Add the shared trivia fact list (moth bug, planets/Moon, China+USA electricity share, Egyptians/Romans, microwave standby, Watt/electron, octopus hearts, "read the code you're waiting on") and the carousel logic (auto-advance interval, manual prev/next that resets the timer, `prefers-reduced-motion` handling per the earlier mockup).
- [x] 1.3 Add supporting CSS for the dimmed scrim, modal box, spinner, status line, elapsed timer, and trivia strip (reuse the existing `button-spinner` keyframes from `forms.css` rather than duplicating them).
- [x] 1.4 Manually verified against the real bench device (192.168.1.82, esp32s3-dev-v5 build): plain restart shows the modal, waits past the "seen a failure first" gate (didn't redirect on an immediate/premature success), and redirects home once actually back.

## 2. Wire into configuration.html

- [x] 2.1 Replace the plain `restart()` function's `setTimeout`/`showStatus` pair with a call into the shared module (default redirect target).
- [x] 2.2 Replace the network-config-apply flow's `setTimeout` with a call into the shared module, passing the newly configured address as the redirect target.
- [x] 2.3 Confirm `factoryReset()` is left untouched (no polling, no redirect, existing reconnection instructions stay).

## 3. Wire into configuration.html's WiFi credential switch

- [x] 3.1 Replace `switchWifi()`'s "wait ~15 seconds, button stays disabled forever" ending with a call into the shared module, polling `energyme.local` as a best-effort target (corrected from the original task text, which named `wifi-setup.html`: the authenticated WiFi switch actually lives in `configuration.html`'s `switchWifi()`; `wifi-setup.html` only has the unauthenticated initial-provisioning flow, which is out of scope, see proposal.md).

## 4. Wire into update.html (non-OTA actions)

- [x] 4.1 Replace `doRollback()`'s post-success `setTimeout(() => window.location.reload(), 5000)` with a call into the shared module.
- [x] 4.2 Replace `restoreConfigSubmitted()`'s nested `setTimeout` pair with a call into the shared module.
- [x] 4.3 Filesystem restore (`restoreFilesystemSubmitted()`) does not currently redirect or restart the device. Confirmed against `customserver.cpp`: `/api/v1/restore/filesystem` extracts straight into the live LittleFS and responds success, unlike `/api/v1/restore/configuration` it never calls `setRestartSystem`. Left as-is, not wired in.

## 5. Wire into update.html (OTA update) and consolidate trivia

- [x] 5.1 Move `getRandomFact()`'s local `facts` array into the shared trivia list from task 1.2; have `getLoadingMessage()` read from the shared list instead of its own copy.
- [x] 5.2 After the OTA upload's `fetch('/api/v1/ota/upload', ...)` succeeds and the byte-progress ring completes, hand off to the shared reboot-wait module instead of the current `setTimeout(() => window.location.href = '/', 5000)`.
- [x] 5.3 Confirm the upload failure path (non-success response) is unaffected and still shows its existing error messaging without invoking the wait screen. Correction: the original check missed a bug - `update.html` treated `data.success || data.message` as success, so a failed finalize (HTTP 200 with `success:false` and a message) showed "Update successful" and opened the reboot wait. Fixed in 01d5ff1: only `success === true` counts as success.

## 6. Final pass

- [x] 6.1 Run `pio check -e esp32s3-dev` to confirm no regressions (this change is web-UI-only, but confirm no firmware files were accidentally touched). `pio run -e esp32s3-dev` and `pio check -e esp32s3-dev` both pass; 0 HIGH findings, only pre-existing MEDIUM/LOW noise unrelated to this change.
- [x] 6.2 Manually exercise every wired-in action against a real device (restart, static IP apply, WiFi switch, rollback, config restore, OTA update) and confirm consistent modal behavior and copy across all of them. Done on the bench device (192.168.1.82): restart, static IP apply (switched to a new local IP), WiFi credential switch, rollback, config restore, and a full browser-driven OTA update (including the upload-ring-to-modal hand-off and shared trivia list) all confirmed working - consistent modal, honest 3-state copy, working trivia, correct redirect target each time.
- [x] 6.3 Code review + simplification pass per this repo's PR checklist before merging to `development`. Adversarial review of `reboot-wait.js` found no real bugs (polling state machine, no-cors semantics, redirect-target safety, timer lifecycle, and OTA hand-off all checked out clean); the one real finding was spec.md/proposal.md/design.md still requiring filesystem restore to use the wait screen when the implementation and tasks.md correctly exclude it - fixed by updating the openspec docs to match. Simplification pass deduped a repeated `clearTimeout` call in `_pollHealth()`; kept all why-comments (no-cors rationale, failure-before-success gate); `pio run -e esp32s3-dev` confirmed no regressions.
- [x] 6.4 "Check again" dead-end fixed (febb92c): the fallback's retry re-ran the poll loop with the went-down gate, so a device that was already back (every poll succeeds) could never redirect. `show()` gained a `requireFailureFirst` option (default true); the retry passes `false`. Covered by `source/test/js/reboot_wait.test.js` (redirect after down/up, no redirect for a device that never went down, check-again redirect for a device already back, retry button re-polls without the gate).
- [x] 6.5 Page under the overlay is keyboard-inert: every other `body` child gets `inert` when the screen mounts (it is never dismissed, it ends in a navigation), the box is a `role="dialog"` `aria-modal` that takes focus, and the status line is `aria-live`. Verified in headless Chrome: Tab cycles only the dialog controls
- [x] 6.6 90 s cap bounded exactly: the deadline is taken at `show()` (before the 900 ms pre-delay) every poll timeout and interval is clamped to the time left, and no poll shorter than 1 s is started, so the fallback appears within the last second before the cap (unit-tested with a virtual clock)

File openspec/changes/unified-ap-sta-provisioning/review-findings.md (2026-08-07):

# Review findings

Four independent critical reviews of `proposal.md` / `design.md`. All complete.

**Status: `design.md` decisions D2, D3, D6, D7 are refuted. Migration step 4 and one Goals bullet are factually false. Do not implement from the current design.**

---

## Showstoppers

### S1. AP-only provisioning triggers reboot loop, then firmware rollback and NVS factory wipe

Found independently by two reviewers. Verified against constants.

```
_performHealthCheck gates on CustomWifi::isFullyConnected()   customserver.cpp:474
  isFullyConnected() is STA-only                              customwifi.cpp:137-148
  -> false for the entire AP-only provisioning window
5 failures x HEALTH_CHECK_INTERVAL_MS 30s -> setRestartSystem  customserver.h:51,53
  reboot at ~150 s uptime
  150 s > QUICK_RESTART_THRESHOLD 60 s   -> safe mode never arms      crashmonitor.h:34
  150 s < COUNTERS_RESET_TIMEOUT 180 s   -> _consecutiveResetCount never resets  crashmonitor.h:31
  -> counter climbs every boot                                crashmonitor.cpp:175
  -> at MAX_RESET_COUNT (10 prod / 30 dev) -> Update.rollBack() + user-NVS wipe  crashmonitor.cpp:315-343
```

Approximately 25 minutes in provisioning mode destroys user configuration on a production build.

Currently masked only because `main.cpp:151` blocks in `setup()` until STA is up, so `CustomServer::begin()` (`main.cpp:176`), which starts the health-check task (`customserver.cpp:151`), is never reached with STA down. **D7 removes that mask.** The design's Impact section does not mention `_performHealthCheck`.

Fix options: introduce `CustomWifi::isNetworkServiceable()` (STA connected OR AP raised and serving) for the health check to call, or defer `_startHealthCheckTask()` to the STA-connected transition. The self-probe itself is fine either way: it targets `127.0.0.1` and `/api/v1/health` already carries `.skipServerMiddlewares()` (`customserver.cpp:866`).

### S2. D3's auth-bypass mechanism does not work

`AsyncMiddlewareChain::_runChain` (`Middleware.cpp:56-71`) builds one `next` closure over an iterator; each `next()` takes `*it`, increments, and runs it. **There is no skip-to-finalizer primitive.** A middleware placed ahead of `digestAuth` that calls `next()` runs `digestAuth` next. The pseudocode in `design.md` D3 is wrong.

The working mechanism is already in this codebase. `AsyncWebServerRequest::_runMiddlewareChain` (`WebRequest.cpp:877-891`) honours `mustSkipServerMiddlewares()`, and `/api/v1/health` uses `.skipServerMiddlewares()` at `customserver.cpp:866` (the only use in the project).

Correct pattern, open handler registered first, authenticated twin second:

```cpp
server.on(path, HTTP_GET, cb).setFilter(isProvisioningOrigin).skipServerMiddlewares();
server.on(path, HTTP_GET, cb);   // authenticated fallback
```

Sound because `_attachHandler` (`WebServer.cpp:145-154`) walks `_handlers` in insertion order taking the first that passes `filter() && canHandle()`, and `_handlers` is a `std::list` (`ESPAsyncWebServer.h:1479`) with stable order.

Absorbed costs: `skipServerMiddlewares()` also drops statistics and rate limiting, so re-add per handler via `handler.addMiddleware(&rateLimit)`. Also, the actual current order is `customMiddleware -> digestAuth -> rateLimit` (`customserver.cpp:202,231,240`), not what D6 assumed.

### S3. The WiFi task cannot host the D8 state machine in its current shape

- `WIFI_EVENT_DISCONNECTED` does `delay(WIFI_DISCONNECT_DELAY)` = **15 s blocking** (`customwifi.cpp:665`, `customwifi.h:36`). Every failed STA attempt from the setup page stalls the task 15 s: no AP-client events, no DNS lifecycle, no grace-window arithmetic.
- The periodic-check `else` branch (`customwifi.cpp:742-747`) sees `isFullyConnected()` false every 30 s with no STA and calls `_forceReconnectInternal()`, which **increments `_reconnectAttempts`** (`customwifi.cpp:969`). That is the exact counter D1 uses as its AP-raise predicate. It only resets after 5 minutes of `isFullyConnected()` true (`customwifi.cpp:736`), so while the AP is up it grows monotonically from two independent sources and the predicate can never settle.

### S4. D2's channel-pinning mechanism does not exist

Verified against arduino-esp32 3.3.2 / ESP-IDF v5.5.1 binaries.

**`WiFi.softAP(ssid, pw, N)` on an already-running AP does not move it to channel N.**

- `APClass::create` (`AP.cpp:208-258`) calls `begin()` (a no-op when the AP is already enabled, `WiFiGeneric.cpp:647-659`) then `esp_wifi_set_config(WIFI_IF_AP, &conf)`.
- Objdump of `libnet80211.a` shows `wifi_softap_set_config`'s complete callee set contains no channel-setting function: no `chm_set_home_channel`, no `chm_set_current_channel`, no `ieee80211_update_channel`.
- Callers of `ieee80211_update_channel` are exactly `wifi_softap_start`, `cnx_connect_to_bss`, and the CSA/HT-coex paths. The AP's operating channel is applied at **AP start** and thereafter follows the STA at association.
- The door is closed from the other side too: `esp_wifi.h:773` states `esp_wifi_set_channel()` "should not be called when softAP has connected to external STAs". **There is no supported way to move a live SoftAP that has clients attached.**

The underlying claim that the AP follows the STA channel is VERIFIED (`esp_wifi.h:987-988`) and cannot be avoided: one radio, one home channel.

**Consequence: "phone stays associated" is false and must be removed from the design.** The salvageable form of D2 is stop-AP -> `softAPConfig` -> `softAP(ssid, pw, N)` (a fresh `wifi_softap_start` applies N) -> `WiFi.begin()`. The client still drops, but re-associates to the same SSID/BSSID on N within a few seconds, and crucially the AP does **not** move again when STA associates. That converts an unpredictable drop at the moment of success into a predictable early drop followed by stability. Smaller benefit than claimed, still a real one.

Note `esp_wifi_set_config` persists to NVS on every call (`esp_wifi.h:989`, `_persistent = true` at `WiFiGeneric.cpp:369`), so repeated channel re-pinning means repeated flash writes.

**Discriminating bench test, ~5 minutes:** raise AP, call `WiFi.softAP(ssid, pw, N)` with N != current, read `esp_wifi_get_channel()`. Unchanged primary confirms the refutation. (Evidence above is static call-graph, not runtime.)

---

## Radio findings that IMPROVE the picture

### mDNS over SoftAP works. Retire that risk row.

`CONFIG_MDNS_PREDEF_NETIF_AP=1` (`sdkconfig.h:1805`). Disassembly of `mdns_preset_if_handle_system_event` shows the `WIFI_EVENT` branch dispatching `WIFI_EVENT_AP_START` (12) to `post_mdns_enable_pcb(MDNS_IF_AP, ip4)` and `AP_STOP` (13) to disable. `mdns_init` also enables pcbs for netifs already holding an IP, so `MDNS.begin()` ordering relative to AP raise does not matter. **`energyme.local` will resolve over the AP.**

### The event-registration risk row is backwards

`NETWORK_EVENTS_MUTEX` is never `#define`d in the framework and is not set in `platformio.ini`. So `NetworkEvents::_cbEventList` (a `std::vector`) is mutated by `onEvent()`/`removeEvent()` from arbitrary tasks with **no lock**, while the `arduino_events` task iterates it (`NetworkEvents.cpp:122-147,170,183`), on a dual-core SoC. A `push_back` reallocation mid-iteration is a use-after-free.

That is the most plausible explanation for the historical crash noted at `customwifi.cpp:588-590`, and it means **registering all handlers at boot, before any event can be posted, removes the race rather than creating one.** The genuinely dangerous call is `WiFi.removeEvent(_onWiFiEvent)` at `customwifi.cpp:893` during shutdown, while events still flow. This is a latent defect in current code.

Supporting facts: callbacks run on the dedicated `arduino_events` task (4096 B internal stack), not the WiFi/lwIP task (`NetworkEvents.cpp:15,66-77`). `postEvent` does `new arduino_event_t` per event and `xQueueSend(..., portMAX_DELAY)` into a 32-deep queue (`NetworkEvents.cpp:84-101`), so a blocking callback stalls the esp_event loop task. Notify-only is correct and load-bearing. `ARDUINO_EVENT_WIFI_AP_STACONNECTED`/`_STADISCONNECTED` are cheap. Do not unmask `AP_PROBEREQRECVED` (masked by default, `esp_wifi.h:1154`).

### APSTA heap cost is smaller than the proposal implies

`proposal.md`'s "SoftAP netif plus its DHCP server consume internal RAM" is partly wrong: **both already exist in STA-only mode.** `wifiLowLevelInit` calls `esp_netif_create_default_wifi_ap()` unconditionally (`WiFiGeneric.cpp:290-292`), and `esp_netif_new_api` calls `dhcps_new()`. Incremental cost of enabling the AP is the lwIP `netif_add`, WiFi-driver AP state (beacon buffer <= 752 B), the DHCPS udp_pcb plus up to 8 lease nodes (`CONFIG_LWIP_DHCPS_MAX_STATION_NUM=8`), and second-interface buffer pressure.

**Unbudgeted cost to add to Spike 1:** the firmware currently uses `WiFiUDP` (`customlog.cpp:15`), so `DNSServer` would be the **first AsyncUDP user**, creating the global `async_udp` task: 4096 B internal stack + 32-entry queue + per-packet heap (`AsyncUDP.cpp:182-196`).

**Measure `getMaxAllocHeap()`, not `getFreeHeap()`.** The historical failure was PBUF allocation, i.e. largest contiguous free block, which fragments independently of total free.

---

## Refuted design decisions

### D6 is dead twice over

`WEBSERVER_MAX_REQUESTS 6000` / `WEBSERVER_WINDOW_SIZE_SECONDS 600` (`customserver.h:35-36`) = 10 req/s sustained. Captive-detection bursts are 4-6 requests.

Additionally `AsyncRateLimitMiddleware` is **global, not per-IP** (one `std::list<uint32_t>` per instance, no client key, `Middleware.cpp:272-300`), and `Middleware.cpp:275` computes `now - _windowSizeMillis` on `uint32` `millis()`. Below 600 s uptime this underflows to ~4.29e9 and the prune loop empties the list on every call, so **the limiter is inert during exactly the window provisioning occupies**.

Delete D6 entirely.

Unrelated pre-existing note: above 600 s uptime under sustained load the list can hold 6000 nodes, >100 KB of heap. Worth knowing given the heap constraint.

### `ON_AP_FILTER` is not an origin check

`WebServer.cpp:28-34` is `WiFi.localIP() != request->client()->localIP()`. `AsyncClient::localIP()` (`AsyncTCP.cpp:1341-1352`) returns `_pcb->local_ip`, the **destination address of the incoming SYN**, not the arrival netif. The real predicate is "destination IP is not the STA IP".

- **Loopback trips it today.** `_performHealthCheck` connects to `127.0.0.1` (`customserver.cpp:484`), so `ON_AP_FILTER` returns true for the device's own probe.
- **STA without an IP trips it.** `WiFi.localIP() == 0.0.0.0` makes it true for everything, including STA-arriving requests. This is not incidental: `STA_CONNECTING` and the DHCP-pending window inside `AP_ASSIST` are both states the design spends real time in.
- **IPv6 latent.** `CONFIG_LWIP_IPV6=y` and the listener is dual-stack (`AsyncTCP.cpp:1472-1506`); an IPv6 `localIP()` vs IPv4 `WiFi.localIP()` is always `!=`. Disarmed only because `enableIPv6()` is never called in `source/`.
- **Cross-netif destination: UNRESOLVED.** If lwIP's weak host model accepts packets destined to any local address regardless of arrival netif (`CONFIG_LWIP_IP_FORWARD=y`), a LAN host routing to the AP IP via the STA address gets the filter to return true, bypassing auth from the LAN. Needs a bench test: APSTA up, static route to the AP subnet via the STA IP, `curl http://<AP_IP>/`, log `client()->localIP()` inside the filter.

Consequence: compare against `WiFi.softAPIP()` rather than using the library helper, and treat the **state gate as carrying 100% of the safety**. The design's "triple gate" is one gate.

### `onNotFound` cannot serve captive probes

`_catchAllHandler` is assigned directly by `_attachHandler` (`WebServer.cpp:153`) **without consulting `filter()` or `canHandle()`**, so filters never apply to it, and `_skipServerMiddlewares == false` means **it runs `digestAuth`**. A captive probe to `/hotspot-detect.html` returns 401 and detection fails.

Correct approach: register each probe as an explicit route with `.setFilter(apOrigin).skipServerMiddlewares()` plus an authenticated twin. Paths: `/generate_204`, `/gen_204`, `/hotspot-detect.html`, `/library/test/success.html`, `/ncsi.txt`, `/connecttest.txt`, `/redirect`.

---

## Factual errors in the current documents

| Claim | Reality |
|---|---|
| `design.md` Goals: "Provisioning never blocks the meter, logging, or any other task" | The meter is **not** blocked today. `Ade7953::begin()` (`main.cpp:131`) starts five tasks before the WiFi wait, and `main.cpp:148-150` says so explicitly. What blocks is `setup()`, whose task is deleted at `main.cpp:214` |
| Migration step 4: diagnostic data "is already in the main UI's info page" | False. `_lastDisconnectReason` / `_lastDisconnectSSID` / `_lastDisconnectBSSID` / `_lastDisconnectRSSI` / `_getDisconnectReasonString` exist only as file-statics (`customwifi.cpp:42-45,464-506`), consumed only by `/diagnostic`. No getter in `customwifi.h`; nothing in `src/`, `include/`, `html/`, `js/` references them. Removing WiFiManager destroys this data unless the change adds an API for it. Same for the log-tail download (`customwifi.cpp:339-380`), reachable today with no WiFi, whereas the main UI `/log` needs auth + STA |
| Impact list omits | `customserver.h:6` includes `<WiFiManager.h>` directly. Build break in a file the plan never mentions |
| Impact list omits | `resetWifi()` calls `wifiManager->resetSettings()` (`customwifi.cpp:772-776`), reachable from the button (`buttonhandler.cpp:282`) and `/api/v1/network/wifi/reset`. Needs an `esp_wifi_restore()` / `nvs.net80211` erase replacement |
| Impact list omits | `_lastAttemptedSSID` comes from `wifiManager->getWiFiSSID(true)` (`customwifi.cpp:550`); needs `esp_wifi_get_config()` |
| Impact list omits | `_isPowerReset()` + `WIFI_CONNECT_TIMEOUT_POWER_RESET_SECONDS` (5 min, `customwifi.h:32`) live **inside** `_setupWiFiManager` (`customwifi.cpp:170-179`), which the plan deletes wholesale. Today a power cut gives the router 5 minutes to boot. Under D1, N failures raise the AP, so **every household power blip would leave mains-powered meters broadcasting a SoftAP** |
| Risk table lists "WPA2 on the AP" as a mitigation | Contradicted by the design's own open question. Now answered: `manual/02-setup.md:14` states DEVICE_ID is printed on the device label, and `_resolveApPassword` falls back to DEVICE_ID (`customwifi.cpp:989-1003`), which is also the SSID suffix. The WPA2 story is as weak as suspected |
| Spike 1 scope | Measures "STA vs APSTA under navigation + Modbus load". The dangerous configuration is the one D7 creates: unprovisioned first boot where `CustomTime`, `IssueRegistry`, `CustomServer`, `ModbusTcp`, `Mqtt`, `CustomMqtt`, `InfluxDbClient` all start for the first time with no route, concurrent with SoftAP + DHCP + DNS. **The blocking gate as specified cannot fail in the scenario most likely to break** |

---

### D5's routing rationale is worded wrong, and the real behaviour is worse

lwIP does **not** do longest-prefix match. `ip4_route` (disassembled from `liblwip.a`) walks `netif_list` and returns the **first** netif that is UP + LINK_UP + has a non-zero address + satisfies `(dest ^ netif->ip_addr) & netif->netmask == 0`. And `netif_add` **prepends**. So an AP raised *after* STA is up sits at the head of the list and **wins every ambiguous match**: LAN-destined traffic exits the AP. The conclusion holds and is sharper than stated.

Hard constraints on the AP subnet from `NetworkInterface::config`:
- **CIDR restricted to /24 through /28** (`NetworkInterface.cpp:440-443`); hard fail outside that range.
- DHCP lease pool is **10 addresses** starting at `ap_ip + 1` (`NetworkInterface.cpp:448-453`).

`softAPConfig()` before `softAP()` is required, but it calls `AP.begin()` -> `enableAP(true)` (`WiFiAP.cpp:71-73`), so it **raises the AP interface before SSID and channel are set**, briefly beaconing the previous or NVS-stored config. Correct sequence:

```
softAPConfig(ip, gw, mask, leaseStart, dns)   // raises AP netif, sets ip_info + dhcps
softAP(ssid, pw, channel)                     // wifi_softap_start applies the channel
wait ARDUINO_EVENT_WIFI_AP_START
enableDhcpCaptivePortal()                     // requires started()
```

### D4 x D5 interaction that neither document caught

`DNSServer::start()` (no-arg) sets `_resolvedIP` **only if it is currently 0** (`DNSServer.cpp:21-32`) and never refreshes it. If D5's runtime backstop changes the AP IP on subnet collision, a subsequent `start()` answers with the stale address.

**Fix: always call `start(53, "*", WiFi.softAPIP())`** (`DNSServer.cpp:41-56`), which unconditionally assigns `_resolvedIP`; `"*"` clears `_domainName` for catch-all mode.

Also: the deferred netif-aware responder is far cheaper than the "~60 lines" estimated. `AsyncUDPPacket` already carries the arrival interface via `localIP()` and `interface()` (`AsyncUDP.h:79-81`), so a custom handler needs one `if (pkt.localIP() != apIP) return;`. Stock `DNSServer` exposes no hook, so lifecycle-gating remains the v1 answer.

### Scan is workable but must be constrained

- `scanNetworks` calls `WiFi.enableSTA(true)` (`WiFiScan.cpp:75`). AP -> APSTA does **not** stop the AP (`wifi_stop_old_mode(old=2, new=3)` skips both stop branches).
- `esp_wifi_scan_start(&config, false)` is always non-blocking (`WiFiScan.cpp:93`); `async=false` merely blocks the caller for up to the 60 s `_scanTimeout`. Use async.
- Arduino memsets the scan config, so `home_chan_dwell_time` takes the driver default of **30 ms** (`esp_wifi.h:511`). With Arduino defaults (`max_ms_per_chan=300`, all channels) a full scan runs ~4.3 s with the AP on its home channel roughly **9% of the time**, against a 100 ms beacon interval (`AP.cpp:230`). Clients usually survive but interactive traffic stalls hard and the iOS captive assistant may bail. **Constrain `max_ms_per_chan` to ~120 ms or scan a channel subset.**
- `esp_wifi_scan_start` returns `ESP_ERR_WIFI_STATE` while STA is connecting (`esp_wifi.h:520`). Do not scan during `STA_CONNECTING`.

### `enableDhcpCaptivePortal` verified

`APClass::enableDhcpCaptivePortal` (`AP.cpp:309-346`) sets `ESP_NETIF_CAPTIVEPORTAL_URI` = **DHCP option 114** (RFC 8910), value `"http://<softAPIP>"`. It **requires `started()`** (`AP.cpp:315-318`) and stop/starts DHCPS around setting the option. Compiled in only for ESP-IDF >= 5.4.2; satisfied at 5.5.1.

---

## Additional traps for implementation

1. **`_validateRequest` + `_sendJsonResponse` = permanent `_apiMutex` deadlock.** `_validateRequest` (`customserver.cpp:316-335`) ends by acquiring the mutex; it is released only in `_sendSuccessResponse` (`:264`) and `_sendErrorResponse` (`:275`), **not** `_sendJsonResponse` (`:248-254`). A `GET /wifi/scan` following that pattern wedges the whole write API. Existing GETs (e.g. `:1743`) correctly skip both.
2. **Never block in a request handler.** AsyncTCP is single-threaded; `API_MUTEX_TIMEOUT_MS` is 2000 with a comment warning of WDT crashes (`customserver.h:64`). `POST /connect` must only `xTaskNotify` the WiFi task and return. Scan must be async with cached results.
3. **`AsyncCallbackJsonWebHandler` requires `Content-Type: application/json`** (`AsyncJson.cpp:125-140`). A form-encoded POST from a captive webview misses the handler and falls to the catch-all.
4. **Filters run on the AsyncTCP task for every request to every path** (`WebServer.cpp:145-154`, before `_runMiddlewareChain` at `WebRequest.cpp:868`). The provisioning filter must be an atomic state read plus an IP compare. No mutex, no NVS, no logging. This constrains how provisioning state is exposed.
5. **Register all routes at `begin()`**, gate at request time. Adding handlers after `server.begin()` works but is unsynchronized against the AsyncTCP task.
6. **Static-asset carve-out is ~14 routes** (`customserver.cpp:762-807`). Either AP-side duplicates, a `/css/*` prefix handler registered before the exact matches, or inline the setup page's CSS.
7. **LED priority collision.** `_ledTask` accepts when `priority >= currentPriority` (`led.cpp:131`), last-write-wins on ties. In AP mode `WIFI_EVENT_DISCONNECTED` fires `pulseBlue(PRIO_MEDIUM)` repeatedly (`customwifi.cpp:660`), stomping any AP pattern at MEDIUM. URGENT collides with button feedback, CRITICAL with safe-mode purple (`main.cpp:203`) and `resetWifi` orange (`customwifi.cpp:763`). Also a lower-priority command is re-queued forever (`led.cpp:145`) against `LED_QUEUE_SIZE 10`.
8. **Button: only the `<2 s` slot is free** (`buttonhandler.cpp:179-205`, `buttonhandler.h:20-24`; 2-5 s restart, 5-10 s password reset, 10-15 s WiFi reset, 15-20 s factory reset). Practical window ~150 ms-2 s after debounce. An accidental tap would broadcast an AP whose PSK is the label value.
9. **Backup/restore can drive the device into provisioning.** `wifi_ns` (static IP, gateway, subnet, `staticFails`) is backed up and restored (`utils.cpp:1934-1945`, `:2146`), and restore runs at `main.cpp:81-85` before `CustomWifi::begin()`. A backup from a different LAN pushes a foreign static IP; D5's subnet comparison then reasons about someone else's network. STA credentials are safe (`nvs.net80211` excluded, `constants.h:57-61`).
10. **Boot-order consequences with no network** (all verified): `CustomLog` safe but UDP logs are dropped from the queue front the whole time, so UDP debugging will not work during provisioning. `CustomTime::begin()` passes `WiFi.gatewayIP()` = `0.0.0.0` as the primary NTP server (`customtime.cpp:242-244`) and that stale value persists until the next sync interval after STA comes up. `IssueRegistry` raises `ntp_not_synced`, `cloud_mqtt_disconnected`, `custom_mqtt_connect_failed` for the whole window plus undeliverable raise-edge publishes. `ModbusTcp` binds all interfaces (`modbustcp.cpp:22`), unauthenticated on the AP. `Mqtt` / `CustomMqtt` / `InfluxDbClient` are **safe**, all gate on `isFullyConnected()` before connecting. `startMaintenanceTask` heap threshold is 1 KB (`utils.h:59`), so it provides **no guard** against the APSTA heap risk; that failure mode is silent PBUF starvation, not a restart.
11. **Stale user-facing strings**: `configuration.html:315` ("with no password"), `:320`, `:449`, `:476`, `:480` (192.168.4.1); `customserver.cpp:1690`, `:1737` (both promise a restart); `manual/02-setup.md:14-18`; `resources/swagger.yaml`.
12. **`_serveNetworkEndpoints` already owns `/api/v1/network/wifi/`** (`customserver.cpp:1683-1785`), and its `credentials` handler is `new`'d without `static` (`:1695`), unlike the pattern elsewhere. Do not copy that. Decide whether `credentials` keeps save-and-reboot semantics for API compatibility.
13. **New-file plumbing for a setup page** needs three coordinated edits: `platformio.ini` `board_build.embed_txtfiles`, an `extern ... asm("_binary_html_setup_html_start")` pair in `include/binaries.h`, and a `server.on()` in `_serveStaticContent`. Flash is a non-issue (`app0` = 4.5 MB vs ~2 MB image).

---

## Confirmed as specified

- **`lib/` + `test/` shape.** `source/lib/wifi_provisioning/wifi_provisioning.h` (+ optional `.cpp`); both header-only (`lib/phase_utils`) and split (`lib/duration_format`) are precedent. SPDX header, `#pragma once`, `<cstdint>`/`<cstddef>` only, no Arduino/FreeRTOS/ESP headers. Test at `source/test/test_wifi_provisioning/test_wifi_provisioning.cpp` with explicit `main()` + `UNITY_BEGIN/RUN_TEST/UNITY_END`. **No `platformio.ini` change needed**; `[env:native]` has no `test_filter` and LDF resolves from the include. Run `pio test -e native` from WSL.
- **Flash / partitions**: non-issue.

---

## AP-side OTA exposure: reviewed and ACCEPTED

The reviews flagged this as a security issue. **The team assessed it and accepted the risk.** Recorded here so it is not re-raised.

Mechanism, for the record: `customwifi.cpp:397` puts `"update"` in the WiFiManager menu, which registers the OTA upload page (`WiFiManager.cpp:658-659`). WiFiManager's auth is hard-disabled (`WiFiManager.cpp:1312-1313`, `bool testauth = false; if(!testauth) return;`), so while the portal is up the upload page is reachable by anyone who can join the AP.

**Rationale for acceptance:**
- OTA over the AP is a deliberate **recovery path**. It is how a device with bad firmware or an unreachable network is rescued in the field without physical disassembly. The reviews scored it purely as attack surface and never weighed that.
- Exposure requires RF proximity plus, in most cases, forcing the portal up via deauth.
- Factory devices carry a real AP password on a case sticker (`manual/02-setup.md:11-13`), so the WPA2 layer is meaningful for the shipped fleet. Only community/self-built devices fall back to `DEVICE_ID` (`customwifi.cpp:1000`), which is the SSID suffix.
- The WiFiManager portal is slated for replacement, and the successor UI puts OTA behind digest auth, giving WPA2 + login rather than WPA2 alone. That is a net improvement over today.

**Design requirement this creates for the replacement:** OTA must remain reachable over the AP. It should sit behind the web password (not in any auth-bypass allowlist), which means the AP-side OTA rescue no longer covers the "user forgot the web password" case that today's unauthenticated portal happens to handle. Decide explicitly whether that case needs a separate escape hatch (the existing 5-10 s button press already resets the web password, `buttonhandler.cpp:179-205`), rather than losing it by accident.

## Remaining items, unrelated to the above

1. **`configuration.html:315` tells users the AP has "no password"**, contradicting `_resolveApPassword`. `manual/02-setup.md:11-13` documents it correctly. Straight documentation defect; fix opportunistically.
2. **Default web credentials** `admin` / `energyme` (`customserver.h:57-58`). Pre-existing, orthogonal to this change.
3. **`AP_ASSIST` has no timeout in the current design.** Today `startConfigPortal()` times out after `WIFI_PORTAL_TIMEOUT_SECONDS` and `customwifi.cpp:694` restarts, bounding the AP window to 5 minutes per boot. The design must not silently drop that bound; it is also what stops a device stuck in `AP_ASSIST` from broadcasting indefinitely after, say, the owner moves house.

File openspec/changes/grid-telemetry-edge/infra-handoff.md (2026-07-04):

# Infra handoff: grid telemetry ingestion (copy-paste brief for energyme-infra)

> Edge contract fixed by EnergyMe-Home change `grid-telemetry-edge` (issue #157 + grid-telemetry ADR).
> Firmware ships Stream A only; everything below is the cloud side to build.

## Contract (fixed by firmware)

- **Topic:** Basic Ingest, new IoT rule `energyme_home_dev_rule_grid` / `energyme_home_prod_rule_grid` (same naming and env split as the existing meter/log rules); device publishes to `$aws/rules/<rule>/energyme/home/<device_id>/grid`.
- **Payload:** batched, ~1 message per existing publish cadence (~30 s), bare JSON array of positional triplets:
  `[[<t unix_ms uint64>, <f Hz float 4-dec>, <v V float 1-dec>], ...]`
  e.g. `[[1751500000003, 50.0123, 230.1], [1751500000502, 50.0119, 230.2]]`
  - `t` = true device wall-clock read at sample time, aligned near absolute .000/.500 boundaries (NTP-quality, ±10-50 ms typical); array sorted ascending; gaps are real (gated ticks), never interpolated.
  - `f` = EMA-filtered grid frequency (~0.8 mHz resolution, ~1 Hz bandwidth), 4 decimals; `v` = per-device RMS voltage (local signal - never aggregate across devices), 1 decimal.
  - No envelope object: adding fields later means a new topic/rule version, not an in-place schema change.
- **Report flag:** `send_grid_data` boolean in the writable `system` named shadow (same mechanism as `send_power_data`), persisted on device, default **off**. This is the quorum on/off lever.

## Work items (cloud)

1. **IoT Core policy**: allow the new Basic Ingest rule publish for device certs (extend the provisioned policy template alongside meter/log).
2. **IoT rule + anonymizing ingest Lambda**: resolve `device_id -> synchronous zone / geohash` from provisioned location, write zone-tagged records, **drop `device_id` before any write** (load-bearing privacy control - grid tables must never receive it; see ADR Decision 6).
3. **Quorum manager**: per-zone selection of 5-15 reporting devices, rotate membership, flip `send_grid_data` via the shadow desired state (remember the write-to-change-then-null-desired contract).
4. **Storage**: hot InfluxDB (1-3 d) + Iceberg/Parquet cold tables per ADR Decision 5 (`grid_frequency_raw` short retention, `grid_frequency_consensus` long, `grid_voltage` long), all keyed by zone, day-partitioned, reusing the Firehose plumbing.
5. **Consensus compute**: per-zone median across the quorum per 500 ms bucket (bucket by nearest .000/.500; dedupe by bucket per device).

## Notes for the ingest design

- Devices only emit when NTP-synced, flag on, and the measurement actually updated - so absent points are meaningful (offline / line-dead / not in quorum), not errors.
- QoS0 likely (redundant fleet data); tolerate duplicates and out-of-order batches idempotently (bucket + zone dedupe).
- Chronically misaligned timestamps (far from .000/.500) indicate a bad device clock - down-weight, don't reject the zone.

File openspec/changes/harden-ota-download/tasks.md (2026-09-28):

Each numbered group is one commit. Run the applicable tests before committing each group rather than batching them.

## 1. Extract the backoff schedule into a host-testable module

- [x] 1.1 Create `source/lib/backoff_schedule/backoff_schedule.h` and `.cpp` following the `source/lib/version_compare/` pattern: SPDX header, `#pragma once`, a `BackoffSchedule` namespace, and a header comment documenting the clamping and overflow behaviour
- [x] 1.2 Move the body of `calculateExponentialBackoff` (`source/src/utils.cpp:1070`) into the module as a pure function taking attempt, initial interval, max interval and multiplier, keeping the existing attempt-0 and overflow-clamping semantics
- [x] 1.3 Reduce `calculateExponentialBackoff` in `utils.cpp` to a thin forwarder so `influxdbclient.cpp` and every other existing caller is untouched; leave the declaration in `utils.h` in place
- [x] 1.4 Add native Unity tests under `source/test/` covering the 2/4/8/15/15 minute schedule for attempts 1-5, attempt 0 returning zero, clamping at the max interval, the `multiplier == 2` bit-shift branch, and a large attempt number that would overflow
- [x] 1.5 Run `pio test -e native` from WSL and confirm the new tests pass
- [x] 1.6 Run `pio run` and confirm both firmware environments still build

## 2. Remove the dead pause/resume API

- [x] 2.1 Delete `Ade7953::pauseTasks()` and `Ade7953::resumeTasks()` from `source/src/ade7953.cpp:562-582` and their declarations at `source/include/ade7953.h:619-620`
- [x] 2.2 Confirm by grep that no callers remain anywhere under `source/`, then run `pio run`

## 4. Retry the download on an exponential backoff

- [x] 4.1 Add constants to `source/include/mqtt.h` for max attempts (5), initial backoff (2 min), max backoff (15 min) and multiplier (2), each with a comment tying the schedule to the 60 minute presigned-URL lifetime
- [x] 4.2 Superseded by the actual shape: `_performOtaUpdate` keeps returning a bare `bool`; the `esp_err_t` and byte progress instead land in a shared `OtaAttempt` struct that the HTTP event handler also writes into, since that handler is a C callback with no context of its own and shared state is unavoidable there
- [x] 4.3 Capture bytes received and content length from the existing `_otaHttpEventHandler` counters (`source/src/mqtt.cpp:1439-1449`) into that struct so progress survives the failing call
- [x] 4.4 Wrap the `_performOtaUpdate` call in `_otaTask` (`source/src/mqtt.cpp:1508`) in a retry loop using `BackoffSchedule`, leaving the DNS probe at `mqtt.cpp:1463-1475` to run once per download rather than once per attempt
- [x] 4.5 Superseded: this described a `_otaDownloadInProgress` MQTT-publish-suppression flag. That mechanism was implemented, reviewed, and then removed in `27df03a` once the actual per-publish internal-RAM cost turned out to be ~256 bytes, not the 16-20 KB the originating issue assumed; see `design.md`'s "No publish suppression during the download" for the full reasoning
- [x] 4.6 Verify the post-download flow (partition read, SHA256, preferences, reboot) and its three early returns at `mqtt.cpp:1516`, `1526` and `1540` are unchanged and sit outside the retry loop
- [x] 4.7 Sleep between attempts in a way that still honours the module's existing shutdown notification, so a restart request during a backoff wait is not blocked for up to 15 minutes
- [x] 4.8 Run `pio run`

## 5. Report device-side diagnostics on failure

- [x] 5.1 Extend `_publishOtaStatus` (`source/src/mqtt.cpp:2747`) to accept optional diagnostic details and emit them as sibling keys of `reason` in `statusDetails`, leaving `reason` unchanged and every existing call site working as before
- [x] 5.2 Render each value into a small `char` buffer with `snprintf`, since `statusDetails` is a string-to-string map, and keep every key within 128 chars matching `[a-zA-Z0-9:_-]+` and every value within 1024 chars and free of control characters
- [x] 5.3 Populate `espError`, `httpStatus`, `progress`, `heapFreeMinMax` (free/min-free/max-alloc merged into one key, keeping the pair count well clear of the `statusDetails` limit), `attempts`, `uptime` and `rssi` on the download-failure path only
- [x] 5.4 Sample the heap figures immediately after the failing `esp_https_ota()` returns inside the retry loop, not after the loop unwinds, so they describe the moment of failure
- [x] 5.5 Confirm the other `FAILED` reasons (`partition_error`, `sha256_read_error`, `preferences_error`, `sha256_mismatch_firmware_rollback`) report exactly as before
- [x] 5.6 Add a DEBUG log line with the same heap figures before and after each attempt, so the same data is visible over the UDP log without waiting for the job status - implemented in 2008981 (`OTA attempt start heap` / `OTA attempt end heap` in `_performOtaUpdate`); the same commit omits `heapFreeMinMax` for deterministic post-download rejections instead of reporting `0/0/0`
- [x] 5.7 Run `pio run`

## 8. Make the download path testable on hardware

- [x] 8.1 Add a dev-only `POST /api/v1/ota/inject-job` that routes a synthetic job document through the same validate-and-handle path the broker RX uses, following the existing `inject-command` / `inject-delta` pattern. Without it the download failure modes could only be reached by minting real AWS jobs
- [x] 8.2 Stage the injected payload onto the MQTT task rather than handling it inline: the caller is the web server task, and `_handleSingleJobExecution` publishes `IN_PROGRESS` on the shared, unsynchronised `PubSubClient`
- [x] 8.3 Give it its own pending slot so an injected job and an injected command cannot evict each other

## 6. Verify on hardware

Bench device `588c81c479f8` at 192.168.1.82, `esp32s3-dev-v5`, dev AWS account.
Driven through the dev-only `POST /api/v1/ota/inject-job` seam added in group 8
for the synthetic cases, and through real AWS IoT jobs for the end-to-end ones.

- [x] 6.1 Flash the bench device and confirm a normal OTA job still succeeds end to end with no regression to job status reporting or the reboot-and-validate flow — real AWS job `energyme-home-dev-ota-e2e-retry-20260813-145616` against a genuine presigned S3 URL: downloaded 2.6 MB on attempt 1 in 94 s, rebooted, booted the delivered image, and reported `SUCCEEDED` after the 300 s validation window. Status walked `downloading` → `rebooting` → `SUCCEEDED`
- [x] 6.2 Confirm telemetry, logs and shadow updates keep flowing normally for the whole retry schedule, since nothing is suppressed any more — the `meter` shadow was 98 s old when checked mid-schedule, during the attempt-4 backoff
- [x] 6.3 Using a dev build, run an OTA job with a deliberately unreachable host to exercise the full retry schedule, then confirm the `FAILED` job execution in AWS carries all eight `statusDetails` keys with sensible values — real AWS job `energyme-home-dev-ota-fail-diag-20260813-150045` reported `FAILED` with all eight accepted, none rejected or truncated: `attempts 5`, `espError ESP_ERR_HTTP_CONNECT`, `heapFreeMinMax 52644/39028/31732`, `httpStatus 0`, `progress n/a`, `reason download_failed`, `rssi -86`, `uptime 73`. The unreachable-host schedule was also run once at the real constants, taking exactly 29 min across 5 attempts
- [x] 6.4 Confirm `httpStatus` is what separates a server refusal from a transport failure, and that a 4xx breaks the schedule instead of running all five attempts — an S3 404 reports `ESP_FAIL` + `httpStatus 404` and fails after 1 attempt in 0.65 s; an unresolvable host reports `ESP_ERR_HTTP_CONNECT` + `httpStatus 0` and runs the full schedule. This found a real defect: the status was read in `HTTP_EVENT_ON_HEADER`, which runs before the client assigns it, so every refusal reported `-1` and the break never fired
- [x] 6.5 Backoff timing verified at the real constants rather than shortened: 120 000, 240 000, 480 000 and 900 000 ms between attempts, the last being the 15 minute clamp. Shortened constants are used only for the throwaway recovery build, which is never committed
- [x] 6.6 Confirm the AWS job's `timeoutConfig` exceeds the worst-case retry window — the dev jobs set `inProgressTimeoutInMinutes: 60` against a worst case of ~44 min of download plus the ~5 min validation window. It fits, but the margin is ~10 min: raising `OTA_DOWNLOAD_MAX_ATTEMPTS` or the cap without also raising the job timeout would make executions flip to `TIMED_OUT` before the device reports
- [x] 6.8 Confirm the concurrent-job guard still holds over the widened window — this change stretches the OTA task's life from one download to ~44 min, during which MQTT reconnects re-deliver the still-`IN_PROGRESS` job. A second job injected mid-schedule was dropped before the `Received OTA Job` log line
- [x] 6.9 Confirm a failed attempt followed by a successful one on the same URL completes the download and proceeds to the post-download flow — real AWS job `energyme-home-dev-ota-recovery-20260813-150046`, with a throwaway build forcing the first two attempts to fail. Attempts 1 and 2 failed at the 5 s and 10 s shortened delays, attempt 3 downloaded the image from the same presigned URL, and the job reported `SUCCEEDED`. This is the one behaviour the change exists for, and it cannot be staged without either forcing the failures or controlling the device's uplink
- [x] 6.7 Subscribe to `jobs/+/update/rejected` (not `/update/accepted`, which would echo every progress update): a rejection is logged as ERROR with its code and message. Verified 2026-09-23 on the Pro bench (`14c19f4e1b44`): a dev job force-cancelled mid-download had both its `rebooting` IN_PROGRESS and its post-validation SUCCEEDED rejected with `InvalidStateTransition`, each logged. The device still completes a cancelled job it already started (it learns of the cancel only through these rejections); the image is signed, so this is noise, not a risk
- [x] 6.10 Heap across the full 5-attempt schedule re-measured 2026-09-23 (unresolvable host via `inject-job`, real 2/4/8/15 min backoffs, system info polled every 3 s for 35 min) on both products at HEAD. Pro (`14c19f4e1b44`, octal PSRAM): `minFreeHeap` 65 984 bytes from attempt 1 to 5, never moved; `maxAlloc` 31 732-37 876. Home (`907069875394`, quad PSRAM): `minFreeHeap` 91 436 -> 85 436, the decline coming during the 8 min backoff while the OTA task only sleeps, then flat; free heap back to ~110 KB once the task exits. No ratchet from the retry loop; the 8 128-byte reading was not reproduced on either board

## 7. Review and merge

- [ ] 7.1 Firmware version in `source/include/constants.h`: NOT part of this change. Version bumps are Jibril's call and are done manually by him, never as part of implementing a change.
- [x] 7.2 Run the code-review agents over the branch diff, with at least one adversarial brief given this touches the OTA and network path, and reproduce each finding before accepting or dismissing it. Re-run on the diff since the first pass once the hardware-testing round added the `httpStatus` capture fix and the dev-only inject-job seam
- [x] 7.3 Run the simplification agent (also re-run on the same later diff)
- [x] 7.4 Triage every finding, fix or document each with its reason, and re-run `pio run` and `pio test -e native`
- [x] 7.5 Open the PR to `development` with `Closes #191` in the body and a label
- [x] 7.6 Retitle issue #191, whose current title names the task-suspension mechanism this change evaluated and rejected - done: now "OTA: retry failed downloads and report why they failed", closed as completed 2026-08-13
- [x] 7.7 `_otaValidationTask` now calls `_validateOtaUpdate()` (early returns) and clears the pending state, the handle and the task in one place. Verified 2026-09-23 with a real dev job on the Pro bench: SUCCEEDED after the 300 s window
- [x] 7.8 WON'T DO (obsolete): `_performOtaUpdate` already uses the granular `esp_https_ota_begin`/`_perform`/`_finish` sequence (for the signature and image-descriptor gates), and it does not remove the need for `_captureOtaHttpStatus`: a refused response (403/404) fails `esp_https_ota_begin()` itself, which NULLs the handle, so `esp_https_ota_get_status_code()` has nothing to query for exactly the failure the status exists to distinguish. Original text: Follow-up, not this PR: `_captureOtaHttpStatus` works around the event-based status API; `esp_https_ota_get_status_code()` would let it collapse to one read, but only against the handle from the granular `esp_https_ota_begin`/`_perform`/`_finish` sequence, which this PR's retry loop was not built or hardware-tested against. Consider the switch once the current retry/backoff behaviour has run in the fleet

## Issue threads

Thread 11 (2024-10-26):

Question: What are the costs?

CommanderRedYT, 2024-10-26:
Hi! This is a really cool project. I was wondering how much the whole unit costs?

Also you mentioned 17 channels, but the PCB only has 10 clamp inputs. Where would I connect the other 7?

(Sorry for opening a issue, but I can't see the discussions tab)

jibrilsharafi, 2024-10-26:
Hi!

The unit cost (without the clamps) is around € 30, depending on where you source your PCB or components. The clamps then are about € 3 each.

You are right: I did not explain correctly how to reach 17 channels but I published everything in a rush. It has two expansion boards that can be placed on top of the main PCB. They are connected through standard header pins at the bottom and top of the PCB. In the documentation folder you will find all the schematics!

CommanderRedYT, 2024-10-26:
Ah, makes sense! 30€ is really cheap, thats really cool! Thanks for the cool project!

CommanderRedYT, 2024-10-26:
Hi, I have another question: How would one deal with three phases? Do I have to install one per Phase?

jibrilsharafi, 2024-10-27:
Yes, you would need to install one per phase.

CommanderRedYT, 2024-10-27:
Do you think it would be possible to contribute to the PCB and maybe add another two phases? Is it possible to have the easyeda archive for importing in kicad? (I haven't really used easyeda so I am not sure if they have something for collaboration)

jibrilsharafi, 2024-10-27:
Monitoring three-phase circuits would require many structural changes, including:
- changing the energy meter IC
- adding multiplexers
- replacing the 3.5mm jack with something smaller (otherwise the PCB will get very wide very quickly)
- re-design the high-voltage part to handle three-phase 400 V
- changing many things in the firmware as it was created to handle single-phase measurements
- the total costs will increase
Given this, I think it would be wiser to start another similar project based off this that is capable of working with three-phase instead.

You are right: in the documentation I forgot to upload the .zip containing the data about the project. Unfortunately I have never worked with KiCad so I will leave the EasyEDA backup here, hoping that you will manage to export it: [BackupProjects_jabrillo_personal_0_20241027.zip](https://github.com/user-attachments/files/17533610/BackupProjects_jabrillo_personal_0_20241027.zip).

jibrilsharafi, 2024-10-27:
I mean, now that I think about it, it is not impossible to monitor three phases.
Of course you would need to change the code and do some approximation since you would only monitor one voltage. But by assuming the same voltage and power factor, and multiplying by the current, you could have the same hardware with 17 channels to monitor up to 5 full three-phase circuits.
If you think it would be enough like this, I could work on my ideal solution.

CommanderRedYT, 2024-10-27:
Would be interesting if chips like the 78M6631 could work. The IC needs voltage and current, right? Like, it's not possible to assign the phase in software, right? With this IC you would need to have current sensor groups for L1, L2 and L3.

I mean around here the only place where people need three phase power is electric car chargers and electric stoves. Other than that, the three phases are distributed to different outlets so that they all can be the same amount.

Only problem is when you have a single-phase pv Installation (with microinverters for example) or a single-phase battery. So you could have a huge unbalanced current draw there.

Also, zero-feed-in would be interesting to implement with three separate devices.

jibrilsharafi, 2024-10-27:
I never used the 78M6631, but I guess it would work (ofc you would still need to change everything in the PCB and implement the communication specifics).

The ADE7953 which is currently used needs voltage and current. So you would need to do the assignment in the software of the ESP32 itself.

I would do it like this: in the channel configuration page (below)
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
the user should have another dropdown menu indicating the phase. Now, depending on the chosen phase, the data would be read or computed. The approximation would require using the same power factor as the main line and the same voltage but multiplied by the current of the given channel.

Does this make sense to you?

CommanderRedYT, 2024-10-27:
Okay, so in case one would use the IC three times, one would need to have sensor input groups depending on which phase.

Same power factor would work as long as you do not have a huge consumer/producer  on only one phase I think.

jibrilsharafi, 2024-10-28:
The issue with 3 ICs is that you need to have static phase inputs (for instance, all channels from 0 to 6 are phase A, 7 to 14 are phase B, etc.). This would leave less flexibility while still requiring a complete PCB change.
I will probably do some tests with the current hardware to see if reading 3-phase power is still feasible with these assumptions.

jibrilsharafi, 2024-11-07:
In the end I managed to make the three phase work in the latest pull request #12 !

jibrilsharafi, 2025-02-03:
Hi @bsaggy!
Thanks for your interest in the project! Let me address your questions:

About pick & place files: I didn't upload them for the TOP and BOTTOM boards since they have very few components. However, I can generate and upload them if you'd like to use assembly services for those boards too.

Regarding PCB manufacturing: I've always used JLCPCB myself. While I did get the first prototype assembled by them, I've since found that hand-soldering these components is quite manageable and gives me more flexibility (plus significant cost savings). This might be a route worth considering if you're comfortable trying some SMD soldering (you will need a reflow gun).

For the SCT-013 sensors: I source them from Amazon or AliExpress (I'm based in Italy). Both platforms usually have competitive prices for bulk orders.

Flashing process: You'll need to connect a standard UART programmer to the programming header on the board (which I apologize for not labelling in v4!). Connect 3V3, GND, TX, and RX, then you can either read the serial output or program it by holding both the program and reset buttons together. There's plenty of documentation online about ESP programming if you need more details.

Quick update: I'm currently **testing v5** (hopefully the **final version**), which includes some improvements like 4-layer design and optimized component placement. I'll be uploading comprehensive documentation to the development branch soon.

Feel free to open any issues if you have more questions - happy to help!

jibrilsharafi, 2025-02-03:
You're welcome @bsaggy!

Sorry, but I'd rather not go through the hassle of restoring a previous version and creating the pick-and-place files without proper revision.
In any case, I advise you to learn to solder SMD components: it will definitively allow you to step up your electronics design capabilities! You only need a hot gun, a hot plate, and solder paste.

**The current sensors MUST have an output of 1V** or less (some are 500 or 333 mV), but surely not in current. My design does not use burden resistors to further optimize components and space.

The design of v4 is already stable and tested for many months, so feel free to use that if you are in a rush. Otherwise, I will surely release the new version in the following weeks.

Closed 2025-02-07.

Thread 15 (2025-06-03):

EasyEDA Project Access

Ferido07, 2025-06-03:
Hi. This is nice work.

I am just starting on EasyEDA and hardware design and its not simple stuff to mess hardware as it is software. So I am trying to be careful here while learning.

I am looking for the most up to date project on EasyEDA. I found the following link of the backup file https://github.com/user-attachments/files/17533610/BackupProjects_jabrillo_personal_0_20241027.zip and I think it is the most up to date but I have no confirmation.
- Can you confirm if this is the latest? If so is it a Standard EasyEDA or Professional EasyEDA project?
- Can you share the project itself as a link so that the schematic is updated automatically whenever there is update. I think the sharing described at https://docs.easyeda.com/en/Introduction/Share-to-Public/ maybe enough.

Ferido07, 2025-06-11:
Thank you.

Closed 2025-06-11.

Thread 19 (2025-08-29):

C5, C12, C19 values

4q1, 2025-08-29:
the part number you listed for these caps is CC0603KRX7R9BB223, but that part is for a 22nf, not a 33nf.  Before I order parts, I'd like to know which is which. I'll probably get a kit or book anyway, but something to correct.  :)

I'm looking forward to this project. I might design a 3d printed box for it. Thanks!

jibrilsharafi, 2025-08-31:
There is a new (and what I consider "final") revision at https://github.com/jibrilsharafi/EnergyMe-Home/tree/cleanup-revision-v5. I suggest using that.
I will merge with the main branch in the following days to avoid people using the previous versions.

If you end up designing a 3D printed box, please contribute to this project and upload it! I did not do it because my whole design revolved around using an off-the-shelf case, but I would love to see a custom 3D design!

Closed 2025-09-17.

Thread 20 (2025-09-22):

Flashing firmware

4q1, 2025-09-22:
My board is almost built and I just realized that it doesn't have a USB connection (what I've always used to flash firmware to ESP devices). Can you give some insight on how to go about flashing with the S3 soldered on the board already, the hardware to accomplish this as well as the connections required?  I'm using the v5 board.  Thanks.

Closed 2025-09-27.

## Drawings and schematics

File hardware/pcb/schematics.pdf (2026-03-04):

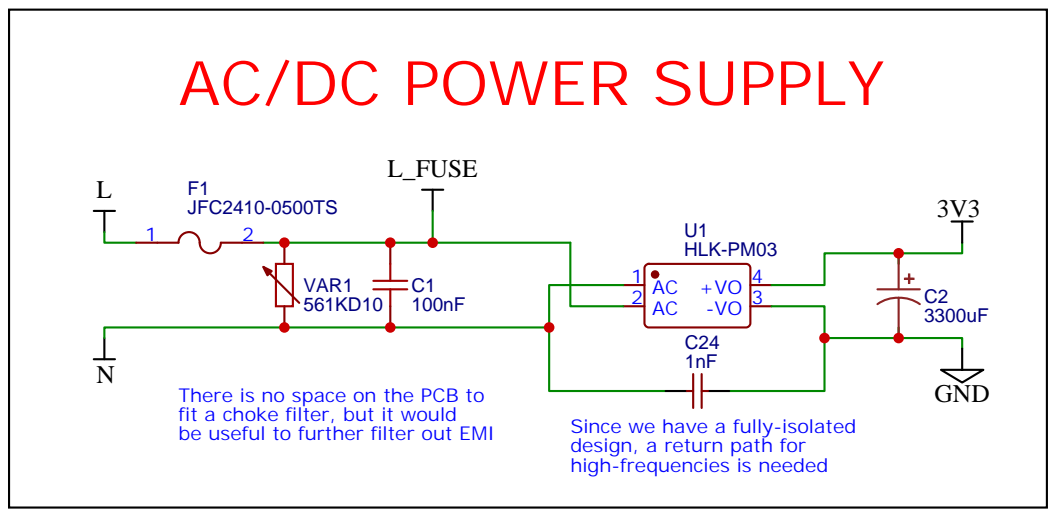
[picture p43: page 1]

AC/DC POWER SUPPLY

There is no space on the PCB to
fit a choke filter, but it would

design, a return path for
high-frequencies is needed

Drawn By: Jibril Sharafi

# MCU

# BUTTONS

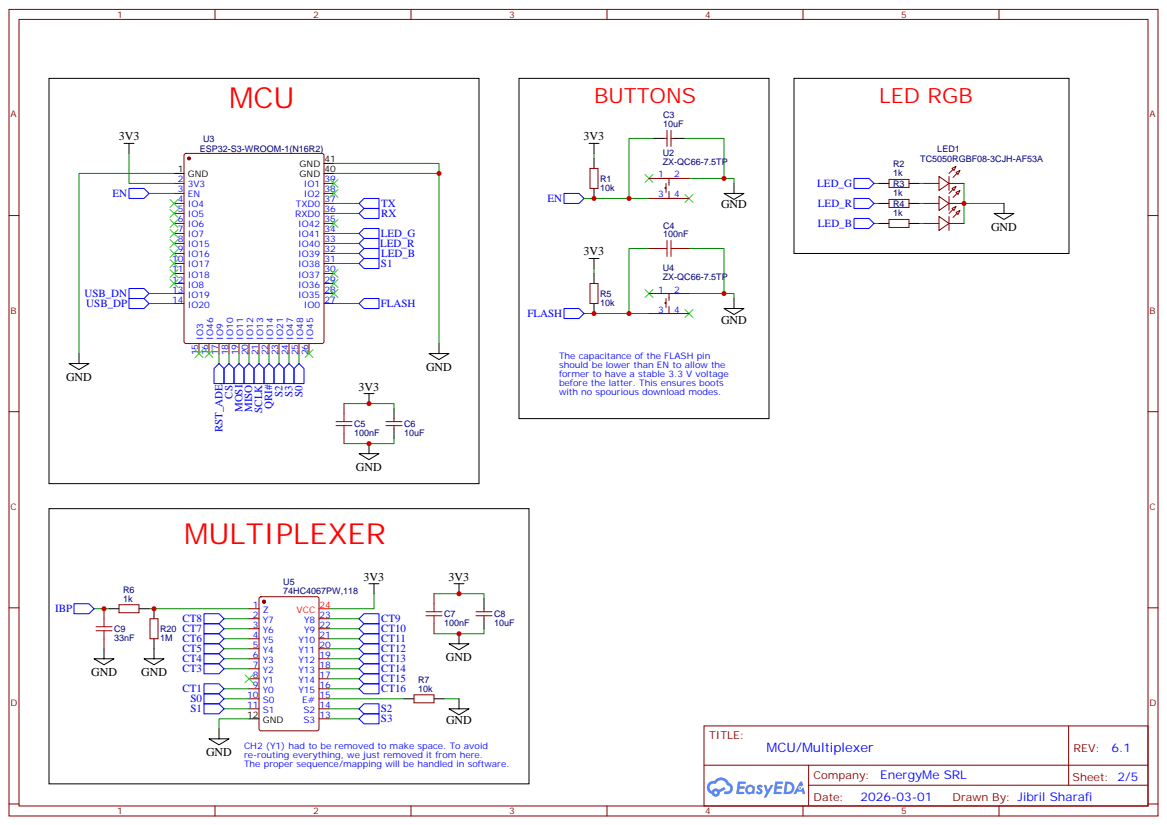
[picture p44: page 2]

IO0 27 IO⁴⁵ 26 IO⁴⁸ 25 IO⁴⁷ 24 IO²¹ 23 IO¹⁴ 22 IO¹³ 21 IO¹² 20 IO¹¹ 19 IO¹⁰ 18 IO⁹ 17 IO⁴⁶ 16 IO³ 15

The capacitance of the FLASH pin
should be lower than EN to allow the
former to have a stable 3.3 V voltage
before the latter. This ensures boots
with no spourious download modes.

CH2 (Y1) had to be removed to make space. To avoid
GND

re-routing everything, we just removed it from here.
The proper sequence/mapping will be handled in software.

TOP BOARD #1 | TOP BOARD #2

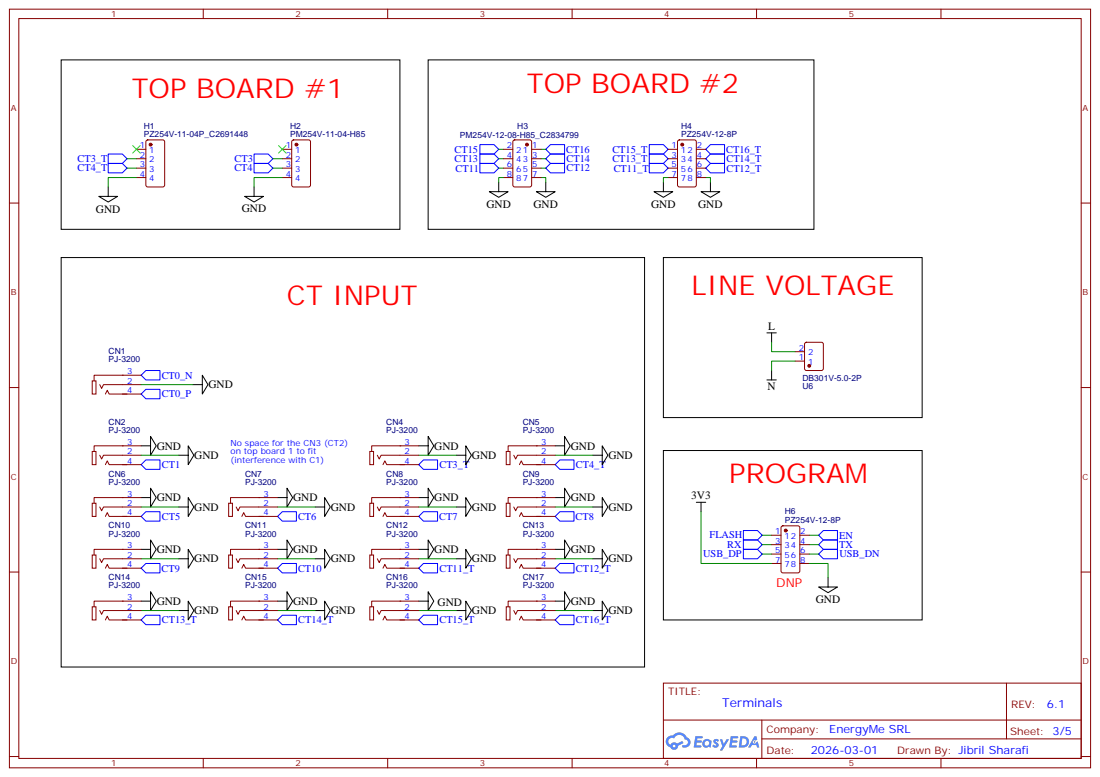
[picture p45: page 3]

No space for the CN3 (CT2)
on top board 1 to fit

# ADE7953

# RESET

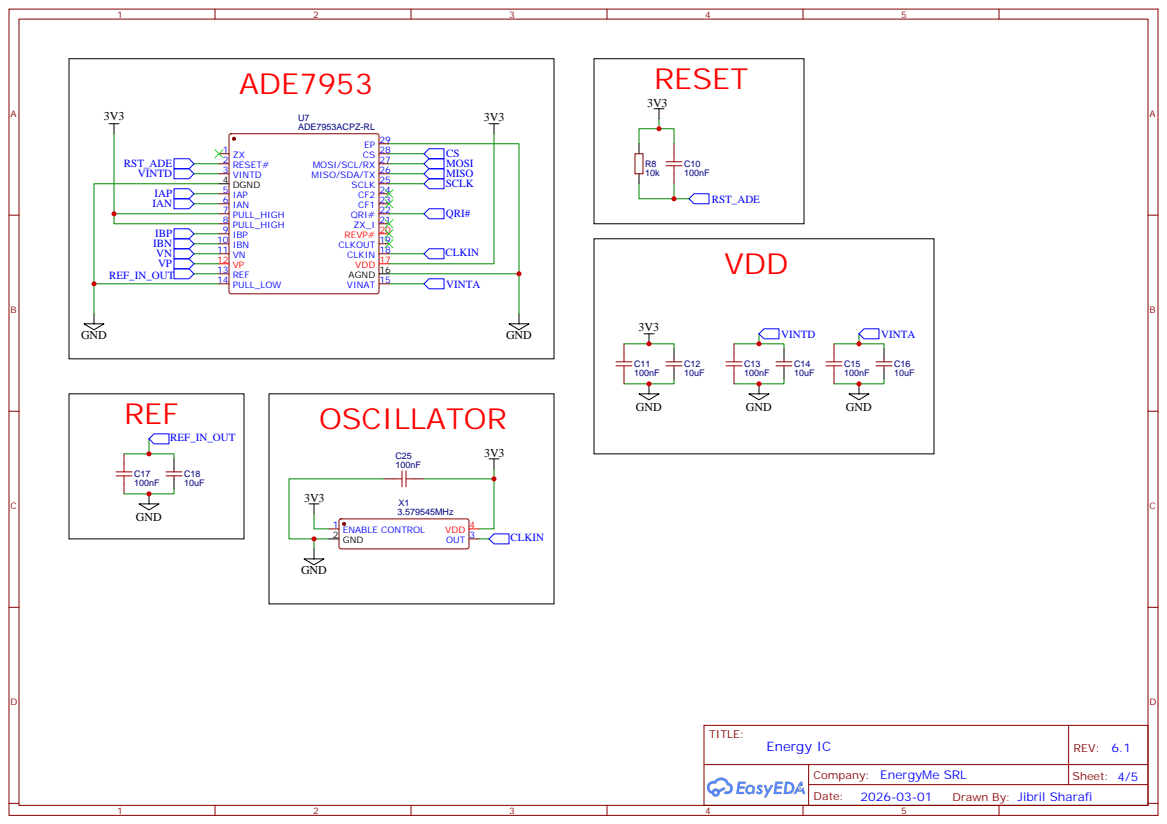
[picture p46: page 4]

# LINE VOLTAGE

# CHANNEL A L_FUSE

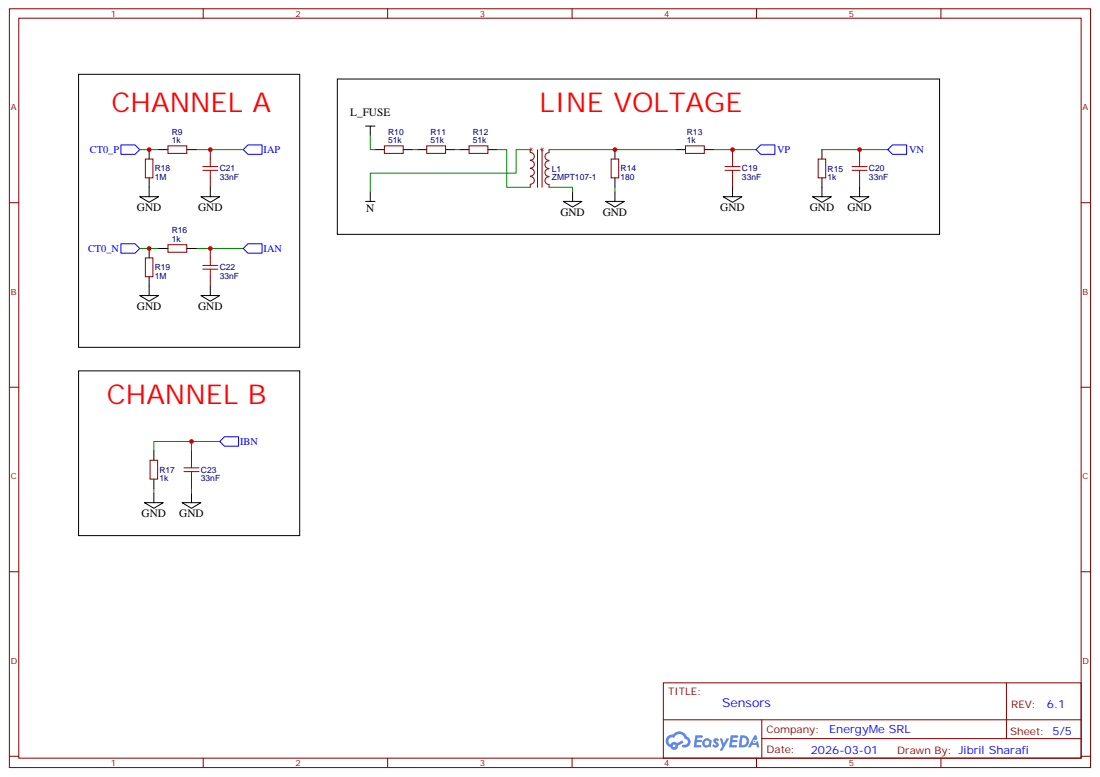
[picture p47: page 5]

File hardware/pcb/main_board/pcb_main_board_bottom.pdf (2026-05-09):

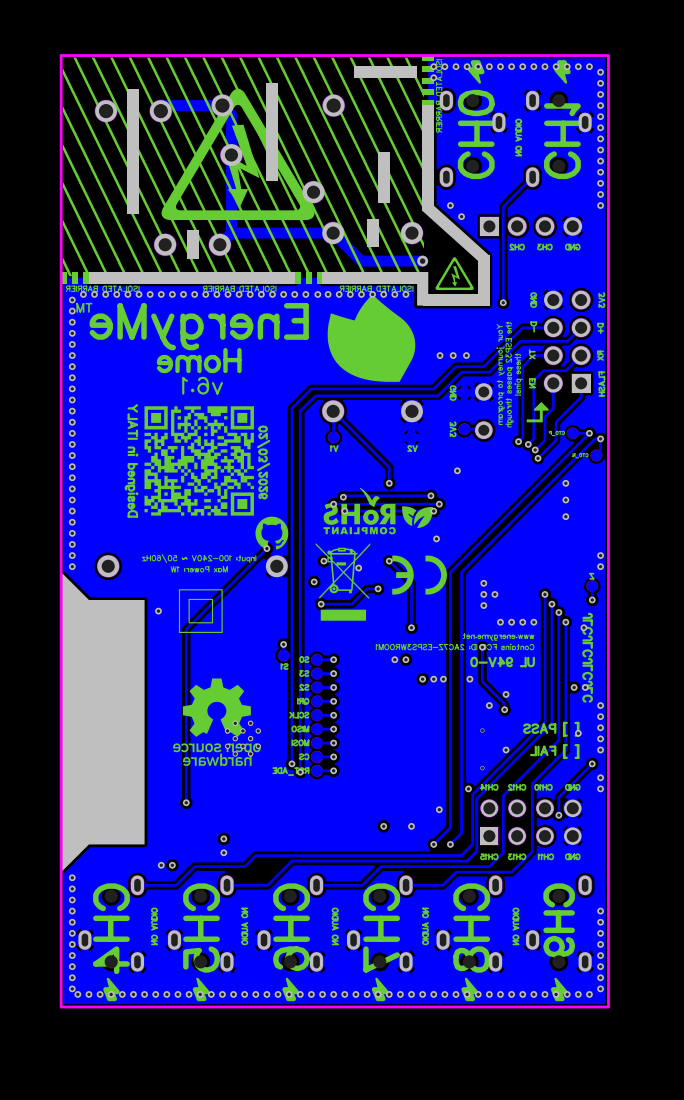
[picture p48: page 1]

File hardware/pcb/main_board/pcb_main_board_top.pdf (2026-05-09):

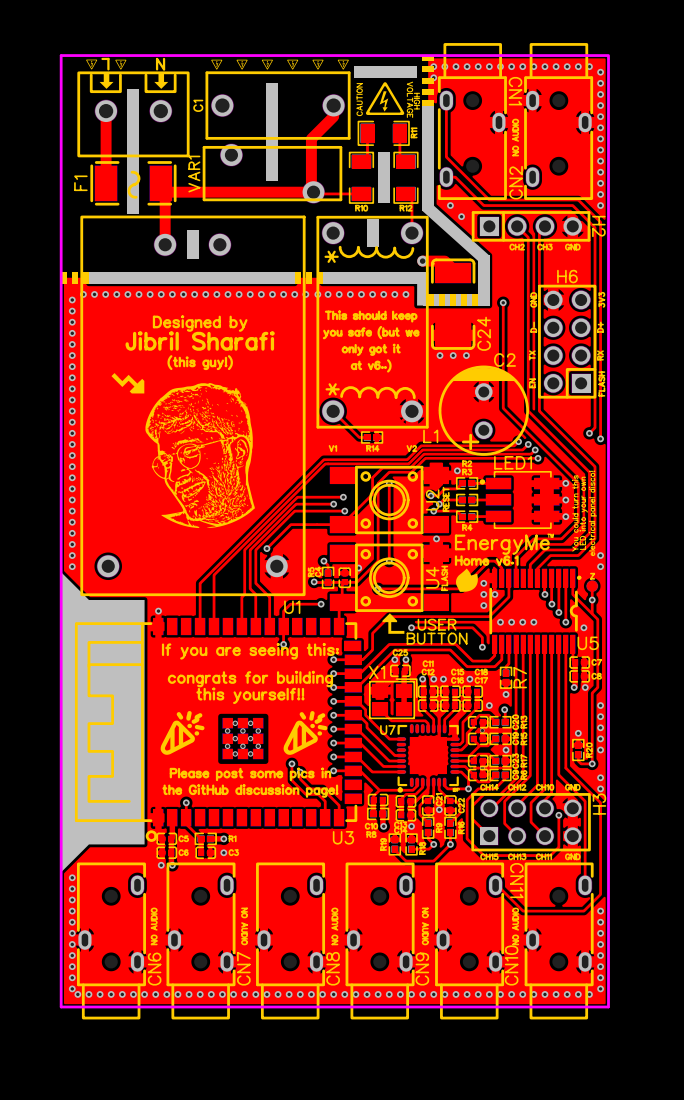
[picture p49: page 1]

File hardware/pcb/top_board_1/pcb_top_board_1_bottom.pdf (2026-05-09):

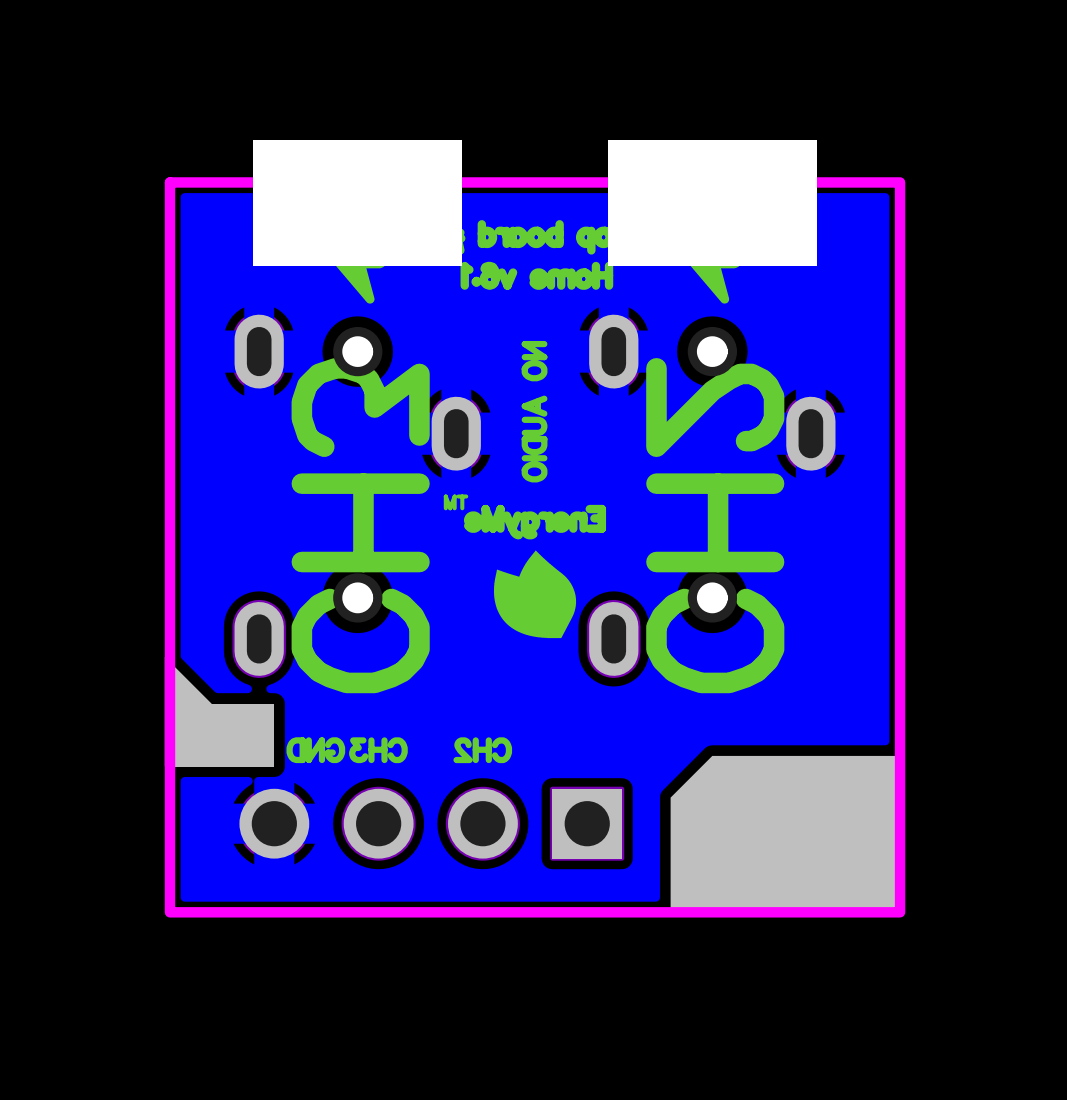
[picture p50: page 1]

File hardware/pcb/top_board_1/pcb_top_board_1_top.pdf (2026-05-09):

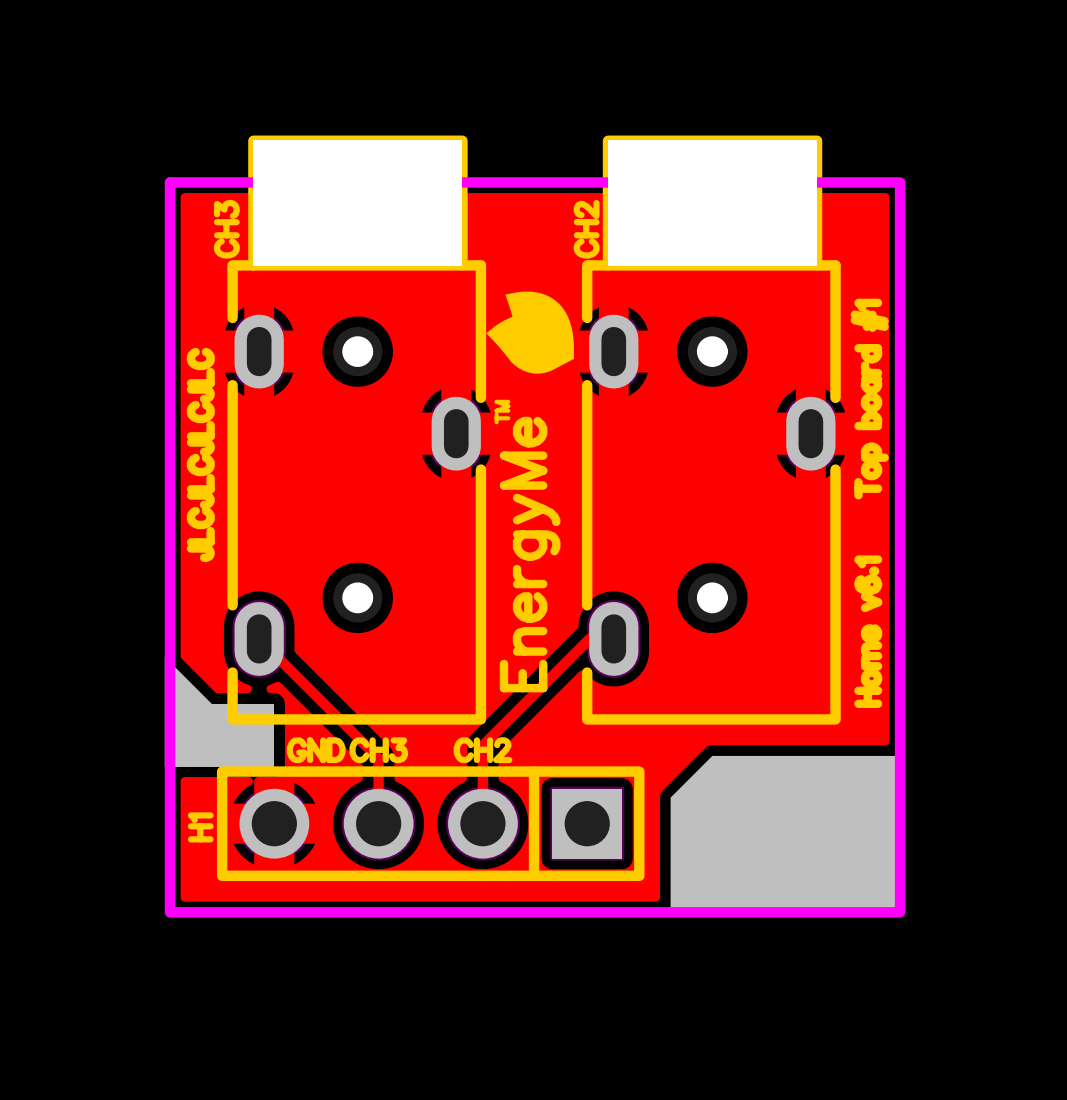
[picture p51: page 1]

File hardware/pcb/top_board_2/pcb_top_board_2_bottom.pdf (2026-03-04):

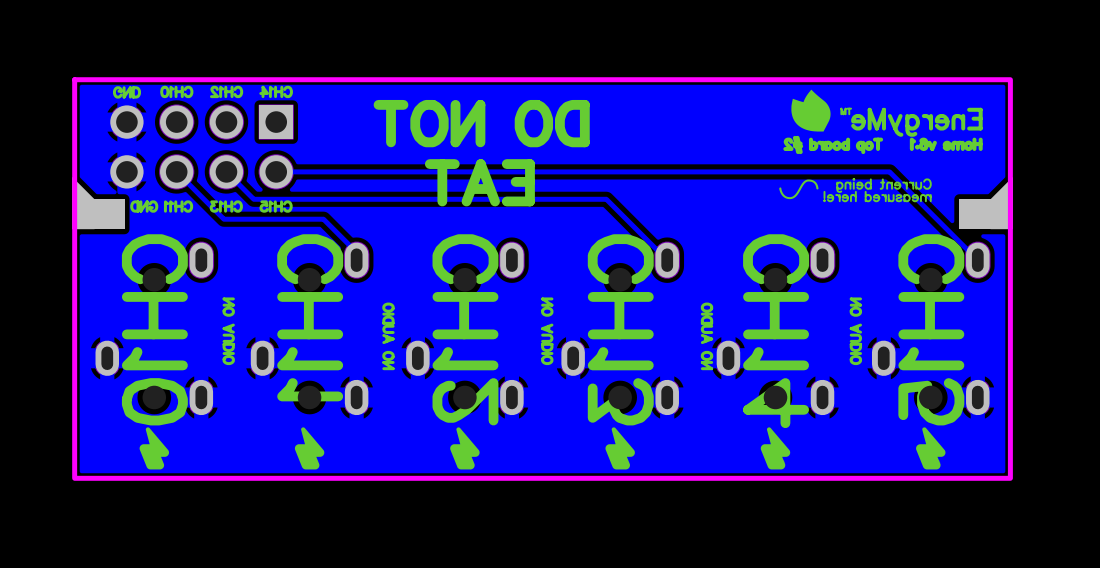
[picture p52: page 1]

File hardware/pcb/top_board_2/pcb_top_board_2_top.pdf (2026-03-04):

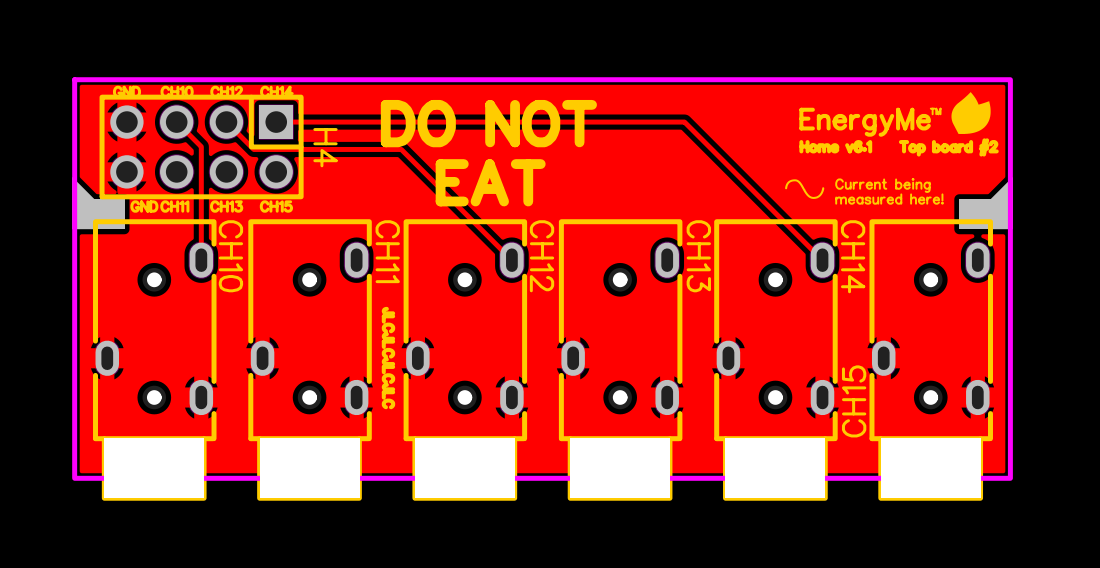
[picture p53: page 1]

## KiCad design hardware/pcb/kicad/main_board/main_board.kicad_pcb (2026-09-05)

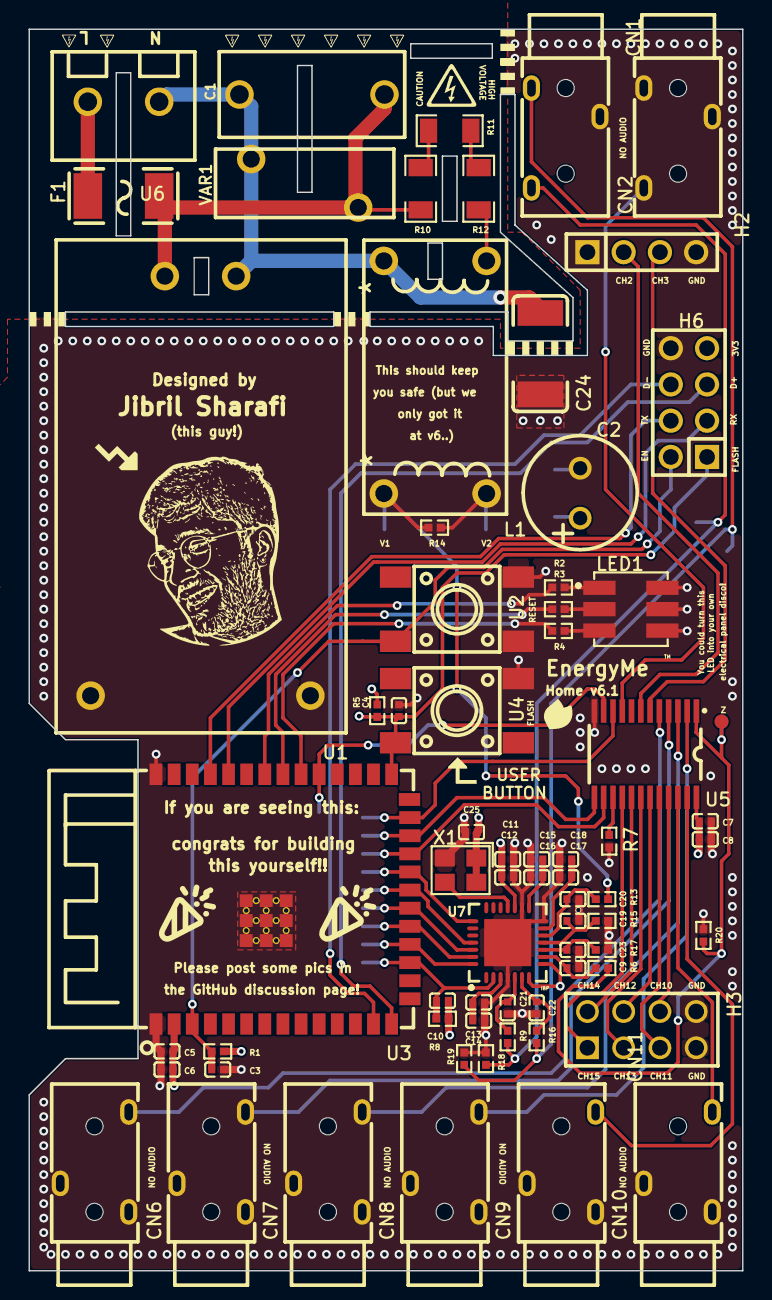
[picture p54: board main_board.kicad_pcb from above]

Board: 4 copper layers, 50.0 x 87.0 mm, 87 parts (0 on the bottom side), 60 nets.

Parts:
C1: 100nF; CAP-TH_L13.0-W6.0-P10.00-D1.0
C2: 3300uF; CAP-TH_BD8.0-P3.50-D0.6-FD
C3, C6, C8, C12, C14, C16, C18: 10uF; C0402
C4, C5, C7, C10, C11, C13, C15, C17, C25: 100nF; C0402
C9, C19, C20, C21, C22, C23: 33nF; C0402
C24: 1nF; C2211
CN1, CN2, CN6, CN7, CN8, CN9, CN10, CN11: PJ-3200; AUDIO-TH_PJ-3200
F1: JFC2410-0500TS; F2410
H2: PM254V-11-04-H85; HDR-TH_4P-P2.54-V-F
H3: PM254V-12-08-H85_C2834799; HDR-TH_8P-P2.54-V-F-R2-C4-S2.54
H6: PZ254V-12-8P; HDR-TH_8P-P2.54-V-M-R2-C4-S2.54
L1: ZMPT107-1; XFMR-TH_ZMPT107-1
LED1: TC5050RGBF08-3CJH-AF53A; LED-SMD_6P-L5.0-W5.0-TL_TC5050RGBF08
Pad_gge151921: Pad_gge151921
Pad_gge152239: Pad_gge152239
Pad_gge152290: Pad_gge152290
Pad_gge152317: Pad_gge152317
Pad_gge152344: Pad_gge152344
Pad_gge152371: Pad_gge152371
Pad_gge152398: Pad_gge152398
Pad_gge152517: Pad_gge152517
Pad_gge153190: Pad_gge153190
Pad_gge153217: Pad_gge153217
Pad_gge153244: Pad_gge153244
Pad_gge153271: Pad_gge153271
Pad_gge157644: Pad_gge157644
Pad_gge157767: Pad_gge157767
Pad_gge157888: Pad_gge157888
Pad_gge165863: Pad_gge165863
Pad_gge165890: Pad_gge165890
Pad_gge166044: Pad_gge166044
Pad_gge166065: Pad_gge166065
R1, R5, R7, R8: 10kΩ; R0402
R2, R3, R4, R6, R9, R13, R15, R16, R17: 1kΩ; R0402
R10, R11, R12: 51kΩ; R1206
R14: 180Ω; R0402
R18, R19, R20: 1MΩ; R0402
U1: HLK-PM03; PWRM-TH_HLK-PM03
U2, U4: ZX-QC66-7.5TP; KEY-SMD_4P-L6.0-W6.0-P4.50-LS8.6
U3: ESP32-S3-WROOM-1(N16R2); WIRELM-SMD_ESP32-S3-WROOM-1
U5: 74HC4067PW,118; TSSOP-24_L7.8-W4.4-P0.65-LS6.4-BL
U6: DB301V-5.0-2P; CONN-TH_2P-P5.00_L7.6-W10.0
U7: ADE7953ACPZ-RL; LFCSP-28_L5.0-W5.0-P0.50-BL-EP
VAR1: 561KD10; RES-TH_L12.5-W4.8-P7.50-D1.2-S3.40
X1: 3.579545MHz; OSC-SMD_4P-L3.2-W2.5-BL_FT3HNBPK16.0-T1

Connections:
3V3: C2.1, C5.2, C6.2, C7.2, C8.2, C10.2, C11.2, C12.2, C25.1, H6.7, Pad_gge166044.1, R1.2, R5.2, R8.2, U1.4, U3.2, U5.24, U7.7, U7.8, U7.17, X1.1, X1.4
CLKIN: U7.18, X1.3
CS: Pad_gge152371.6, Pad_gge152398.7, U3.18, U7.28
CT0_N: CN1.3, Pad_gge165890.1, R16.2, R19.2
CT0_P: CN1.4, Pad_gge165863.1, R9.1, R18.2
CT1: CN2.4, U5.9
CT3: H2.2, U5.7
CT4: H2.3, U5.6
CT5: CN6.4, U5.5
CT6: CN7.4, U5.4
CT7: CN8.4, U5.3
CT8: CN9.4, U5.2
CT9: CN10.4, U5.23
CT10: CN11.4, U5.22
CT11: H3.6, U5.21
CT12: H3.5, U5.20
CT13: H3.4, U5.19
CT14: H3.3, U5.18
CT15: H3.2, U5.17
CT16: H3.1, U5.16
EN: C3.2, H6.2, R1.1, U2.3, U3.3
FLASH: C4.2, H6.1, R5.1, U3.27, U4.3
GND: C2.2, C3.1, C4.1, C5.1, C6.1, C7.1, C8.1, C9.1, C11.1, C12.1, C13.1, C14.1, C15.1, C16.1, C17.1, C18.1, C19.1, C20.1, C21.1, C22.1, C23.1, C24.2, C25.2, CN1.2, CN2.2, CN2.3, CN6.2, CN6.3, CN7.2, CN7.3, CN8.2, CN8.3, CN9.2, CN9.3, CN10.2, CN10.3, CN11.2, CN11.3, H2.4, H3.7, H3.8, H6.8, L1.2, LED1.4, LED1.5, LED1.6, Pad_gge157767.1, Pad_gge166065.1, R7.2, R14.1, R15.2, R17.1, R18.1, R19.1, R20.1, U1.3, U2.2, U3.1, U3.40, U3.41, U4.2, U5.12, U7.4, U7.14, U7.16, U7.29, X1.2
IAN: C22.2, R16.1, U7.6
IAP: C21.2, R9.2, U7.5
IBN: C23.2, R17.2, U7.10
IBP: C9.2, R6.1, U7.9
L: F1.1, U6.2
L1_4: L1.4, R12.2
LED1_1: LED1.1, R2.2
LED1_2: LED1.2, R3.2
LED1_3: LED1.3, R4.2
LED_B: R4.1, U3.32
LED_G: R2.1, U3.34
LED_R: R3.1, U3.33
L_FUSE: C1.1, F1.2, R10.1, U1.2, VAR1.2
MISO: Pad_gge152317.4, U3.20, U7.26
MOSI: Pad_gge152344.5, U3.19, U7.27
N: C1.2, C24.1, L1.3, U1.1, U6.1, VAR1.1
QRI#: Pad_gge152239.2, U3.22, U7.22
R10_2: R10.2, R11.1
R11_2: R11.2, R12.1
R13_1: L1.1, Pad_gge157644.1, R13.1, R14.2
REF_IN_OUT: C17.2, C18.2, U7.13
RST_ADE: C10.1, Pad_gge152517.9, R8.1, U3.17, U7.2
RX: H6.3, U3.36
S0: Pad_gge153244.12, U3.25, U5.10
S1: Pad_gge153271.13, U3.31, U5.11
S2: Pad_gge153190.10, U3.23, U5.14
S3: Pad_gge153217.11, U3.24, U5.13
SCLK: Pad_gge152290.3, U3.21, U7.25
TX: H6.4, U3.37
U5_1: Pad_gge151921.1, Pad_gge157888.1, R6.2, R20.2, U5.1
U5_15: R7.1, U5.15
USB_DN: H6.6, U3.13
USB_DP: H6.5, U3.14
VINTA: C15.2, C16.2, U7.15
VINTD: C13.2, C14.2, U7.3
VN: C20.2, R15.1, U7.11
VP: C19.2, R13.2, U7.12

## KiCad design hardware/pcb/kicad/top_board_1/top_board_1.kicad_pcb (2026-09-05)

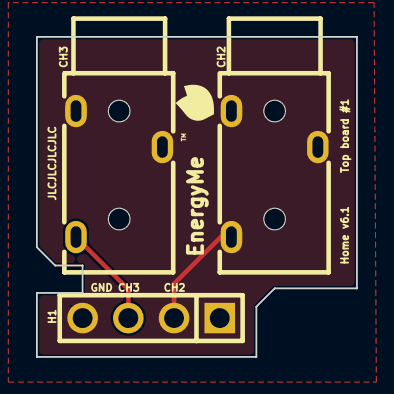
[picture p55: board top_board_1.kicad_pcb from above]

Board: 2 copper layers, 17.8 x 17.8 mm, 3 parts (0 on the bottom side), 3 nets.

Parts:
CH2, CH3: PJ-3200; AUDIO-TH_PJ-3200
H1: PZ254V-11-04P_C2691448; HDR-TH_4P-P2.54-V-M

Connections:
CT3_T: CH2.4, H1.2
CT4_T: CH3.4, H1.3
GND: CH2.2, CH2.3, CH3.2, CH3.3, H1.4

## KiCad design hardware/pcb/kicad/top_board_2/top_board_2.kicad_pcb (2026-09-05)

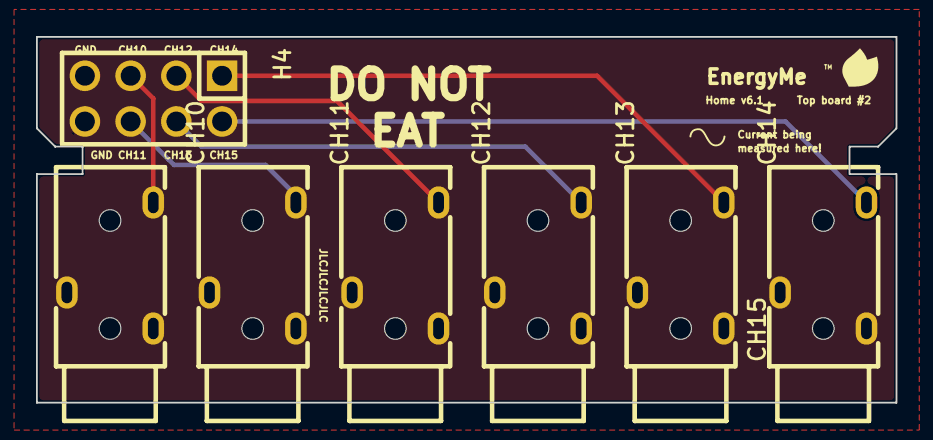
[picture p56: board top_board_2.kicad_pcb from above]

Board: 2 copper layers, 47.8 x 20.3 mm, 7 parts (0 on the bottom side), 7 nets.

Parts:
CH10, CH11, CH12, CH13, CH14, CH15: PJ-3200; AUDIO-TH_PJ-3200
H4: PZ254V-12-8P; HDR-TH_8P-P2.54-V-M-R2-C4-S2.54

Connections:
CT11_T: CH10.4, H4.5
CT12_T: CH11.4, H4.6
CT13_T: CH12.4, H4.3
CT14_T: CH13.4, H4.4
CT15_T: CH14.4, H4.1
CT16_T: CH15.4, H4.2
GND: CH10.2, CH10.3, CH11.2, CH11.3, CH12.2, CH12.3, CH13.2, CH13.3, CH14.2, CH14.3, CH15.2, CH15.3, H4.7, H4.8

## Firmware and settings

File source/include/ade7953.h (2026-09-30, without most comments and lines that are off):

#pragma once
#include <AdvancedLogger.h>
#include <Arduino.h>
#include <ArduinoJson.h>
#include "freertos/FreeRTOS.h"
#include "freertos/semphr.h"
#include <set>
#include <SPI.h>
#include <Preferences.h>
#include <rom/crc.h>
#include <Update.h>
#include <vector>
#include "ade7953registers.h"
#include "multiplexer.h"
#include "customtime.h"
#include "mqtt.h"
#include "binaries.h"
#include "constants.h"
#include "factory_keys.h"
#include "structs.h"
#include "utils.h"
#include "hardware_profile.h"
#include "channel_types.h"   // ChannelRole (shared, Arduino-free - see lib/meter_logic)
#include "meter_logic.h"     // pure CT-polarity / clamp / WDRR decisions (host-testable)
#define ADE7953_SPI_FREQUENCY 2000000 // The maximum SPI frequency for the ADE7953 is 2MHz
#define ADE7953_SPI_MUTEX_TIMEOUT_MS 100
#define ADE7953_SPI_OPERATION_MUTEX_TIMEOUT_MS 200 // Longer than normal SPI since this accounts also for validation
#define ADE7953_METER_READING_TASK_NAME "ade7953_task"
#define ADE7953_METER_READING_TASK_STACK_SIZE (8 * 1024) // Week-long peak ~5358 bytes (43.6%); 8 KB leaves ~33% margin and frees 4 KB of internal heap
#define ADE7953_METER_READING_TASK_PRIORITY 5
#define ADE7953_ENERGY_SAVE_TASK_NAME "energy_save_task"
#define ADE7953_ENERGY_SAVE_TASK_STACK_SIZE (5 * 1024) // Around 4.5 kB usage
#define ADE7953_ENERGY_SAVE_TASK_PRIORITY 1
#define ADE7953_HOURLY_CSV_SAVE_TASK_NAME "hourly_csv_task"
#define ADE7953_HOURLY_CSV_SAVE_TASK_STACK_SIZE (6 * 1024) // No more than 5 kB. A bit larger for safety
#define ADE7953_HOURLY_CSV_SAVE_TASK_PRIORITY 1
#define ADE7953_HISTORY_CLEAR_TASK_NAME "hist_clear"
#define ADE7953_HISTORY_CLEAR_TASK_STACK_SIZE (6 * 1024) // Same as hourly CSV task (does similar gz work)
#define ADE7953_HISTORY_CLEAR_TASK_PRIORITY 1
#define CLEAR_ALL_CHANNELS_SENTINEL 0xFE
#define ADE7953_GRID_SAMPLER_TASK_NAME "grid_sampler"
#define ADE7953_GRID_SAMPLER_TASK_STACK_SIZE (6 * 1024) // Was 3 KB; too small caused a stack overflow that corrupted adjacent heap, surfacing as an unrelated heap-poisoning panic elsewhere
#define ADE7953_GRID_SAMPLER_TASK_PRIORITY 2
#define GRID_SAMPLE_INTERVAL_MS 500 // Samples aligned to absolute .000/.500 wall-clock boundaries
#define GRID_SAMPLE_MIN_DELAY_MS 20 // Skip to the next boundary when too close
#define SAVE_ENERGY_INTERVAL (15 * 60 * 1000) // Time between each energy save to preferences. Do not increase the frequency to avoid wearing the flash memory. In any case, this is part of the requirement. The other part is ENERGY_SAVE_THRESHOLD
#define ENERGY_CSV_PREFIX "/energy"
#define ENERGY_CSV_DAILY_PREFIX ENERGY_CSV_PREFIX "/daily"
#define ENERGY_CSV_MONTHLY_PREFIX ENERGY_CSV_PREFIX "/monthly"
#define ENERGY_CSV_YEARLY_PREFIX ENERGY_CSV_PREFIX "/yearly"
#define TEMPORARY_FILE_PREFIX "_temp_"
#define DAILY_ENERGY_CSV_HEADER "timestamp,channel,active_imported,active_exported"
#define DAILY_ENERGY_CSV_DIGITS 0 // Since the energy is in Wh, it is useless to go below 1 Wh, and we also save in space usage
#define ENERGY_SAVE_THRESHOLD 100.0f // Threshold for saving energy data (in Wh) and in any case not more frequent than SAVE_ENERGY_INTERVAL
#define ENERGY_CONSOLIDATION_MIN_SIZE 10 // Minimum file size (bytes) to consider consolidation successful
#define ADE7953_INTERRUPT_TIMEOUT_MS 1000ULL // If exceed this plus sample time, something is wrong as we are not receiving the interrupt
#define ADE7953_RESET_LOW_DURATION 200 // The duration for the reset pin to be low (minimum is way lower, but this is a safe value)
#define ADE7953_MAX_VERIFY_COMMUNICATION_ATTEMPTS 5
#define ADE7953_VERIFY_COMMUNICATION_INTERVAL 500
#define WEIGHT_POWER_SHARE 0.4f      // Weight contribution from power magnitude share
#define WEIGHT_VARIABILITY 0.4f      // Weight contribution from power variability share
#define WEIGHT_MIN_BASE 0.1f         // Minimum base weight to prevent starvation
#define VARIABILITY_EMA_ALPHA 0.3f   // Exponential moving average smoothing for variability (0-1, lower = smoother)
#define CHANNEL_MAX_GAP_MS 15000ULL  // Watchdog: max time between successful reads before forcing a pick
#define MAX_CHANNEL_DEFICIT_BOUND 5.0f // Symmetric clamp on per-channel deficit (safety net against arithmetic edge cases)
#define WEIGHT_ARMED_BOOST 1.5f      // Extra weight for a channel running CT-reversal detection WHILE CONDUCTING, so it is sampled rapidly and resolves in ~1-2 s
#define WEIGHT_ROLE_PRIORITY_MULT 2.0f // Weight multiplier for grid / battery roles - mains and storage flow are sampled more often (matters most on 3-phase)
#define UNLOCK_OPTIMUM_REGISTER_VALUE 0xAD // Register to write to unlock the optimum register
#define UNLOCK_OPTIMUM_REGISTER 0x00FE // Value to write to unlock the optimum register
#define DEFAULT_OPTIMUM_REGISTER 0x0030 // Default value for the optimum register
#define DEFAULT_EXPECTED_AP_NOLOAD_REGISTER 0x00E419 // Default expected value for AP_NOLOAD_32 (used to validate the ADE7953 communication)
#define DEFAULT_NOLOAD_DYNAMIC_RANGE 20000 // Indicates the 1/X dynamic range before the no load feature kicks in. The higher the more sensible, but more prone to noise. Then there will be a formula to compute the register value.
#define DEFAULT_DISNOLOAD_REGISTER 0 // 0x00 0b00000000 (enable all no-load detection)
#define DEFAULT_LCYCMODE_REGISTER 0b00111111 // 0x3F line cycle accumulation on all channels; read-with-reset OFF (see guardrail above)
#define DEFAULT_PGA_REGISTER 0 // PGA gain 1
#define DEFAULT_CONFIG_REGISTER 0b1010000100001100 // Bits 2, 3 (line accumulation for PF), 8 (CRC), 13:12=10b (ZX_EDGE: positive-going zero crossings only; does not affect linecyc), 15 (HPF enabled, COMM_LOCK disabled)
#define DEFAULT_IRQENA_REGISTER 0b00001101001100000000000000 // ZXTO (bit 14, grid-loss detection), ZXV (bit 15, grid frequency), CYCEND (bit 18), Reset (bit 20, mandatory), CRC change (bit 21)
#define MINIMUM_SAMPLE_TIME 200ULL // The settling time of the ADE7953 is 200 ms, so reading faster than this makes little sense
#define ADE7953_ZXTOUT_RESOLUTION_US 71 // 1 / 14kHz (CLKIN/256) per LSB, datasheet rounds to 0.07ms
#define ADE7953_ZXTOUT_TARGET_MS 15
#define ADE7953_ZXTOUT_VALUE ((ADE7953_ZXTOUT_TARGET_MS * 1000UL) / ADE7953_ZXTOUT_RESOLUTION_US) // ~211
#define ADE7953_ZXTO_SUPPRESS_MS (60 * 1000)
#define VALIDATE_CT_CURRENT_RATING_MIN 0.0f
#define VALIDATE_CT_CURRENT_RATING_MAX 10000.0f // In amperes. If EnergyMe - Home ends up being used for 10000+ A, we have bigger problems than the CT specification validation :)
#define VALIDATE_CT_VOLTAGE_OUTPUT_MIN 0.0f
#define VALIDATE_CT_VOLTAGE_OUTPUT_MAX 1.0f // In volts. Already exceeding the 0.5 V absolute limit is enough. More than 1V should be avoided at all costs (in any case, most CTs are up to 1V max)
#define VALIDATE_CT_SCALING_FRACTION_MIN -10.0f // If you need to multiply more than 10x times the values you read, the issue is somewhere else
#define VALIDATE_CT_SCALING_FRACTION_MAX 10.0f
#define FULL_SCALE_LSB_FOR_RMS_VALUES 9032007 // Maximum value of RMS registers (24-bit unsigned) - current (channel A and B) and voltage
#define FULL_SCALE_LSB_FOR_INSTANTANEOUS_VALUES 6500000 // Maximum value of waveform registers (23-bit signed, ±6500000 at ±0.5V input)
#define MAXIMUM_ADC_CHANNEL_INPUT 0.5f // Maximum voltage in volts (absolute) for all ADC channels in ADE7953 (both current and voltage)
#define ENERGY_ACCUMULATION_FREQUENCY 206900 // At full input scale, an LSB is added every this frequency to the energy register
#define POWER_FACTOR_CONVERSION_FACTOR 0.00003052f // PF/LSB computed as 1.0f / 32768.0f (from ADE7953 datasheet). Unused (since the PF is derived as P/S but left for reference)
#define ANGLE_CONVERSION_FACTOR 0.0807f // 0.0807 °/LSB computed as 360.0f * 50.0f / 223000.0f. Unused (we don't need the angle for anyhting) but left for reference
#define GRID_FREQUENCY_CONVERSION_FACTOR 223750.0f // Clock of the period measurement, in Hz. f = factor / (PERIOD_16 + 1) per datasheet Eq.36
#define DEFAULT_FALLBACK_FREQUENCY 50 // Most of the world is 50 Hz
#define WAVEFORM_CYCLES_TO_CAPTURE 4    // Number of line cycles to capture
#define SAMPLING_RATE_INSTANTANEOUS_VALUES 6990 // 6.99 kHz (as given by datasheet) is the maximum rate of update of the instantaneous values
#define WAVEFORM_BUFFER_SIZE \
    ((size_t)(((float)WAVEFORM_CYCLES_TO_CAPTURE / (float)DEFAULT_FALLBACK_FREQUENCY) \
              * SAMPLING_RATE_INSTANTANEOUS_VALUES * 1.2f)) // 20% margin for sampling jitter
#define WAVEFORM_CAPTURE_MAX_DURATION_MICROS (2 * 1000000 * WAVEFORM_CYCLES_TO_CAPTURE) / DEFAULT_FALLBACK_FREQUENCY // 2x margin
#define CONFIG_SAMPLE_TIME_KEY "sample_time"
#define CONFIG_AV_GAIN_KEY "av_gain"
#define CONFIG_AI_GAIN_KEY "ai_gain"
#define CONFIG_BI_GAIN_KEY "bi_gain"
#define CONFIG_AIRMS_OS_KEY "airms_os"
#define CONFIG_BIRMS_OS_KEY "birms_os"
#define CONFIG_AW_GAIN_KEY "aw_gain"
#define CONFIG_BW_GAIN_KEY "bw_gain"
#define CONFIG_AWATT_OS_KEY "awatt_os"
#define CONFIG_BWATT_OS_KEY "bwatt_os"
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

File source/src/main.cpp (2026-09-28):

// SPDX-License-Identifier: GPL-3.0-or-later
// Copyright (C) 2025 Jibril Sharafi

#include <Arduino.h>
#include <AdvancedLogger.h>
#include <LittleFS.h>
#include <driver/gpio.h>
#if ARDUINO_USB_CDC_ON_BOOT && ARDUINO_USB_MODE
#include <hal/usb_serial_jtag_ll.h>
#endif

// Project includes
// Initialization before everything
#include "constants.h"
#include "structs.h"
#include "utils.h"
#include "hardware_profile.h"

#include "ade7953.h"
#include "buttonhandler.h"
#include "crashmonitor.h"
#include "customwifi.h"
#include "custometh.h"
#include "customnet.h"
#include "customserver.h"
#include "led.h"
#include "modbustcp.h"
#include "mqtt.h"
#include "custommqtt.h"
#include "influxdbclient.h"
#include "issueregistry.h"
#include "multiplexer.h"
#include "customlog.h"
#include "taskprofiler.h"

// Global variables
// --------------------

Statistics statistics; // Move both to utils and use getter to get and set them
char DEVICE_ID[DEVICE_ID_BUFFER_SIZE];

// gpio_install_isr_service() runs esp_intr_alloc() + a poisoned malloc on the 1024-byte ipcN
// stack (prebuilt sdkconfig, not tunable); an interrupt frame pushed at that depth trips the
// stack canary ("Stack canary watchpoint triggered (ipc1)", seen on the Pro bench while a host
// drained the USB backlog). Install once while the core is quiet, with the USB-Serial-JTAG IRQ
// masked at the peripheral. CPU interrupts must stay enabled: the IPC call blocks. This only
// lowers the probability (tick/IPI remain). Later attachInterrupt()/ETH.begin() see "already
// installed" and skip the IPC.
static esp_err_t installGpioIsrServiceEarly()
{
#if ARDUINO_USB_CDC_ON_BOOT && ARDUINO_USB_MODE
  const uint32_t usbIntrEna = usb_serial_jtag_ll_get_intr_ena_status();
  usb_serial_jtag_ll_disable_intr_mask(usbIntrEna);
#endif
  const esp_err_t err = gpio_install_isr_service((int)ARDUINO_ISR_FLAG);
#if ARDUINO_USB_CDC_ON_BOOT && ARDUINO_USB_MODE
  usb_serial_jtag_ll_ena_intr_mask(usbIntrEna);
#endif
  return err;
}

#if ARDUINO_USB_CDC_ON_BOOT && ARDUINO_USB_MODE
// Weak core hook: the first thing loopTask runs, BEFORE the core's pre-setup chip report
// (dev builds, CORE_DEBUG_LEVEL >= 4). Setting the TX timeout in setup() is too late for
// that report, hence here. Bench numbers: see SERIAL_TX_TIMEOUT_MS in constants.h.
uint64_t getArduinoSetupWaitTime_ms()
{
  Serial.setTxTimeoutMs(SERIAL_TX_TIMEOUT_MS);
  return 0;
}
#endif

static uint32_t taskStackMinFree(const char *taskName)
{
  TaskHandle_t handle = xTaskGetHandle(taskName);
  if (handle == NULL) return 0;
  return (uint32_t)uxTaskGetStackHighWaterMark(handle);
}

#ifdef ENV_DEV
// Dev-only boot heap ledger: internal free heap after each setup stage, so internal RAM
// can be attributed per module from the boot log (UDP logs carry the boot lines too).
static void logHeapLedger(const char *stage)
{
  LOG_DEBUG("Heap ledger | %s | internal free %lu | largest block %lu", stage,
            (unsigned long)heap_caps_get_free_size(MALLOC_CAP_INTERNAL),
            (unsigned long)heap_caps_get_largest_free_block(MALLOC_CAP_INTERNAL));
}
#else
static inline void logHeapLedger(const char *) {}
#endif

void setup()
{
  const esp_err_t gpioIsrErr = installGpioIsrServiceEarly();

  Serial.begin(SERIAL_BAUDRATE);
  Serial.printf(FULL_PRODUCT_NAME "\n____________________\n\n");
  Serial.println("Booting...");
  Serial.printf("Build version: %s\n", FIRMWARE_BUILD_VERSION);
  Serial.printf("Build date: %s %s\n", FIRMWARE_BUILD_DATE, FIRMWARE_BUILD_TIME);

  // Initialize global device ID
  getDeviceId(DEVICE_ID, sizeof(DEVICE_ID));
  Serial.printf("Device ID: %s\n", DEVICE_ID);

  // Must be first: reads eFuse, selects hardware profile (pins, voltage ratios, mux map),
  // sets globalHwProfile and globalCommunityMode before any hardware is initialized.
  initHardwareProfile();

  // Register per-core idle hooks before any task is created so the baseline is
  // measured against a still-quiet system. Failure here is non-fatal (CPU% will
  // report 0; heartbeats and stack info still work).
  TaskProfiler::begin();

  // Need to call this once and at begin to ensure PSRAM is used for all mbedtls (both for OTA and MQTT connection. and maybe InfluxDB)
  mbedtls_platform_set_calloc_free(ota_calloc_psram, ota_free_psram);

  Serial.println("Setting up LED...");
  Led::begin(globalHwProfile->ledRedPin, globalHwProfile->ledGreenPin, globalHwProfile->ledBluePin);
  Serial.println("LED setup done");

  Led::setWhite(Led::PRIO_NORMAL);

  if (!isFirstBootDone())
  {
    setFirstBootDone();
    createAllNamespaces();
    LOG_INFO("First boot setup complete. Welcome aboard!");
  }

  if (!LittleFS.begin(true)) // Ensure the partition name is "spiffs" in partitions.csv (even when using LittleFS). Setting the partition label to "littlefs" caused issues
  {
    Serial.println("LittleFS initialization failed!");
    ESP.restart(); // No reason to live if we cannot mount the filesystem
    return;
  }

  // Check for pending configuration restore (BEFORE services start = natural "blocked state")
  if (isNvsRestorePending()) {
    LOG_DEBUG("Pending configuration restore detected. Starting restore process...");
    performNvsRestore();
    LOG_INFO("Configuration restore process completed");
  }

  Led::setYellow(Led::PRIO_NORMAL);
  AdvancedLogger::begin(LOG_PATH);
  LOG_DEBUG("AdvancedLogger initialized with log path: %s", LOG_PATH);
  
  LOG_DEBUG("Setting up callbacks for AdvancedLogger...");
  AdvancedLogger::setCallback(CustomLog::callbackMultiple);
  // VERBOSE never goes to the callbacks (UDP, MQTT): at hundreds of lines per second it would only
  // fill the log queue. It can be read on the serial console at best, through the print level.
  AdvancedLogger::setCallbackLevel(LogLevel::DEBUG);
  LOG_DEBUG("Callbacks for AdvancedLogger set up successfully");
  logHeapLedger("led + littlefs + logger");

  LOG_INFO("Guess who's back, back again! " FULL_PRODUCT_NAME " is starting up...");
  LOG_INFO(
    "Build version: %s %s(MD5: %s) | Build date: %s %s | Device ID: %s", 
    FIRMWARE_BUILD_VERSION,
    #ifdef ENV_DEV 
    "(dev) ",
    #else
    "",
    #endif
    ESP.getSketchMD5().c_str(), 
    FIRMWARE_BUILD_DATE, 
    FIRMWARE_BUILD_TIME, 
    DEVICE_ID
  ); // When changing this, be careful as it is used as parsing method to validate firmware version and environment; always align with manufacturing repo
  
  Led::setOrange(Led::PRIO_NORMAL);
  LOG_DEBUG("Setting up crash monitor...");
  CrashMonitor::begin();
  LOG_DEBUG("Crash monitor setup done");
  logHeapLedger("crash monitor");
  LOG_DEBUG("GPIO ISR service: %s | ipc0/ipc1 stack min free: %lu/%lu bytes",
            esp_err_to_name(gpioIsrErr),
            (unsigned long)taskStackMinFree("ipc0"),
            (unsigned long)taskStackMinFree("ipc1"));

  printDeviceStatusStatic();

  Led::setPurple(Led::PRIO_NORMAL);
  LOG_DEBUG("Setting up multiplexer...");
  Multiplexer::begin(
      globalHwProfile->muxS0Pin,
      globalHwProfile->muxS1Pin,
      globalHwProfile->muxS2Pin,
      globalHwProfile->muxS3Pin);
  LOG_DEBUG("Multiplexer setup done");
  logHeapLedger("multiplexer");

  LOG_DEBUG("Setting up button handler...");
  ButtonHandler::begin(globalHwProfile->buttonPin);
  LOG_DEBUG("Button handler setup done");
  logHeapLedger("button");

  LOG_DEBUG("Setting up ADE7953...");
  if (
    Ade7953::begin(
      globalHwProfile->ade7953SsPin,
      globalHwProfile->ade7953SckPin,
      globalHwProfile->ade7953MisoPin,
      globalHwProfile->ade7953MosiPin,
      globalHwProfile->ade7953ResetPin,
      globalHwProfile->ade7953InterruptPin
    )
  ) LOG_DEBUG("ADE7953 setup done");
  else LOG_ERROR("ADE7953 initialization failed! This is a big issue mate..");
  logHeapLedger("ade7953");

  Led::setBlue(Led::PRIO_NORMAL);
  CustomEth::registerEvents(); // Ahead of the first WiFi event, see custometh.h. No-op without Ethernet
  LOG_DEBUG("Setting up WiFi...");
  CustomWifi::begin();
  LOG_DEBUG("WiFi setup done");
  logHeapLedger("wifi");

  // Callbacks registered BEFORE begin() so the callback array is complete before the
  // eth task exists - no writer/iterator race. On failover the established TLS/TCP
  // sessions are bound to the dead interface's address: drop them so they
  // reconnect on the new route, and resync NTP against a server reachable
  // through it. Harmless on Home (the callbacks never fire without Ethernet).
  CustomEth::onInterfaceChange([](InterfaceArbitration::Interface) { Mqtt::requestReconnect(); });
  CustomEth::onInterfaceChange([](InterfaceArbitration::Interface) { CustomMqtt::requestReconnect(); });
  CustomEth::onInterfaceChange([](InterfaceArbitration::Interface) { CustomTime::requestResync(); });

  // No-op on products without Ethernet. On Pro this brings up the W5500 and the
  // interface arbitration; a cabled device typically has a lease before the WiFi
  // association finishes, so the wait below clears on the wire.
  LOG_DEBUG("Setting up Ethernet...");
  if (CustomEth::begin()) LOG_DEBUG("Ethernet setup done");
  else LOG_ERROR("Ethernet initialization failed! Continuing on WiFi only");
  logHeapLedger("ethernet");

  // Wait until the device is reachable by SOMETHING: STA connected, or the SoftAP raised
  // and serving. Waiting on isFullyConnected() here would spin forever on a device with no
  // valid credentials, so CustomServer::begin() below would never run and provisioning
  // would be unreachable - the AP would be up with nothing listening on it (D7).
  // Safe only because the health check now gates on isNetworkServiceable() too; on
  // isFullyConnected() it would fail every 30 s with the AP up and restart the device.
  //
  // Bounded, because "neither interface" is a reachable state, not a transient one: if every
  // candidate subnet collides, _raiseAp() fails closed and there is no AP to wait for. An
  // unbounded wait there is the worst possible outcome - no STA, no AP, and no web server on
  // any interface, so nothing to diagnose or fix it with. Give up and carry on instead: every
  // downstream service gates on isFullyConnected() by itself, and starting the server anyway
  // means it is already listening the moment any interface appears.
  uint64_t networkWaitStartMs = millis64();
  while (!CustomNet::isNetworkServiceable() &&
         (millis64() - networkWaitStartMs) < SETUP_NETWORK_WAIT_TIMEOUT_MS)
  {
    LOG_DEBUG("Waiting for a network interface or SoftAP...");
    delay(1000);
  }

  if (!CustomNet::isNetworkServiceable())
  {
    LOG_ERROR("No station-side link and no SoftAP after %llu s - continuing boot anyway. The device is "
              "unreachable until one of them comes up; the network tasks keep retrying",
              (uint64_t)(SETUP_NETWORK_WAIT_TIMEOUT_MS / 1000ULL));
  }

  // Add custom logging setup after WiFi
  LOG_DEBUG("Setting up custom logging...");
  CustomLog::begin();
  LOG_DEBUG("Custom logging setup done");
  logHeapLedger("network wait + custom logging");

  LOG_DEBUG("Syncing time...");
  if (CustomTime::begin()) LOG_INFO("Initial time sync successful");
  else LOG_ERROR("Initial time sync failed! Will retry later.");
  logHeapLedger("time");

  // Before the web server: the /api/v1/system/issues endpoint reads the registry
  // mutex, so the registry must exist before requests can arrive (else early polls
  // hit a NULL mutex -> HTTP 500). Deps are ready here: hw profile (initHardwareProfile)
  // and ADE7953 (channel facts) init earlier; time is up for issue timestamps. The
  // task's cloud/influx checks read safe default flags until those modules begin().
  LOG_DEBUG("Setting up issue registry...");
  IssueRegistry::begin();
  LOG_DEBUG("Issue registry setup done");
  logHeapLedger("issue registry");

  LOG_DEBUG("Setting up server...");
  CustomServer::begin();
  LOG_DEBUG("Server setup done");
  logHeapLedger("web server");

  // Only once there is a station link. Modbus TCP is unauthenticated and binds every
  // interface, so starting it on an AP-only boot would serve meter data to anyone in radio
  // range of the provisioning SoftAP. The health-check task starts it when STA comes up.
  LOG_DEBUG("Setting up Modbus TCP...");
  ModbusTcp::syncWithNetwork(CustomNet::isFullyConnected(), CustomWifi::isApServing());
  LOG_DEBUG("Modbus TCP setup done");
  logHeapLedger("modbus tcp");

  if (!globalCommunityMode) {
    LOG_DEBUG("Setting up MQTT client...");
    Mqtt::begin();
    LOG_DEBUG("MQTT client setup done");
  }

  LOG_DEBUG("Setting up Custom MQTT client...");
  CustomMqtt::begin();
  LOG_DEBUG("Custom MQTT client setup done");
  logHeapLedger("cloud mqtt + custom mqtt");

  LOG_DEBUG("Setting up InfluxDB client...");
  InfluxDbClient::begin();
  LOG_DEBUG("InfluxDB client setup done");
  logHeapLedger("influxdb");

  LOG_DEBUG("Starting maintenance task...");
  startMaintenanceTask();
  LOG_DEBUG("Maintenance task started");
  logHeapLedger("maintenance");

  // Visual indicator for safe mode (restart protection active)
  if (CrashMonitor::isInSafeMode()) {
    Led::setPurple(Led::PRIO_CRITICAL); // Purple = safe mode (restart protection)
  } else {
    Led::setGreen(Led::PRIO_NORMAL);
  }
  
  printStatistics();
  printDeviceStatusDynamic();
  LOG_INFO("Setup done! Let's get this energetic party started!");

  // Since in the loop there is nothing we care about, let's just kill the main task to gain some heap
  delay(1000);
  vTaskDelete(NULL);
}

void loop()
{
  // Oh yes, it took a incredible amount of time but finally we have a loop in which "nothing" happens
  // This is because all of the tasks are running in their own FreeRTOS tasks
  // Much better than the old way of having everything in the main loop blocking
  // This will never run, but we leave the delay for safety
  vTaskDelay(portMAX_DELAY);
}

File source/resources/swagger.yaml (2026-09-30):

# SPDX-License-Identifier: GPL-3.0-or-later
# Copyright (C) 2025 Jibril Sharafi

openapi: 3.0.0
info:
  title: EnergyMe - Home | API
  description: >
    API documentation for EnergyMe - Home.


    **Default password lockdown.** A device still holding the password it shipped with
    answers `403` with `"reason": "default_password"` on every endpoint here except
    `/api/v1/health`, `GET /api/v1/auth/status` and `POST /api/v1/auth/change-password`.
    The shipped password is a published constant, so a device holding it is effectively
    unauthenticated; set a new one at `/` and the rest of this API becomes available
    immediately, without a restart.
  version: 1.1.0

servers:
  - url: /
    description: Current server (auto-detected from browser)

paths:
  # Health check endpoint
  /api/v1/health:
    get:
      summary: Health check
      description: Check if the API is running and responsive
      tags:
        - System
      responses:
        '200':
          description: Service is healthy
          content:
            application/json:
              schema:
                type: object
                properties:
                  status:
                    type: string
                    example: "ok"
                  uptime:
                    type: integer
                    format: seconds
                  timestamp:
                    type: string
                    format: date-time

  # Authentication endpoints  
  /api/v1/auth/status:
    get:
      summary: Get authentication status
      description: >
        Reports whether the device is still using the password it shipped with. While
        `usingDefaultPassword` is true the device refuses every other endpoint - see the
        `403` response shared by the rest of this document. This endpoint and
        `POST /api/v1/auth/change-password` stay reachable so there is always a way out.
      tags:
        - Authentication
      responses:
        '200':
          description: Authentication status
          content:
            application/json:
              schema:
                type: object
                properties:
                  usingDefaultPassword:
                    type: boolean
                    description: True while the stored password equals the shipped default
                  apOrigin:
                    type: boolean
                    description: True when this request arrived on the device's own SoftAP
                  username:
                    type: string
                  productName:
                    type: string
                    description: Product name for the page texts, e.g. "Home" or "Home Pro"

  /api/v1/auth/change-password:
    post:
      summary: Change password
      description: Change the authentication password (requires current password for security)
      tags:
        - Authentication
      requestBody:
        required: true
        content:
          application/json:
            schema:
              type: object
              required:
                - currentPassword
                - newPassword
              properties:
                currentPassword:
                  type: string
                  description: Current password for verification
                newPassword:
                  type: string
                  description: >
                    New password. Must be 8 to 64 characters and must not be the shipped
                    default - "changing" the password to the default would leave the device
                    exactly where it started.
                  minLength: 8
                  maxLength: 64
            example:
              currentPassword: "oldpassword123"
              newPassword: "newpassword456"
      responses:
        '200':
          $ref: '#/components/responses/Success'
        '400':
          $ref: '#/components/responses/BadRequest'
        '401':
          $ref: '#/components/responses/Unauthorized'
        '500':
          $ref: '#/components/responses/InternalServerError'

  /api/v1/auth/reset-password:
    post:
      summary: Reset password to default
      description: >
        Reset the authentication password to the shipped default. This puts the device
        straight into the locked-down state, so it is refused when the default password
        is already active. Recovering a forgotten password is done with the physical
        button, which is unaffected by the lockdown.
      tags:
        - Authentication
      responses:
        '200':
          $ref: '#/components/responses/Success'
        '403':
          $ref: '#/components/responses/DefaultPasswordLockdown'
        '500':
          $ref: '#/components/responses/InternalServerError'
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

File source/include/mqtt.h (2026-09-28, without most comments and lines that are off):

#pragma once
#include <AdvancedLogger.h>
#include <Arduino.h>
#include <ArduinoJson.h>
#include <HTTPClient.h>
#include <Preferences.h>
#include <PubSubClient.h>
#include <StreamUtils.h>
#include <WiFiClientSecure.h>
#include "esp_https_ota.h"
#include "esp_http_client.h"
#include "ade7953.h"
#include "awsconfig.h"
#include "constants.h"
#include "factory_keys.h"
#include "customtime.h"
#include "customwifi.h"
#include "customnet.h"
#include "customlog.h"
#include "globals.h"
#include "structs.h"
#include "utils.h"
#define MQTT_TASK_NAME "mqtt_task"
#define MQTT_TASK_STACK_SIZE (7 * 1024) // Around 6 kB usage
#define MQTT_TASK_PRIORITY 1 // Below AsyncTCP/web (priority 3) so user-facing requests preempt cloud publishing
#define MQTT_LOG_QUEUE_SIZE (256 * 1024) // Generous log size (in bytes) thanks to PSRAM
#define MQTT_METER_QUEUE_SIZE (64 * 1024) // Size in bytes to allocate to PSRAM
#define MQTT_GRID_QUEUE_SIZE (64 * 1024) // Size in bytes to allocate to PSRAM (~34 min of 500 ms points); overflow drops oldest
#define QUEUE_WAIT_TIMEOUT 100 // Amount of milliseconds to wait if the queue is full or busy
#define MQTT_ALARM_QUEUE_SIZE (4 * 1024) // Size in bytes to allocate to PSRAM
#define MQTT_ALARM_TYPE_BUFFER_SIZE 32 // Short machine-readable identifier, e.g. "zero_crossing_timeout" - not a free-text message
#define MQTT_ALARM_EVENT_ID_BUFFER_SIZE 17 // 16-char lowercase-hex token (see generateHexToken, utils.h) + null terminator
#define OTA_TASK_NAME "ota_task"
#define OTA_TASK_STACK_SIZE (12 * 1024) // Has to be big to allow for the presigned S3 URL to be handled
#define OTA_TASK_PRIORITY 5
#define OTA_HTTPS_BUFFER_SIZE_TX (2 * 1024)
#define OTA_PRESIGNED_URL_BUFFER_SIZE (4 * 1024) // The presigned S3 URL can be very long
#define OTA_SIGNATURE_HASH_CHUNK_SIZE 4096 // Chunk size for streaming the downloaded partition through SHA-256 before signature verification
#define MQTT_OTA_SIZE_REPORT_UPDATE (128 * 1024)
#define OTA_DOWNLOAD_MAX_ATTEMPTS 5
#define OTA_DOWNLOAD_RETRY_INITIAL_INTERVAL (2 * 60 * 1000)
#define OTA_DOWNLOAD_RETRY_MAX_INTERVAL (15 * 60 * 1000)
#define OTA_DOWNLOAD_RETRY_MULTIPLIER 2
#define OTA_STATUS_DETAIL_VALUE_BUFFER_SIZE 24
#define OTA_VALIDATION_TASK_NAME "ota_validation_task"
#define OTA_VALIDATION_TASK_STACK_SIZE (6 * 1024)
#define OTA_VALIDATION_TASK_PRIORITY 2
#define OTA_VALIDATION_TIMEOUT (5 * 60 * 1000) // Stable operation before marking OTA as successful
#define OTA_VALIDATION_CHECK_INTERVAL (10 * 1000) // Check periodically during validation period
#define MQTT_PREFERENCES_OTA_JOB_ID_KEY "ota_job_id"
#define MQTT_PREFERENCES_OTA_PENDING_KEY "ota_pending"
#define MQTT_PREFERENCES_OTA_EXPECTED_SHA256_KEY "ota_sha256" // Expected firmware SHA256 for validation
#define MQTT_BUFFER_SIZE (9 * 1024)
#define MQTT_SUBSCRIBE_MESSAGE_BUFFER_SIZE (32 * 1024) // PSRAM buffer for MQTT subscribe messages (reduced for efficiency)
#define CERTIFICATE_BUFFER_SIZE (16 * 1024)   // PSRAM buffer for certificate storage (was 4KB)
#define CRASH_PUBLISH_COREDUMP_FIELD_OVERHEAD sizeof(",\"coreDump\":\"\"")
#define DEFAULT_CLOUD_SERVICES_ENABLED false // Always off by default, and enabled only explicitly by the user
#define DEFAULT_SEND_POWER_DATA_ENABLED true // Send all the data by default
#define DEFAULT_SEND_GRID_DATA_ENABLED false // Off by default; the cloud enables it per device
#define DEFAULT_MQTT_LOG_LEVEL_INT 2 // Default minimum log level for MQTT publishing (INFO = 2)
#define MQTT_MAX_INTERVAL_METER_PUBLISH (60 * 1000) // The maximum interval between two meter payloads
#define MQTT_GRID_PUBLISH_ALIGN_SECONDS 60 // Grid batches publish aligned to wall-clock minute boundaries, not a relative interval
#define MQTT_ENERGY_PUBLISH_ALIGN_SECONDS 60 // Energy snapshots publish aligned to wall-clock minute boundaries, not a relative interval
#define MQTT_ENERGY_PUBLISH_DEADLINE_SECONDS (CHANNEL_MAX_GAP_MS / 1000)
#ifdef ENV_DEV
#define MQTT_MAX_INTERVAL_SYSTEM_DYNAMIC_PUBLISH (60 * 1000)
#define MQTT_MAX_INTERVAL_STATISTICS_PUBLISH (60 * 1000)
#else
#define MQTT_MAX_INTERVAL_SYSTEM_DYNAMIC_PUBLISH (60 * 60 * 1000)  // 1 hour since the data does not change frequently (and sent on reboot/reconnection anyway)
#define MQTT_MAX_INTERVAL_STATISTICS_PUBLISH (6 * 60 * 60 * 1000)  // 6 hours since they are cumulative counters (and sent on reboot/reconnection anyway)
#endif
#define MQTT_MAX_INTERVAL_CRASH_PUBLISH (60 * 1000)
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

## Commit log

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2025-11-07 fix: add minimum current threshold on invalid readings with low current to improve reliability and avoid rebootings on first setup
    [ade7953.cpp, ade7953.h]
2025-11-10 Feature/udp-logs-to-custom-ip + better waveform for three-phase (#60)
    * feat: implement waveform analysis python script
    * feat: add waveform analysis libs to uv
    * feat: add UDP log destination management and API endpoints for retrieval and configuration
    * feat: enhance waveform analysis with phase shift handling and command-line interface
    * fix: replace strncpy with snprintf for safer string handling in getUdpDestination
    * feat: enhance waveform capture with zero-crossing detection for full cycles and improved error handling in API
    * feat: add complete cycles count and enhance waveform analysis output
    * feat: enhance waveform analysis with detailed phase shift calculations and improve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
    [ade7953.cpp, ade7953.h, constants.h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]
2025-11-12 Fix/energy accumulation precision (#64)
    * fix: change energy values from float to double to fix sum issues and for improved precision in large energy calculations
    * fix: implementation of new double in all other places (modbus, api)
    * fix: implement backward compatibility for energy values migration from float to double
    * fix: increase log queue sizes for improved logging capacity
    * fix: update default configuration gain values to calibrated settings
    * fix: update roundToDecimals function to return double and adjust Modbus handling for energy values
    [ade7953.cpp, ade7953.h, mqtt.h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]
2025-11-12 fix: persistance of mqtt log level across reboots and immediate initialization to ensure all logs are sent via MQTT
    [mqtt.cpp]
2025-11-14 Fix/safer connectivity check (#65)
    * fix: enhance build version logging to include environment context
    * fix: update NTP server to use raw Google IP for improved connectivity
    * fix: lighter connectivity check using google dns raw IP (avoid crash when dns fails)
    * Update source/include/customtime.h
    ---------
    [customwifi.h, main.cpp, mqtt.cpp]
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2025-11-18 Feature/better mqtt ota validation (#71)
    * feat: ota validation happens after reboot and stable period
    * feat: version override for s3 upload script
    * feat: ota validation through sha256 check
    * fix: use of char instead of dynamic string in logging for test connectivity
    * fix: increase ota validation task
    * fix: removed non-usable rollback marking function (arduino does not support it)
    * fix: better handling of failed states during OTA validation
    [mqtt.cpp, mqtt.h]
2025-11-18 Improve WiFi reconnection time after power reset (#75)
    * Implement extended WiFi timeout for power resets
    - Add detection for power-related resets (ESP_RST_POWERON and ESP_RST_BROWNOUT)
    - Increase WiFi connection timeout from 10s to 60s after power reset
    - Log when extended timeout is used to help with debugging
    - Helps handle case where router is also rebooting after power outage
    * Final verification complete
    * Remove unused CodeQL detected source root file
    * feat: increased timeout after reboot to 5 minutes
    --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
    [customwifi.h]
2025-11-19 Implement round-robin high-priority channel reading for multiplexed channels (#72)
    * Add high-priority field to backend (ADE7953 and API levels)
    * Fix round robin algorithm to visit all channels with proper HP/LP tracking
    * Update swagger documentation and ensure backward compatibility for highPriority field
    * fix: it finally works the scheduling
    * feat: blocked high priority check on channel page for channel 0
    * feat: default high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
    [ade7953.cpp, ade7953.h, swagger.yaml]
2025-11-24 Feature/telemetry open source (#77)
    * fix: correctly fetching firmware instead of bootloader from githu releases
    * docs: added tiny 16x16 icon
    * feat: added open source telemetry
    * docs: added transparency infos for telemetry
    * feat: use aws ca to validate connection for telemetry
    * refactor: moved constants to correct place, added proper libraries in the header
    * docs: added public ip for clarity
    [customwifi.h]
2025-11-26 Feature/dual wifi ssid (#78)
    * feat: add WiFi credential constants and setCredentials API declaration
    - Add WIFI_SSID_BUFFER_SIZE and WIFI_PASSWORD_BUFFER_SIZE constants
    - Separate WiFi-specific buffer sizes from generic USERNAME/PASSWORD sizes
    - Add setCredentials() API to CustomWifi namespace for programmatic WiFi switching
    * feat: implement setCredentials function for programmatic WiFi switching
    - Add setCredentials() implementation with SSID/password validation
    - Disconnect from current network and attempt connection to new credentials
    - Auto-save credentials on successful connection via WiFi.persistent(true)
    - Fall back to previous network if new credentials fail
    - Reset reconnection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
    [constants.h, customwifi.h, swagger.yaml]
2025-11-26 Feature/offline time sync (#80)
    * feat: online no longer mandatory and forces reconnection
    * feat: added manual time sync from API/frontend
    [customserver.h, swagger.yaml]
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2026-01-06 Better WiFi diagnostic in fallback mode (#91)
    * feat: add hostname for easier recognizability in router devices
    * feat: first working fallback information
    * typo: fix in html
    * docs: better description of why esp.restart in main setup
    * fix: static cast to avoid compilation warnings
    * fix: finally good working diagnostic page
    * docs: added comments to removed todos
    * fix: minor stuff
    * Update source/src/customwifi.cpp
    * fix: minor stuff
    * fix: static casting
    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
    [ade7953.cpp, crashmonitor.h, customwifi.h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]
2026-02-15 Feature/production battery channels (#96)
    * fix: better colors for charts
    * feat: add channel grouping, parent group, and production/battery flags
    - Extended ChannelData struct with groupId, groupLabel, parentGroup, isProduction, isBattery
    - Added new preferences keys for persistent storage
    - Updated channelDataToJson and channelDataFromJson for serialization
    - Updated validation to support new fields with backward compatibility
    - Default groupId equals channel index, parentGroup defaults to 255 (root)
    * docs: update Swagger API docs with channel grouping and flags
    - Added groupId, groupLabel, parentGroup to ChannelData schema
    - Added isProduction and isBattery flags to ChannelData schem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
    [ade7953.cpp, ade7953.h, chart-helpers.js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]
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2026-03-03 fix: critical error in clamping the active power, making it go positive always
    [ade7953.cpp, ade7953.h]
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2026-03-08 Fix incorrect autosufficiency/self-consumption KPIs in non-daily views; split grid and battery bars (#123)
    * Fix incorrect non-daily autosufficiency: separate grid import/export bars and add KPI tooltips
    * Apply same split logic to battery charge/discharge: separate KPI arrays and chart bars
    * feat: added total energy below pie chart
    * fix: show total energy when switching from balance
    * feat: added gif to readme in homepage
    ---------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
    [chart-helpers.js]
2026-05-09 Feature: handle different PCB versions (v6 hardware profile) (#126)
    * feat: add hardware profile system for runtime PCB version detection
    Introduce HardwareProfile struct and initHardwareProfile() that reads
    eFuse to select the correct pin configuration and voltage divider
    values at runtime. main.cpp now uses globalHwProfile-> instead of
    hardcoded pin defines. pins.h still exists for other modules.
    Bump firmware version to 2.0.0.
    * refactor: replace pins.h with hardware profile in all modules
    Replace #include "pins.h" with hardware_profile.h in ade7953.h.
    Use globalHwProfile->voltageDividerR1/R2 instead of hardcoded
    VOLTAGE_DIVIDER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
    [partitions.csv, partitions_esp32s3_n16r2.csv, pick_and_place_main_board.csv]
2026-05-09 docs: polish documentation and comments for v2.0.0
    Sweep through user-facing docs and source comments ahead of the 2.0.0
    release. All changes are non-functional (text, comments, config comments,
    tooltip strings) so they are batched into a single commit.
    - Remove 26 em dashes across READMEs, HTML UI, source/header comments and
    Python helpers per the project's ASCII-only rule. Each occurrence is
    rewritten rather than mechanically substituted.
    - Fix Modbus per-channel register doc in source/html/integrations.html so
    the JS bound and the prose both reflect 0..15 on PCB v6.1, with a note
    tying the limit to MAX_CHANNEL_COUNT and globalHwProfile.
    - Reword the AWS-secrets contradiction in s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
    [ade7953.cpp, ade7953.h, mqtt.cpp]
2026-05-10 fix: v2.0.0 instability - pin platform to recover internal heap (#139)
    * fix(build): pin pioarduino platform to 55.03.32 to recover internal heap
    Bumping to 55.03.38 (Arduino Core 3.3.8 / ESP-IDF v5.5.4) shrank the total
    internal heap by ~50 KB on ESP32-S3-N16R2 (~320 KB -> ~270 KB). With the
    v2.0.0 request workload that headroom loss caused LWIP/AsyncTCP to silently
    fail PBUF allocations under web/modbus traffic: the device looked alive
    (router still saw it, ADE7953 kept reading) but ping/HTTP/MQTT/UDP all
    silently dropped until WiFi keepalive timeout fired a re-association
    ~5-10 min later. No crash, no warning, just unreachable.
    Pinning back to 55.03.32 (Arduino Core 3.3.2 / ESP-IDF v5.5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
    [ade7953.h, buttonhandler.h, customserver.h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]
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2026-05-12 Release/v2.0.0 (#140)
    * fix: critical error in clamping the active power, making it go positive always
    * Documentation/pcb v6.0 (#120)
    * Update ESP32-S3 module compatibility notes
    Clarified compatibility notes for ESP32-S3 modules regarding PSRAM usage and GPIO conflicts.
    * Documentation/pcb v6.1 (#121)
    * docs: typos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
    [BOM.csv, PickAndPlace - Main board.csv, PickAndPlace - Top board 1.csv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]
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2026-05-21 docs(manual): rewrite installation manual, add IT/DE/FR translations, CE compliance docs (#150)
    * docs(installation): first very draft at root
    * updating installation manual
    * docs(installation): moved docs
    * fix(script): removed legacy builds
    * docs(installation): finalized review
    * docs(installation): document auto-polarity detection feature
    Add callouts explaining that EnergyMe automatically detects and corrects
    reversed CTs on first channel activation, eliminating the need to reopen
    the panel for clamp orientation issues. Clarifies that manual Reverse
    toggle is available as a fallback when needed.
    * refactor(docs): rename d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
    [bom_main_board.csv, bom_top_board_1.csv, bom_top_board_2.csv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]
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2026-05-22 fix(ade7953): close wdrr scheduler starvation (#149) (#152)
    * fix(ade7953): refund channel deficit on discarded reads
    Root cause of issue #149: _findNextActiveChannel decrements
    _channelDeficit[i] by 1.0 at selection, but on a discarded read
    (LOAD-discard, auto-polarity flip, validation failure, etc.)
    _readMeterValues returns false and the decrement is never refunded.
    A channel locked in a discard loop drifts ever-more-negative in the
    deficit array and starves out of the scheduler entirely.
    The fix captures _processChannelReading's return value at its sole call
    site in _handleCycendInterrupt and refunds the deficit on failure.
    Single-site change keeps the refund logic in one place instead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
    [ade7953.cpp, ade7953.h]
2026-05-22 fix: never permanently disable custommqtt/influxdb on failures (#153)
    * fix(custommqtt): never permanently disable on failures
    Closes #148 (custommqtt side). Auth errors, max reconnect attempts
    and max failed publishes no longer disable the integration; the task
    keeps retrying behind the existing exponential backoff (now capped at
    1h).
    * fix(influxdb): never permanently disable on failures
    Closes #148 (influxdb side). 401/403 and max consecutive failures no
    longer disable the integration; the task keeps retrying behind
    exponential backoff. Bumped max retry interval from 10m to 1h to match
    custommqtt.
    [custommqtt.h, influxdbclient.h]
2026-05-22 fix(server): stream embedded static assets without heap copy (#156)
    * fix(ade7953): lower scheduler starvation log to debug
    Starvation events can occur legitimately when high-power channels coexist
    with static 0W channels - not an error condition, so demote from WARNING
    to DEBUG to reduce log noise.
    * fix(server): stream embedded static assets without heap copy
    beginResponse(int, const char*, const char*) constructs AsyncBasicResponse,
    which copies the entire file into a heap-allocated String on every cache
    miss. With the browser firing ~15 parallel asset requests against a
    post-OTA fragmented heap, concurrent String allocations can corrupt each
    other's backing buffers - producing valid-l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
    [ade7953.cpp]
2026-05-30 fix(server): use GitHub latest-release API for update check
    The periodic check fetched the full /releases array; over TLS the large
    body was truncated and ArduinoJson failed with IncompleteInput, so the
    device wrongly assumed it was already up to date. Switch to the
    /releases/latest endpoint (single object, excludes drafts/prereleases).
    Also render the release date in the browser local timezone, and add a
    FORCE_COMMUNITY_MODE build flag to exercise community mode on a
    provisioned board without wiping its NVS certs.
    Closes #163
    [constants.h, hardware_profile.cpp]
2026-05-30 feat: configurable static IP with automatic DHCP fallback (#166)
    * feat(wifi): add network config module for static ip, channel and tx power
    * feat(server): add network configuration rest endpoints
    * docs(swagger): document network configuration endpoints
    * feat(ui): add network configuration section to config page
    * fix(wifi): also reset network config on wifi reset for clean dhcp recovery
    * refactor(wifi): drop channel/tx-power and harden static-IP dhcp fallback
    Remove the WiFi channel and TX power options (useless for an STA client).
    Replace the esp_ping gateway probe and live WiFi.config(0,0,0) revert (both
    crashed) with restart-to-DHCP recovery: a boot-fail backstop counter forces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
    [customserver.h, customwifi.h, swagger.yaml]
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2026-06-07 fix(frontend): homepage power flow for any source/load combination + negative Other in charts (#172)
    * fix(frontend): render power flow for any source/load combination
    The homepage diagram always drew the grid node, so a device without a
    grid channel showed a ghost grid at 0 W, and only-loads setups left
    orphan connector stubs. Draw only the nodes that exist:
    - grid node hidden when no grid channel (slot reserved when other
    sources exist so the junction stays aligned with solar/battery)
    - house total falls back to the sum of monitored loads when no source
    is present
    - connectors hidden (not just deactivated) when their node is absent
    - home flow no longer animates into a 0 W house on n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
    [chart-helpers.js]
2026-06-09 feat(ade7953): host-testable meter logic + conduction-gated CT-reversal & grid/battery priority (#173)
    * feat(ade7953): detect reversed CTs by net sign-vote, clamp instead of discard
    Replace the one-shot auto-polarity flip with a robust per-channel detector
    so installers can clip CTs without minding orientation. Assumes the phase is
    configured correctly (sign of active power is then meaningful); phase
    detection is a separate concern.
    - Net sign-vote: while a channel is armed, accumulate +/-1 per conducting
    reading (activePower != 0, i.e. survived the no-load/low-pf/validation
    filters). Decide at +/-POLARITY_DETECT_VOTE_THRESHOLD. Magnitude-independent,
    so a steady -4 W reversed CT is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
    [ade7953.cpp, ade7953.h]
2026-06-10 feat: live per-phase preview and PF readout for installer phase assignment (#177)
    * feat(ade7953): re-arm ct-polarity detection on phase change
    * feat(channel): show live power factor next to active power
    * feat(channel): live per-phase preview for 3-phase installs
    From one published reading (P, Q, S) the page reconstructs the
    voltage-current angle and shows what active power and PF every phase
    choice would yield, so the installer picks the matching phase instead
    of guessing from the breaker panel. Software-only: no wizard, no load
    toggling, no firmware detection (issue #174). Channel 0 is the voltage
    reference, so it shows an explanatory notice instead of a preview.
    * fix(channel): conc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
    [ade7953.cpp, ade7953.h]
2026-06-10 feat(issues): runtime device issue registry with isa-18.2-lite lifecycle (#178)
    * feat(issue-logic): pure issue lifecycle and predicate logic for the issue registry
    * test(issue-logic): host unit tests for lifecycle, evidence helpers and predicates
    * feat(ade7953): per-channel issue facts and forensic ct-flip log
    * feat(mqtt): expose cloud connection state for issue registry
    * feat(custom-mqtt): expose connection state and consecutive failure count
    * feat(influxdb): expose enabled state for issue registry
    * feat(wifi): expose static ip fallback facts
    * feat(issues): runtime-only issue registry with isa-18.2-lite lifecycle
    * feat(issues): wire registry into boot, shutdown and task inf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
    [ade7953.cpp, ade7953.h, custommqtt.h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]
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2026-06-13 fix(ade7953): lower conduction gate for small reversed loads (#180) (#182)
    * fix(ade7953): lower conduction gate so small reversed loads vote and flip
    Introduces MINIMUM_CURRENT_RATIO_CONDUCTING (0.0003 of CT rating) as a
    separate, lower threshold used only by the polarity-vote and WDRR-armed-
    boost path. The old MINIMUM_CURRENT_RATIO_VALIDATION (0.001) was set to
    stop ADE7953 offset-noise at ~0 A from voting a false reversal, but it
    was high enough (~7 W on a 30 A CT) to also exclude small real loads such
    as the 2.5 W / 11 mA case from #180, causing them to sit at a constant 0
    and never self-correct.
    With the new gate at 0.0003 (~2 W on a 30 A CT), small reversed loads now
    earn the polari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
    [ade7953.cpp, ade7953.h]
2026-06-13 feat(utils): add DurationFormat::humanizeDuration helper (#185)
    * feat(utils): add DurationFormat::humanizeDuration helper
    Pure, dep-free C++ formatter: ms -> "850 ms" / "2.4 s" / "3 min" / "5 h" / "2 d".
    Lives in lib/duration_format/ so it compiles on the native host.
    Closes #179
    * test(duration_format): 22 Unity host tests for humanizeDuration
    Covers all range boundaries (ms/s/min/h/d), edge values at thresholds,
    null/zero-size buffer safety. Run with: pio test -e native (from WSL).
    * feat(custommqtt,mqtt,influxdb): humanize retry backoff in status/log strings
    Replace raw "%llu ms" with DurationFormat::humanizeDuration in:
    - custommqtt.cpp: user-visible status string ("Retrying in X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
    [ade7953.cpp, buttonhandler.cpp, mqtt.cpp]
2026-06-14 fix(integrations): align status display, fix issue detection, and UX polish (#186)
    * fix(integrations): align custom MQTT and InfluxDB status display
    - Prefix MQTT element IDs (statusIcon -> customMqttStatusIcon etc.) to
    avoid collision risk with other page elements
    - Fix MQTT red state: was checking status === "Disconnected" but backend
    emits "Connection failed: ..."; now uses .toLowerCase().includes("failed")
    matching InfluxDB's approach
    - Align error matching: MQTT startsWith("Error") -> includes("Error")
    - Drop dead InfluxDB success strings: only "Data sent successfully" is
    ever emitted by the backend; "Upload successful", "Connection successful"
    and "Credentials valid" were u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
    [ade7953.cpp, buttonhandler.cpp]
2026-06-14 fix(waveform): apply reverse flag to samples and correct phase-shift direction
    Negate current samples when the channel reverse flag is set so the waveform
    shows actual current direction rather than CT orientation. Fix voltage shift
    from i-shiftSamples to i+shiftSamples: PHASE_2 leads by +120 so the voltage
    must be advanced (future samples), not delayed (past samples).
    [ade7953.cpp]
2026-06-14 fix(ade7953): correct PHASE_2/PHASE_3 angle convention to IEC standard (#188)
    PHASE_2 was +120 deg and PHASE_3 was -120 deg, the inverse of European IEC
    positive sequence (L1=0, L2=-120, L3=+120). This caused customers to
    configure channels as 1-3-2 instead of 1-2-3 for standard 3-phase installs.
    Swap the angles: PHASE_2=L2(-120 deg), PHASE_3=L3(+120 deg). NVS enum values
    are unchanged, but existing 3-phase devices configured with the 1-3-2 workaround
    must be reconfigured to 1-2-3 after updating.
    Extract Phase enum and rotation helpers to lib/phase_utils (Arduino-free) so
    the convention is host-testable. 18 unit tests added including regression
    guards that will fail if the convention is ac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
    [ade7953.cpp, ade7953.h]
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2026-06-17 fix(charts): correct battery charge/discharge convention in balance chart and KPIs
    rawImported = discharge (positive, battery supplies home)
    rawExported = charge (magnitude of negative current, home fills battery)
    Both updateBalanceChart and updateEnergyKPIs had these swapped, causing
    the balance chart to show charging at night and discharging during the day.
    [chart-helpers.js]
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2026-07-01 fix(mqtt): accept comma-separated channels string in energy_reset (#193)
    * feat(shadow-logic): add parseChannelList comma-separated channel parser
    AWS IoT Commands can only deliver channels as a string, never a JSON
    array, so energy_reset needs a CSV parser alongside the existing
    per-index checks. Read-only scan (no buffer copy/mutation), best-effort
    per token, 12 new native tests (174/174 passing).
    Claude-Session: https://claude.ai/code/session_01SLnimJ2KQzVPEpzcyUejfv
    * fix(mqtt): accept comma-separated channels string in energy_reset
    AWS IoT Commands params are string-typed end-to-end, so the cloud could
    never actually send the J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
    [mqtt.cpp]
2026-07-04 feat(ade7953): grid frequency + voltage telemetry edge pipeline (#194)
    * chore(openspec): add grid-telemetry-edge change proposal
    Claude-Session: https://claude.ai/code/session_01H9Gussj5fmYfpy5FifipLQ
    * chore(openspec): finalize grid payload contract as bare triplet array
    Claude-Session: https://claude.ai/code/session_01H9Gussj5fmYfpy5FifipLQ
    * chore(openspec): fix grid rule names to env-guarded convention
    Claude-Session: https://claude.ai/code/session_01H9Gussj5fmYfpy5FifipLQ
    * chore(openspec): resolve grid publish qos to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
    [ade7953.cpp, ade7953.h, buttonhandler.cpp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]
2026-07-05 fix(mqtt): align grid publish to wall-clock minute marks
    The grid publish trigger was a relative "60s since last publish"
    timer, drifting from real wall-clock boundaries depending on boot
    time and reconnects. Replace it with an absolute wall-clock deadline:
    _checkIfPublishGridNeeded() schedules the next minute boundary via
    MqttGridSchedule::nextAlignedBoundarySeconds() and fires on
    now >= deadline (not exact equality, so a delayed loop tick still
    catches the boundary). _publishGrid() recomputes the next deadline
    from the current time on success rather than old_deadline + 60, so a
    reconnect after a long outage resyncs cleanly instead of bursting.
    Verified on dev device .174 via UDP log captu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
    [mqtt.cpp, mqtt.h]
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
